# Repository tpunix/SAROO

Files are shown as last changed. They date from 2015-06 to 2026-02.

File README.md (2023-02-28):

### SAROO is a HDLoader for SEGA Saturn.

SAROO是一个土星光驱模拟器。SAROO插在卡槽上，实现原主板的CDBLOCK的功能，从SD卡装载游戏并运行。
SAROO同时还提供1MB/4MB加速卡功能。

--------
### 一些图片

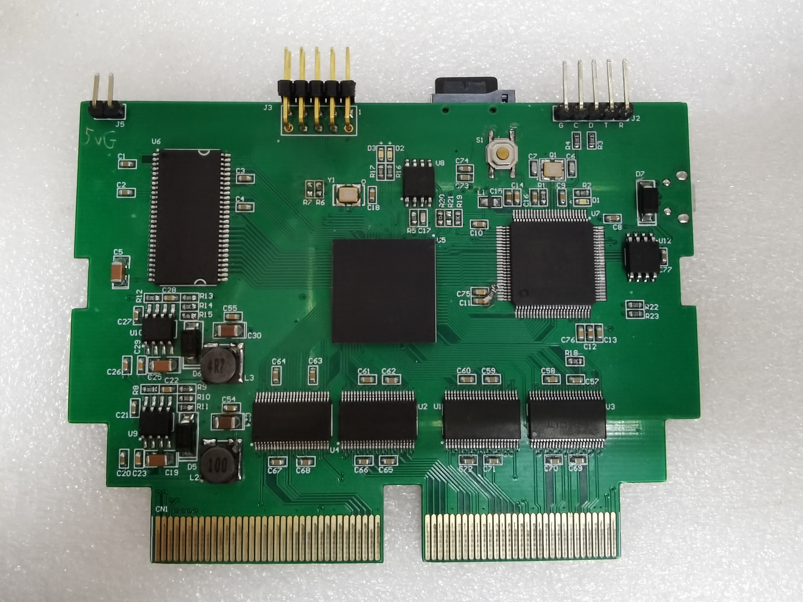
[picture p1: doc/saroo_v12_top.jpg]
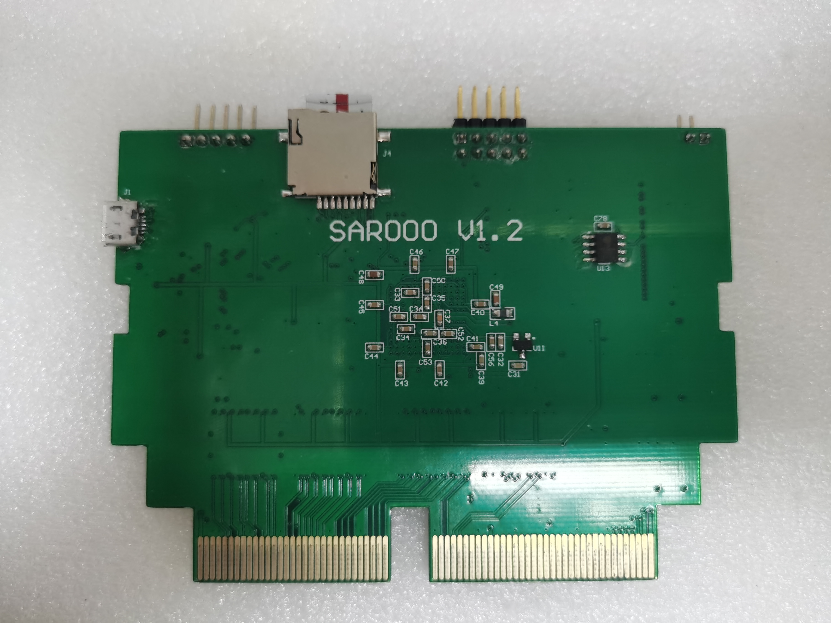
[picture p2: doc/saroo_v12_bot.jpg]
  
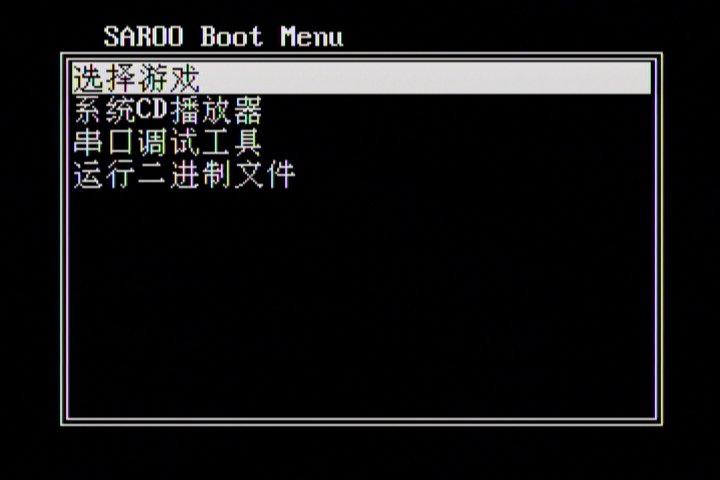
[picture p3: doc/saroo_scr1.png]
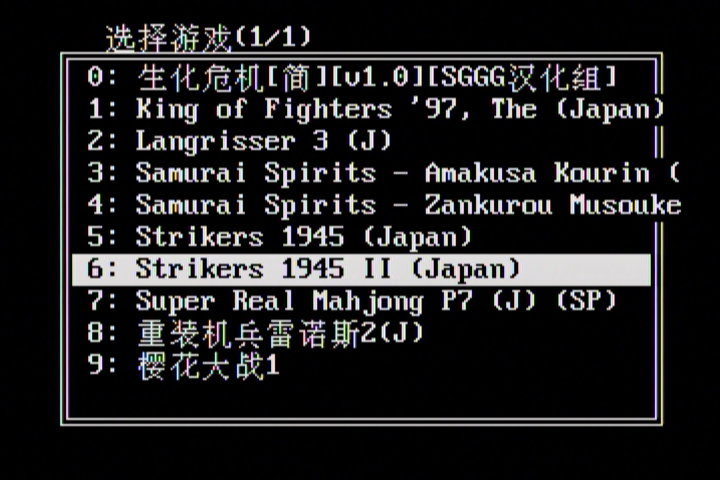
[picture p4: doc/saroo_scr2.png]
  
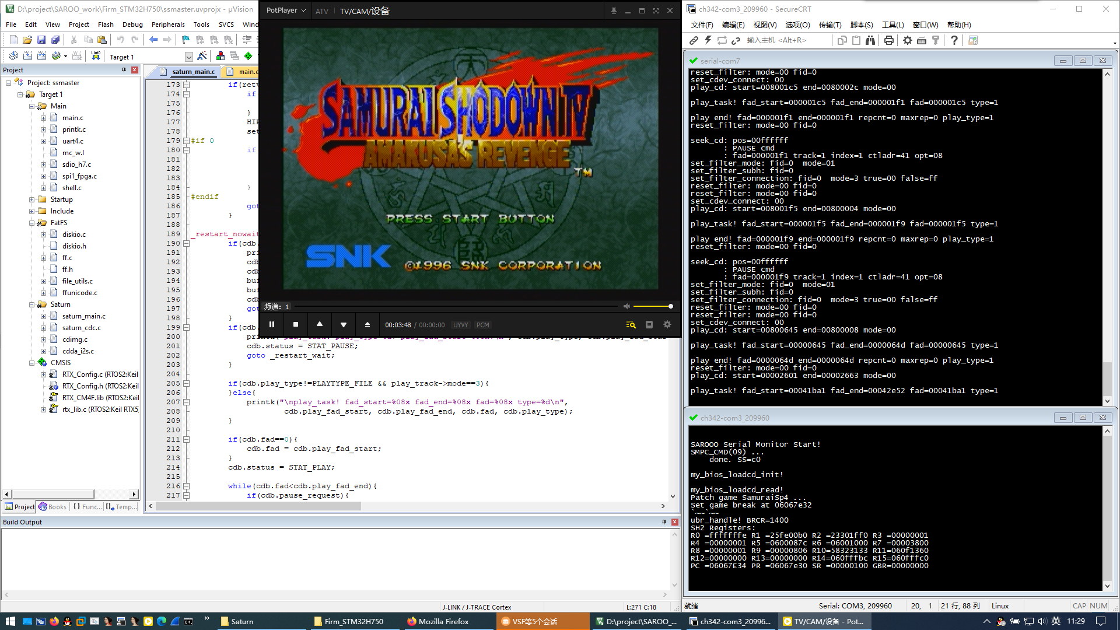
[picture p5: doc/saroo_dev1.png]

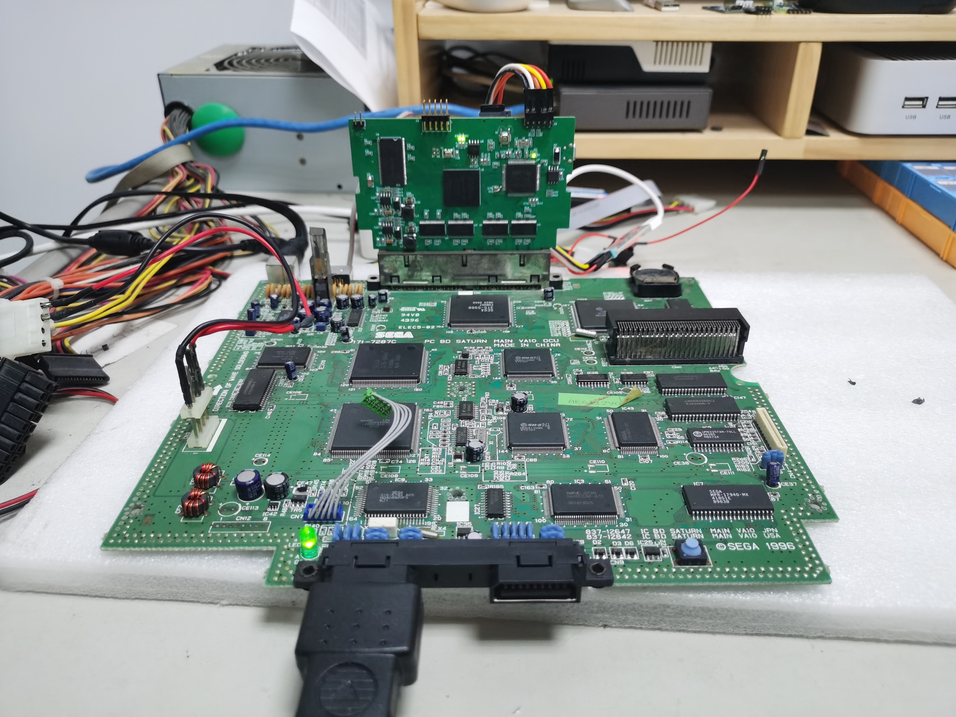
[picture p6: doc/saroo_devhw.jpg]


--------
### 开发历史

#### V1.0
最初的SAROO仅仅是在常见的usbdevcart上增加了一个usbhost接口。需要对游戏主程序进行破解，将对CDBLOCK的操作转化为对U盘的操作。
这种方式需要针对每一个游戏做修改，不具备通用性。性能与稳定性也有很大问题。只有很少的几个游戏通过这种方式跑起来了。
(V1.0相关的文件未包括在本项目中)

#### V1.1
新版本做了全新的设计。采用FPGA+MCU的方式。FPGA(EP4CE6)用来实现CDBLOCK的硬件接口，MCU(STM32F103)运行固件来处理各种CDBLOCK命令。
这个版本基本达到了预期的目的，也有游戏几乎能运行了。但也有一个致命的问题: 随机的数据错误。在播放片头动画时会出现各种马赛克，
并最终死掉。这个问题很难调试定位。这导致了本项目停滞了很长时间。

#### V1.2
1.2版本是1.1版本的bugfix与性能提升，使用了更高性能的MCU:STM32H750。它频率足够高(400MHz)，内部有足够大的SRAM，可以容纳完整的CDC缓存。
FPGA内部也经过重构，抛弃了qsys系统，使用自己实现的SDRAM与总线结构。这个版本不负众望，已经是接近完美的状态了。
同时，通过把FPGA与MCU固件逆移植到V1.1硬件之上，V1.1也基本达到了V1.2的性能了。

--------
### 当前状态

测试的几十个游戏可以完美运行。  
1MB/4MB加速卡功能可以正常使用。  
SD卡支持FAT32/ExFAT文件系统。  
支持cue/bin格式的镜像文件。单bin或多bin。  
部分游戏会卡在加载/片头动画界面。  
部分游戏会卡在进行游戏时。  

--------
### 硬件与固件

原理图与PCB使用AltiumDesign14制作。  
V1.1版本需要飞线才能正常工作。不应该再使用这个版本了。  
V1.2版本仍然需要额外的一个上拉电阻以使用FPGA的AS配置方式。  

FPGA使用Quartus14.0开发。  

Firm_Saturn使用SaturnOrbit自带的SH-ELF编译器编译。  
Firm_v11使用MDK4编译。  
Firm_V12使用MDK5编译。  

--------
### SD卡文件放置

<pre>
/ramimage.bin      ;Saturn的固件程序.
/SAROO/ISO/        ;存放游戏镜像. 每个目录放一个游戏. 目录名将显示在菜单中.
/SAROO/update/     ;存放用于升级的固件.
                   ;  FPGA: SSMaster.rbf
                   ;  MCU : ssmaster.bin
</pre>

--------
一些开发中的记录: [SAROO技术点滴](doc/SAROO技术点滴.txt)

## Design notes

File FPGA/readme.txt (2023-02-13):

V12相对于V11的改动:

1: 移除了qsys相关的组件。qsys自带的SDRAM控制器效率比较低，仅支持单次读写。
2: 实现了一个简单的SDRAM控制器，支持4次突发读。
3: 实现了一个双主端口的总线架构，每个主端口有8字节的cache。
4: 由于CDC缓存放在STM32端，现在由STM32负责填充CDC FIFO。

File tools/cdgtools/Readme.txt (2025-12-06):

cdgplay
-------

简单的cdg文件播放器。将sub文件或cdg文件拖放上去即可播放。
默认是无延时全速播放。在命令行使用，可以附加一个速度参数，将以指定的倍率播放。

cdgfix
------

修复sub或cdg文件中的错误。大多数cdg文件从CD读出后，并没有进行纠错。这将导致播放时出现色块与花屏。
将文件拖放上去即可进行纠错并自动保存。会显示纠错的块的数量与不可修复的块的数量。

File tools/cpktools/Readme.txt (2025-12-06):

cpmk
----

这是一个SEGA cpk视频编码器。

它调用ffpmeg解码输入视频，然后调用windows自带的iccvid.dll编码cinepak视频，最后调用ffmpeg输出cpk格式的视频。
为什么不直接用ffmpeg呢? ffmpeg的编码速度实在是太慢了!!!

因为iccvid.dll只有32位版本，所以本程序与ffmpeg都必须在32位环境下编译。ffmpeg目录下提供了一个最简配置。
由于ffmpeg的cpk muxer有点小问题，这里还提供了一个修改过的版本，请自行替换。

编码控制有两种方式，通过"-q"设置编码质量，或者"-br"设置编码码率。
如果指定"-key"，可以设置关键帧的数量。如不指定，会自动选择合适的key。

cplayk
------

一个简单的cpk播放器。将cpk视频拖放上去即可播放。

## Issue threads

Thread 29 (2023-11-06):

Saroo KK DIY Retro game Store vs Saroo Retro game paradise

Jot666, 2023-11-06:

ShowmanBr, 2023-11-07:
I had purchase 4 units of the saroo from retro games paradise and all these working perfect. I have nothem to say about other stores!

cyo-the-vile, 2023-11-07:
Retro games paradise best vendor.

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

stakeshadow, 2023-11-07:
KK store price cheap. This is good. The quality may not good as the price. The card looks no clear. Same chip are not in one batch. It may second hand. And there are some grinding on top of chip. I wondering the quality may not good. One more issue is that KK store has write Japan in the ali express product photo. He wants to delude buyer. This is not honest.Retro game paradise saroo price may higher. It looks very clean on board. The chip are all same batch and new. The quality is good.

luisredo, 2023-11-07:
I received a unit that does not work, it indicates that the stm32 does not have a bootrom, I am already resolving it with the seller.

Offi1, 2023-11-07:
Had no Problems with seller " Retro game paradise". Updated cartridge around 4 times fine from august when i got it and still running fine.

williamdsw, 2023-11-07:
I 've bought mine on "Retro Game Paradise Store" and I didn't have problems to update firmware.

ShowmanBr, 2023-11-09:
> Also you might want to check this thread: https://bbs1-chinaemu-org.translate.goog/read-htm-tid-129500.html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

Boa noite William!

Vi que você postou aqui um arquivo txt que teoricamente traria mais compatibilidade para alguns jogos. Dentre esses jogo no arquivo vi o kof95, por acaso você conseguiu fazer ele funcionar com essa modificação?

williamdsw, 2023-11-09:
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

Sobre o KOF95, testei aqui e continua não rodando. Acho que só vai rodar quando implementarem o suporte ao cartucho ROm dele.
Sobre o arquivo txt, creio que você esteja se referindo ao **saroocfg.txt**, que é o arquivo de configuração do SAROO aonde é possível definir o idioma, algumas configurações de leitura para cada jogo (A velocidade de leitura do SAROO com o Saturn é alta, e isso causa alguns glitches e bugs em alguns jogos), além de poder definir um valor para memória do jogo (digo no sentido de hackear, colocar cheat).
Deixo um exemplo de como utilizei esse arquivo para rodar um jogo que tava bugado antes.
https://www.youtube.com/watch?v=gXqanPZoGLw

xvortex, 2023-11-09:
There is nothing wrong with KK's version. It has no hardware failures.
As I cleared out in the chat with KK, He's mistakenly flashed version 02 in the FPGA, which made it impossible to make a future updates of its firmware (firmware 02 does not release the flash pins).
Project SAROO is still young and such mistakes are typical for a young project. I recommend that everyone (even those with firmware 04) acquire an altera FPGA programmer (ByteBlasterII) and a stm32 programmer (stlink) in case of unforeseen problems with firmware in the future. Fortunately, both of these programmers are inexpensive.
As for FPGA firmware 02, I recommend updating it to 04 since, in addition to flash programming support, it contains some changes regarding fifo and so on.
I'll try to prepare a simple update package which I will upload soon.

Jot666, 2023-11-09:
I bought the Saroo at the KK retro game store and I didn't see any hardware defects or second-hand components, I found it very similar to the Saroo from the Retrô Paradise game store, I was able to run Metal Slug and Fatal Fury The Final Victory in the Retrô game store Store version I still can't make a saroo comparison because I haven't bought the product from the Retrô game Paradise store yet, the PCB from the KK DIY Retro game Store is in version 1.36 and the PCB from the Retrô game Paradise store is in version 1.35 but both products are Chinese and the only difference is the way they are installed and updated, both are experimental projects, both suppliers are the same thing, the only difference is that one of them chose to do Saroo his way and the other chose to follow the open source , no, I want to create a war here, but I think we should first do tests to highlight its disadvantages and advantages first and then give a verdict, many here are just based on fallacies what counts are the practical results we wouldn't have rockets going into space If we only take into account theories, I'm going to buy the Saroo at the Retrô Paradise game store and I want to make a comparison myself and see which of the two is the most efficient, if anyone here has both Saroo, do rigorous tests between the two everdrives. fair way and bring the results to clear everyone's doubts, if the alternative the Seller's saroo works then I think we are being deceived by unfounded rumors in logistical rivalry and not in real information.

LobAnovich, 2023-11-11:
> ...acquire an altera FPGA programmer (ByteBlasterII)....

На Алиэкспресс полно ByteBlaster (usb версия) и совсем немного предложений именно,якобы, ByteBlaster II. Внешне они ничем не отличаются от тех же ByteBlaster,коих полно. Но вот цена тех,что якобы ByteBlaster II, в пять раз выше. При том,что на наклейках корпусов последних,нет и намёка,на то,что это именно версия 2.
Что это, маркетинговый ход предприимчивых продавцов или это реально разные продукты,на разных чипах,просто с одинаковыми внешними корпусами и наклейками ?

xvortex, 2023-11-11:
Если хотите, чтобы он хоть как-то прошивл, берите самую дешевую версию. Если хотите, чтобы прошивал быстрее, с буферами и как надо, рекомендую версию от waveshare (в белом корпусе) - там все честно - и cpld есть и буфера. По названию выбирать бесполезно. Настоящего оригинального bb2 на али я не встречал.

Jot666, 2023-11-20:
I just want to thank those responsible and the developer, who brought an excellent project to light, but unfortunately people are taking credit for it and I don't agree.  As soon as possible I will buy from the official Paradise store, but I would like the developer to make his own store available to purchase the product in a 100% official way, as we must respect this master behind wonderful projects like saroo, we must be grateful and avoid investing in products that leave something to be desired and that break the developer's rules, in my case I bought it by accident, I ended up buying it wrong, I thought everything was the same, fortunately the saroo I bought is working very well, apart from updating via USB blaster which is more difficult, I don't want to recommend it to anyone, as I would be disrespecting the developer here and I will never do that, my thanks to him if he reads this message.

Closed 2023-11-22.

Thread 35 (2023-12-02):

Sega Saturn VA 0.8 USA is compatible with Saroo?

atds55, 2023-12-02:
I've been having some problems with Saroo on my VA 0.8 USA. The saroo is on firmware 231125, FPGA 05. But the same problem occurred with firmware 231111, FPGA 05. The revision of my saroo is 1.32F.
King of Fighters 96 and 97 have a problem with the sound FX, after some fights the sound has a problem.
Another problem I have is that after leaving some games for about 2 hours and 30 minutes to run alone, they freeze. This happened in Metal Slug, Garou Desetsu 3 (Fatal Fury 3) and Dungeons Dragons Shadow Over Mystara.
So I would like to know if anyone else with VA 0 USA has these problems or if any Saroo developers confirm that VA 0.8 USA is not fully compatible with Saroo.
The seller said that VA 0 is not well supported by Saroo.

https://github.com/tpunix/SAROO/assets/72902338/a5413c84-26f2-4e17-b97d-6b347a03a74a

https://github.com/tpunix/SAROO/assets/72902338/e415b58f-49db-4cf1-a27e-15337be51f62

https://github.com/tpunix/SAROO/assets/72902338/6cec5e20-3c8a-4cf7-a30b-cf48a7098011

https://github.com/tpunix/SAROO/assets/72902338/7c1abcff-c246-4d81-9b3d-502f88b9d7b1

https://github.com/tpunix/SAROO/assets/72902338/2d9f7d6b-e334-44c4-8109-6a0d4e83daa3

tzmwx, 2023-12-02:
Is the motherboard VA0.8?
What is the BIOS version?

atds55, 2023-12-02:
> Is the motherboard VA0.8? What is the BIOS version?

Yes, the board is VA 0.8.
The bios version is 1.00a.

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

atds55, 2023-12-05:
I managed to finish King of Fighters 96 once without having any problems with the game's audio.
I added it to saroocf.txt to run the kof96 game with sector_delay=8000, and that way I was able to finish the game once without any audio problems. Then I will try to finish the game again.

TheUndertakerPoland, 2023-12-05:
Ok thanks, I think it might be related with mobo revision. Defo not bios because I have most popular one 1.01

TheUndertakerPoland, 2023-12-05:
I can confirm changing this value from 4000 to 8000 resolved my sound glitches in UMK3

TheUndertakerPoland, 2023-12-05:
Is there any website how find this game ids to add in config file ?

TheUndertakerPoland, 2023-12-05:
> I managed to finish King of Fighters 96 once without having any problems with the game's audio. I added it to saroocf.txt to run the kof96 game with sector_delay=8000, and that way I was able to finish the game once without any audio problems. Then I will try to finish the game again.

My king of fighters 96 works without any problems. Most problem I have with wwf wrestlemania and mortal kombat games

TheUndertakerPoland, 2023-12-07:
> I managed to finish King of Fighters 96 once without having any problems with the game's audio. I added it to saroocf.txt to run the kof96 game with sector_delay=8000, and that way I was able to finish the game once without any audio problems. Then I will try to finish the game again.

Could you check guardian hero's. ? I have glitches almost instant after start playing

atds55, 2023-12-24:
Does anyone know where I can find the kof97.bin file?
http://bbs.chinaemu.org/read-htm-tid-129548.html

atds55, 2024-03-27:
@tzmwx
Could this be the saroo problem with my Saturn VA 0.8?
With fenrir, this console works perfectly even with games that use a 1MB or 4MB cartridge. The action replay and save cartridge also work well.
Thank you for your attention.

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

czapa86, 2024-04-07:
Same sound glitches on japanese va0 motherboard

tzmwx, 2024-04-09:
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

1.Currently, Saroo does not accept changing games after resetting the console. If you need to change games, it is recommended to use the power on/off mode.

2.I hope you can use my method to test KOF96: Use tape to remove the gold finger on the back of the saroo motherboard, pin 4.5.6 in the lower right corner (pin 7.8.9...can be removed if it is not used), and then insert the Saturn to run KOF96 , the game will have no background music and only hit sound effects. Please test whether there will be broken sound effects.

atds55, 2024-04-09:
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

I placed the tape in the indicated terminals in the same way as you showed in the second photo, and that way I didn't have any problems with the kof96's sound effect. I finished kof96 twice and kof97 once and I had no problem with the sound effect when putting on tape as you indicated.

atds55, 2024-04-26:
Hello. @tzmwx
Did you manage to discover anything with the duct tape test?
Thank you for your attention.

tzmwx, 2024-05-01:
> Hello. @tzmwx Did you manage to discover anything with the duct tape test? Thank you for your attention.

Perhaps it is because the external audio i2s data cable of the early SS motherboard was too close to the scspclk clock line, which may not be able to solve or may require modification of the motherboard to solve the problem.

https://youtu.be/dFbKYMtq3wE?si=qEavJywi40w9-Epi

tzmwx, 2024-05-05:
> Hello. @tzmwx Did you manage to discover anything with the duct tape test? Thank you for your attention.

If you are interested, you can test it according to my method: remove the CD board and use tape to shield the gold finger B6 according to the diagram Any pin, according to the width of the tape, other pins do not matter, ensure B5 is connected to the motherboard.

Reinstall the small board back into the motherboard for testing.
Note that the optical drive cannot be used at this time

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

atds55, 2024-05-07:
@tzmwx
I will carry out the test.
I cut a thin piece of tape and covered only the B6 gold finger, and noticed that the access LED stopped working.
Can I cover just B6 or do I need to cover other pins?

tzmwx, 2024-05-07:
The actual purpose is to cover B7. I said above that starting from B6 is to effectively stick to B7.

atds55, 2024-05-07:
> @atds55 The actual purpose is to cover B7. I said above that starting from B6 is to effectively stick to B7.

Now I think I've covered the B7 (gold finger) pin right.
Thanks.

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

tzmwx, 2024-05-08:
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

Have you tested it? Has the problem disappeared?

atds55, 2024-05-08:
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

Yes, I tested.
I played king of fighters 96 and 97 for a few hours yesterday and today and there were practically no audio problems. There was only a noise like a whistle in the last boss of King of Fighters 96, but this only happened three times, but when loading the next round of the fight, the noise disappeared and the sound returned to normal. But I finished king of fighters 96 2 more times and that noise didn't appear again.

I recorded a video showing the whistle-like noise that occurred in the last boss, but which disappeared when loading the next round. In other parts of the game this did not occur and the game worked perfectly. And as I said before, this only happened 3 times, the other times I faced the boss it didn't happen and the audio worked perfectly.

https://github.com/tpunix/SAROO/assets/72902338/d83a674e-7f14-4ced-8e82-06ed86589707

Thank you for your help.

tzmwx, 2024-05-08:
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

ok
Are you or your friend proficient in using a soldering iron?

atds55, 2024-05-08:
Depending on the type of welding, I can do it.

tzmwx, 2024-05-08:
> Depending on the type of welding, I can do it.

test：
Restore B7, remove C47 （capacitance）

atds55, 2024-05-09:
> > Depending on the type of welding, I can do it.
>
> test： Restore B7, remove C47 （capacitance）
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
RepeatingDigits, 2024-05-18:
I removed C47 on a HST-3200 (J V0) and at first it seemed fine, but after a race of Daytona USA the audio glitch persists.

atds55, 2024-05-19:
> Removi o C47 em um HST-3200 (J V0) e a princípio parecia bom, mas depois de uma corrida de Daytona EUA a falha de áudio persiste.
Did you also have audio problems with the tape on the B7 Daytona terminal?

tzmwx, 2024-05-19:
> I removed C47 on a HST-3200 (J V0) and at first it seemed fine, but after a race of Daytona USA the audio glitch persists.

OK
I hope you can be more specific: has the probability of problems decreased after removing C47?

RepeatingDigits, 2024-05-19:
> > I removed C47 on a HST-3200 (J V0) and at first it seemed fine, but after a race of Daytona USA the audio glitch persists.
>
> OK I hope you can be more specific: has the probability of problems decreased after removing C47?

Not really. After further testing I'd say it's about the same, actually. I just updated to latest firmware, too.

RepeatingDigits, 2024-05-19:
> > Removi o C47 em um HST-3200 (J V0) e a princípio parecia bom, mas depois de uma corrida de Daytona EUA a falha de áudio persiste.
>
> Did you also have audio problems with the tape on the B7 Daytona terminal?

I haven't tried the tape method. If I do that, I'll lose CD Audio, right?

tzmwx, 2024-05-19:
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

2 methods：
saroo A4，A5，A6 no CDaudio

CDmodule B7，CD audio OK

blorp-style, 2024-05-22:
To add, Die Hard Arcade (USA or Japan) has this issue the most consistently out of any game I’ve played, and could be considered a prime test subject.

TheUndertakerPoland, 2024-05-22:
I think wwf wrestlemania from midway has that issue (before mod) all the time after 20 sek of start, very good tester too, each version pal and ntsc, mortal kombat games too, but after few min

Wysłano z programu Outlook dla systemu Android<https://aka.ms/AAb9ysg>
________________________________
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

morpheu, 2024-05-22:
I will try both methods and post here some results also. Question: is there some risk to damage my console attempting doing such hw hacking ?

czapa86, 2024-05-22:
How is it possible that some games are affected but some not. For instance i played hi-octane with cdaudio music without any trouble but Die Hard arcade has glitches almost instantly?

TheUndertakerPoland, 2024-05-22:
After mod? Or before ?

Wysłano z programu Outlook dla systemu Android<https://aka.ms/AAb9ysg>
________________________________
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

czapa86, 2024-05-23:
Before mod. This issiue is inconsostent. One game working good, other not.

TheUndertakerPoland, 2024-05-23:
Yes I agree, worst game for me was wwf wrestlemania completely unplayable with enabled sound. After mod problem solved.

Wysłano z programu Outlook dla systemu Android<https://aka.ms/AAb9ysg>
________________________________
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

blorp-style, 2024-05-25:
I noticed an interesting thing today. The audio distortion is diminished to playable levels if you set the Saturn to mono instead of stereo. Tested this on Die Hard and Virtua Cop 2, which are the worst offenders I’ve seen so far.

TheUndertakerPoland, 2024-05-25:
I'm using mono and have not noticed that, maybe I should use stereo more often

Wysłano z programu Outlook dla systemu Android<https://aka.ms/AAb9ysg>
________________________________
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

blorp-style, 2024-05-25:
> I'm using mono and have not noticed that, maybe I should use stereo more often Wysłano z programu Outlook dla systemu Android<https://aka.ms/AAb9ysg>
> […](#)
> ________________________________ From: blorp-style ***@***.***> Sent: Saturday, May 25, 2024 3:45:31 AM To: tpunix/SAROO ***@***.***> Cc: TheUndertakerPoland ***@***.***>; Comment ***@***.***> Subject: Re: [tpunix/SAROO] Sega Saturn VA 0.8 USA is compatible with Saroo? (Issue #35) I noticed an interesting thing today. The audio distortion is diminished to playable levels if you set the Saturn to mono instead of stereo. Tested this on Die Hard and Virtua Cop 2, which are the worst offenders I’ve seen so far. — Reply to this email directly, view it on GitHub<[#35 (comment)](https://github.com/tpunix/SAROO/issues/35#issuecomment-2130695022)>, or unsubscribe<https://github.com/notifications/unsubscribe-auth/BENW5UONU3AJ2JJLXK7RBBLZD73MXAVCNFSM6AAAAABADWHLTOVHI2DSMVQWIX3LMV43OSLTON2WKQ3PNVWWK3TUHMZDCMZQGY4TKMBSGI>. You are receiving this because you commented.Message ID: ***@***.***>

Strange. Do you have a CR2032 battery installed in your Saturn and you have set the system to mono in the menu settings? Or have you achieved mono by some other method?

TheUndertakerPoland, 2024-05-25:
Mean with mono and stereo I have glitches:) well I had. After tape method with smal cdrom board no glitches at all. I'm using mono in bios settings. Because playing on
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

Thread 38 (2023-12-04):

请教下如何为FPGA下载程序？我使用USB BLASTER遇到一些问题

xiuhui-wang, 2023-12-04:
您好，很抱歉打扰您，我复刻了这个项目，但是在FPGA烧录程序这里遇到了问题。

1.我编译了 FPGA的固件，他提示成功，但是在我点PROGRAMMER按钮后，对话框显示 CANNOT OPEN FILE C:XXXX/FPGA/SSMASTER.CDF。。。。。
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

2. 但我最大的问题，我已经在这里研究了2天了，依然无法下载固件到FPGA中，我短接了 R6与R20，R7与R21是断开的，请问这是正确的么？

3.固件程序是要下载到U8中么？因为我现在不确定是我的FPGA芯片还是FLASH芯片的问题。。。。

很抱歉问这么简单的问题。。。

另外我检查了，3组电压，3.3V 2.5V 1.2V都存在。
也测试了50M的晶振工作正常。。。。

xiuhui-wang, 2023-12-04:
一直显示无法连接，请教一下有什么需要注意的地方的么？

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

xiuhui-wang, 2023-12-04:
我拆除了2个芯片，又外接了 3.3V 与1.2V的电源。。。 目前问题依旧，是不是我的下载器有问题呢？我用他下载 CPLD 是没问题的 可以下载。。。。 目前卡死在这里 几天了
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

tpunix, 2023-12-05:
FPGA固件是写到U8里面的，你把它拆了吗？
另外，先写MCU固件再看看。

xiuhui-wang, 2023-12-05:
mcu的固件我已经写进去了，会有一个 LED 一直闪啊闪的。 U8 拆不拆我都写不进去。。。。 有没有其他手段？ 比如我用 编程器直接写U8。。。。 我的 USB BLASTER 就是 淘宝最便宜的那种, 目前我又订购了一个编程器看看。。。。 目前不确定是 PCB板子，芯片或者编程器的问题。。。
U8 我使用 编程器检测过，虽然是翻新的但是可以正常工作。。。
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

tzmwx, 2023-12-05:
https://github.com/tpunix/SAROO/issues/2#issuecomment-1642263770

这里有用编程器直接烧录U8的固件

tpunix, 2023-12-05:
如果电压正常，晶振正常，还连不上，只能怀疑是芯片或焊接问题。

xiuhui-wang, 2023-12-06:
> 如果电压正常，晶振正常，还连不上，只能怀疑是芯片或焊接问题。

我已经确定我其中的一个 USB Blaster 不能使用，里面是WCH芯片的，上电只有一个LED红灯。虽然他可以下载CPLD，因为我又买了一套开发板。

xiuhui-wang, 2023-12-06:
目前我在研究芯片与焊接问题。。。 解决后我会更新。。。 R6 与 R20 接0R 是正确的吧？

tzmwx, 2023-12-06:
> 目前我在研究芯片与焊接问题。。。 解决后我会更新。。。 R6 与 R20 接0R 是正确的吧？

看我发你的连接，你直接编程器写好U8，看能不能点亮D2

xiuhui-wang, 2023-12-06:
> > 目前我在研究芯片与焊接问题。。。 解决后我会更新。。。 R6 与 R20 接0R 是正确的吧？
>
> 看我发你的连接，你直接编程器写好U8，看能不能点亮D2

我烧录了U8，使用编程器，但是遗憾的是D2 不能点亮。。。。
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

tzmwx, 2023-12-06:
确认烧录了ssmaster.rbf.bin点不亮D2说明可能flasb与fpga有电路不通，或者是FPGA芯片的问题。内存有没有贴回去？

要不就用串口接saroo右上角看一下数据，速度10000，看看报错数据

xiuhui-wang, 2023-12-06:
> 确认烧录了ssmaster.rbf.bin点不亮D2说明可能flash与fpga有电路不通，或者是FPGA芯片的问题。内存有没有贴回去？
>
> 要不就用串口接saroo右上角看一下数据，速度10000，看看报错数据

目前LED的状态 是 LED1 闪几下 然后 红色的 长亮
其他LED 不亮

SSMaster start! 20231203

No SDCARD insert!
disk_read: pdrv=0 sector=00000000 count=1
    retv=ffffffff
disk_read: pdrv=0 sector=00000000 count=1
    retv=ffffffff
disk_read: pdrv=0 sector=00000000 count=1
    retv=ffffffff
disk_read: pdrv=0 sector=00000000 count=1
    retv=ffffffff
Mount SDFS: 00000001

FPGA config done!
FPGA state:
    config done: 1
      init done: 1
         status: 1

disk_read: pdrv=0 sector=00000000 count=1
    retv=ffffffff
disk_read: pdrv=0 sector=00000000 count=1
    retv=ffffffff
disk_read: pdrv=0 sector=00000000 count=1
    retv=ffffffff
disk_read: pdrv=0 sector=00000000 count=1
    retv=ffffffff
disk_read: pdrv=0 sector=00000000 count=1
    retv=ffffffff
disk_read: pdrv=0 sector=00000000 count=1
    retv=ffffffff
disk_read: pdrv=0 sector=00000000 count=1
    retv=ffffffff
disk_read: pdrv=0 sector=00000000 count=1
    retv=ffffffff
NO bootrom file found!
stm32>

tzmwx, 2023-12-06:
红色是D2？
led1开机就闪烁是没有检测到tf卡
看你的串口信息应该是只要将（saroo主页右侧下载的）0.1版的ramimage.bin拷贝到fat32格式的tf卡根目录插上土星开机即可
第一次使用多插拔几次，确保接触良好

此卡有+5V电源输入时，你要确保D1（闪烁或常亮）和D2常亮基本就好了
D3必须进入saroo菜单后才会亮

xiuhui-wang, 2023-12-06:
> 红色是D2？ led1开机就闪烁是没有检测到tf卡 看你的串口信息应该是只要将（saroo主页右侧下载的）0.1版的ramimage.bin拷贝到fat32格式的tf卡根目录插上土星开机即可 第一次使用多插拔几次，确保接触良好
>
> 此卡有+5V电源输入时，你要确保D1（闪烁或常亮）和D2常亮基本就好了 D3必须进入saroo菜单后才会亮

SSMaster start! 20231203

SDCARD insert!
CMD_08: retv=00000000 resp0=000001aa
    V2.0: Yes
    SDHC: Yes
    Name: SS08G
    Blen: 512
    Blks: 15523840
    Size: 7761920 K
CMD_07: resp=00000700
CMD_16: resp=00000900
ACMD06: resp=00000920
CMD13: resp=00000900
Mount SDFS: 00000000

FPGA config done!
FPGA state:
    config done: 1
      init done: 1
         status: 1

这是我目前的状态，D1已经常亮，其他的都不亮。。。 难道是我D2损坏了？

tzmwx, 2023-12-06:
那估计你的fpga芯片问题，或者焊接不良

提醒一下，这卡的fpga和内存芯片绝对不要从tb去购买

xiuhui-wang, 2023-12-06:
> 那估计你的fpga芯片问题，或者焊接不良
>
> 提醒一下，这卡的fpga和内存芯片绝对不要从tb去购买

已经在淘宝购买了。。。。。。 内存芯片 感觉不像是翻新的 FPGA 就是那家13块包邮的 我已经买了5个了。。。。。FLASH SST 那个 是重新打字的。。。。

xiuhui-wang, 2023-12-06:
目前还是不行，插在机器里 跟没插一样，还需要继续寻找问题的答案

tzmwx, 2023-12-06:
点灯顺序D1、D2亮后才有D3亮
建议重新做一下BGA看看，不行就换芯片，换大品牌供应商的芯片

xiuhui-wang, 2023-12-06:
> > 目前我在研究芯片与焊接问题。。。 解决后我会更新。。。 R6 与 R20 接0R 是正确的吧？
>
> 看我发你的连接，你直接编程器写好U8，看能不能点亮D2

OK 我现在写一下

> 点灯顺序D1、D2亮后才有D3亮 建议重新做一下BGA看看，不行就换芯片，换大品牌供应商的芯片

是的目前我正在尝试换芯片，应该是装不装内存芯片都可以 连上 FPGA吧？ 因为我现在不确定他俩哪个又问题 我需要先确认出一个

xiuhui-wang, 2023-12-06:
SSMaster start! 20231203

SDCARD insert!
CMD_08: retv=00000000 resp0=000001aa
    V2.0: Yes
    SDHC: Yes
    Name: SS08G
    Blen: 512
    Blks: 15523840
    Size: 7761920 K
CMD_07: resp=00000700
CMD_16: resp=00000900
ACMD06: resp=00000920
CMD13: resp=00000900
Mount SDFS: 00000000

FPGA config done!
FPGA state:
    config done: 1
      init done: 0
         status: 1

Found Saturn bootrom file.
    Size 00060000
    f_read: retv=0 rv=00060000
stm32> Total discs: 1

这是我目前的状态，我安装了一个游戏，界面是自动出现的么？ 还是需要进行什么特殊的操作？

tzmwx, 2023-12-06:
U7和U13是不需要的，可以不用
D3需要saroo和土星建立通讯后才会亮，D3亮后土星也会进到saroo菜单了

所以现在你要做的是检查为什么没有建立通讯，可能：1卡槽接触不良；2四片电平芯片164245焊接不良或损坏；3FPGA芯片焊接不良或损坏

tzmwx, 2023-12-06:
内存tb购买100%翻新，但不会坏的那么巧导致点不亮屏幕，或者换一片试试看

注意mcu和tf卡里的ramimage.bin用一个版本

用0.1固件测试是只有一个ramimage.bin就能启动，不需要saroo文件夹就可以进菜单

tzmwx, 2023-12-06:
你用统一0.1，先把土星点亮
FPGA先用编程器刷入上面链接里那个04直刷flash芯片版本，
MCU就用0.1固件包里的ssmaster.bin
tf卡里也用0.1固件包里的ramimage.bin

xiuhui-wang, 2023-12-06:
源码在我这面是这样，都是说禁用中断那个返回的类型错误。 我修正了这些 才能编译的下去。。

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

tzmwx, 2023-12-06:
你不用去考虑编译源代码，听我的，你用统一0.1固件，先把土星点亮再说

xiuhui-wang, 2023-12-06:
> 你不用去考虑编译源代码，听我的，你用统一0.1固件，先把土星点亮再说

你的思路是正确的，应该先想办法确认硬件是没有问题。
我使用0.1 的固件中的三个文件
ramimage.bin --- > TF card
ssmaster.bin --- > STM32
SSMaster.rbf --- > U8 SST25VF080 FLASH
现在情况可能不太乐观，还不如之前了，只有一个 LED D1 是亮的。



SSMaster start! Apr 19 2023 22:36:20

SDCARD insert!
CMD_08: retv=00000000 resp0=000001aa
    V2.0: Yes
    SDHC: Yes
    Name: SS08G
    Blen: 512
    Blks: 15523840
    Size: 7761920 K
CMD_07: resp=00000700
CMD_16: resp=00000900
ACMD06: resp=00000920
CMD13: resp=00000900
Mount SDFS: 00000000

FPGA config timeout!
FPGA state:
    config done: 0
      init done: 0
         status: 1

Found Saturn bootrom file.
    Size 00060000

会显示 FPGA 没有设置，然后后面会疯狂的发送数据出来。。。。

tzmwx, 2023-12-06:
u8用我发你链接里的ssmaster.rbf.bin，另外两个对的

xiuhui-wang, 2023-12-06:
> u8用我发你链接里的ssmaster.rbf.bin，另外两个对的
OK 我更改了，现在亮了 两个LED了，开机到9球，串口信息如下：

SSMaster start! Apr 19 2023 22:36:20

SDCARD insert!
CMD_08: retv=00000000 resp0=000001aa
    V2.0: Yes
    SDHC: Yes
    Name: SS08G
    Blen: 512
    Blks: 15523840
    Size: 7761920 K
CMD_07: resp=00000700
CMD_16: resp=00000900
ACMD06: resp=00000920
CMD13: resp=00000900
Mount SDFS: 00000000

FPGA config done!
FPGA state:
    config done: 1
      init done: 0
         status: 1

Found Saturn bootrom file.
    Size 00060000
    f_read: retv=0 rv=00060000
stm32> {00}{00}{00}{00}{00}{00}{00}{00}{00}{00}{00}{00}{00}{00}{00}{00}{00}{00}{00}{00}{00}{00}{00}{00}{00}{00}{00}{000}{00}{00}{00}{000}{00}{00}{00}{000}{00}{00}{00}{000}{00}{00}{00}{000}{00}{00}{00}{000}{00}{00}{00}{000}{00}{
stm32> 00}{00}{000}{00}{
stm32>
stm32>
stm32> stm32> 00}{0}{
stm32>
stm32>
stm32> stm32>
stm32>
stm32>
stm32> stm32>
stm32> tm32>
stm32>
stm32>
stm32> stm32>
stm32>
stm32>
stm32> stm
stm32>
stm32>
stm32> stm32>

好像是FPGA 初始化失败

xiuhui-wang, 2023-12-06:
能给我一个 最新的 TF卡里的固件么？ 我想试试都是新版本 会怎么样

xiuhui-wang, 2023-12-06:
SSMaster start! Apr 19 2023 22:36:20

SDCARD insert!
CMD_08: retv=00000000 resp0=000001aa
    V2.0: Yes
    SDHC: Yes
    Name: SS08G
    Blen: 512
    Blks: 15523840
    Size: 7761920 K
CMD_07: resp=00000700
CMD_16: resp=00000900
ACMD06: resp=00000920
CMD13: resp=00000900
Mount SDFS: 00000000

FPGA config done!
FPGA state:
    config done: 1
      init done: 1
         status: 1

Found Saturn bootrom file.
    Size 00060000
    f_read: retv=0 rv=00060000
stm32> {00}SS CDC: unknow cmd!  CR1=

xiuhui-wang, 2023-12-06:
非常感谢今天的帮助，太不容易了，我得到了界面。 思路是对的仅供参考。谢谢 [tzmwx](https://github.com/tzmwx)

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

tzmwx, 2023-12-06:
最终什么原因总结一下发个流程，便于人家借鉴！

xiuhui-wang, 2023-12-06:
get_auth_status
get_auth_status
get_auth_status
get_auth_status
get_auth_status
get_auth_status
get_auth_status

我高兴的有点太早了。。。。 目前启动不了任何游戏。。。 串口不停的这个。。。 然后会显示游戏启动中。。。。 就这样了

tpunix, 2023-12-07:
> get_auth_status get_auth_status get_auth_status get_auth_status get_auth_status get_auth_status get_auth_status
>
> 我高兴的有点太早了。。。。 目前启动不了任何游戏。。。 串口不停的这个。。。 然后会显示游戏启动中。。。。 就这样了

这是解析cue文件失败了的现象，mcu端游戏镜像加载失败了。

xiuhui-wang, 2023-12-07:
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

是的现在我已经基本能用了，我将继续探索，那个 KOF2 95 您可以运行么？我进去以后 说ROM 卡带错误，让重新插入

Closed 2024-05-24.

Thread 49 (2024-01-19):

KOF95 on v0.3 firm

Jungkyu-Lee, 2024-01-19:
Thank you for letting me run my favorite game, KOF95, in this version up.

When I actually ran KOF95, it ran very well.

However, after 3 or 4 stages, the game resets and jumps to the Saturn CD player screen.

I was wondering if this is just me and if there is a way to fix this.

SONIC3D, 2024-01-19:
There are similar cases for this game reported in local online chating groups with the recent update.

Please try to provide the following information for better reproducing and tracing this potential issue:
1. You console mainboard type.
2. Boot ROM version(if you can see it on the bottom right of the splash screen after the Sega Saturn power-up animation).
3. Console VDP type(Display type: PAL/NTSC).
4. Is the power supply board modded or replaced with any 3rd party model?
5. Is MPEG(VCD) card inserted.
6. Is the joypad Sega original model or 3rd party model(include wireless receiver).
7. Run KOF95 without start the game play, make it enter the demo play loop. Check if it will jump back to the saturn CD Player after several loops.

Agentmanbh, 2024-01-19:
About 7th question, first time I've tested KOF '95, occurs jump back menu during demo play after some few loopings....

deividjaime, 2024-01-20:
I'm having the same problem with my Saturn on Kof 95.
Including with games that work on other Saturn's and don't work well on mine (Resident Evil, Mr. Bones, Deep Fear, etc.).

1 - HST-3220
2 - ver 1.01
3 - NTSC
4 - NO
5 - NO
6 - Original Joy Pad
7 - Yes, and during gameplay too (20 minutes in a demo play loop)

odiaboeeu, 2024-01-20:
I tested it with some sector delay settings from 2k up to 12k and with 8k it was the one that managed to go the furthest missing one fight for the final fight with Rugal, but you can see that the problem is random.

I believe it has something to do with the music or sfx sounds.

With sector delay above 8k significantly increased loading time and also twice occurred to freeze the game on a black screen with sfx sound in a loop.

williamdsw, 2024-01-20:
What version of KOF 95 are you testing?
Note that based on [game_patch.c](https://github.com/tpunix/SAROO/blob/8928b7da7311edb65b7b2d0e9fd1989cc25c4202/Firm_Saturn/game_patch.c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) file, it was only patched for the 2MB version of the japanese version (T-3101G).
**King of Fighters '95, The (Japan) (2M)**

odiaboeeu, 2024-01-20:
The version I used is 3M Hmm I'll try it with 2M

Maybe it would be better to make the same patch for all versions or at least put in the Readme which versions were used in the patch

Marvel super heroes US version could put the same patch they have in the Japanese version

odiaboeeu, 2024-01-20:
Version 2m of the redump gave same problem

odiaboeeu, 2024-01-22:
I've done more tests and it keeps crashing randomly, sometimes even characters from the team that stays in the stage have graphics problems in team China and team Korea

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

odiaboeeu, 2024-01-22:
@tpunix Could you add the European version of kof95 to work on kof95.bin?

tpunix, 2024-01-22:
I'll add it later. This game need debug more and more...

Jungkyu-Lee, 2024-01-22:
1. I tried "King of Fighters '95, The (Japan) (2M)" rom => also jump back to CD player
2. I tried "single play mode" not "team play" => it works nomally

Jungkyu-Lee, 2024-01-22:
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

1. I tried "King of Fighters '95, The (Japan) (2M)" rom => also jump back to CD player
2. I tried "single play mode" not "team play" => it works nomally

Closed 2024-05-24.

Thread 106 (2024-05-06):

Audio glitches

Rabittelong, 2024-05-06:
Buy my saroo from Timeharvest Store updated to firm v0.4 and most of the games start fine but then the sound glitches at random with buzzes and wrong sounds playing, I'm at Japanese VA0 Saturn the weird thing is not all the games are affected by this issue.

tzmwx, 2024-05-07:
It may be that a clock circuit on the VA0\VA0.5\VA0.8 motherboard does not have shielding protection.It is an early motherboard design problem.

Might need to try the motherboard:
Can you take apart a Sega Saturn yourself?
Are you proficient in using a soldering iron?

If you are interested, you can continue to leave a message

Rabittelong, 2024-05-07:
> It may be that a clock circuit on the VA0\VA0.5\VA0.8 motherboard does not have shielding protection.It is an early motherboard design problem.
>
> Might need to try the motherboard: Can you take apart a Sega Saturn yourself? Are you proficient in using a soldering iron?

Sorry no I don't have any skill soldering.

tzmwx, 2024-05-07:
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

Ok
then wait for his test results.
https://github.com/tpunix/SAROO/issues/35

TheUndertakerPoland, 2024-05-12:
I can recommend using tape on on the smal motherboard method. Took about 10 min and fully working. CD ROM not working but audio works from saroo and sound fx without glitches. Tested today.

cpg94, 2024-05-31:
> It may be that a clock circuit on the VA0\VA0.5\VA0.8 motherboard does not have shielding protection.It is an early motherboard design problem.
>
> Might need to try the motherboard: Can you take apart a Sega Saturn yourself? Are you proficient in using a soldering iron?

I have some soldering skills and have had the same issue with sound. What can be done to solve the issue with soldering?

TheUndertakerPoland, 2024-05-31:
I don't think you have to soldiering. Use the trick with tape... if you need optical drive cove just 1 of the pins on the cdrom small motherboard. If drive is not necessary use big piece of tape and cover following pins

czapa86, 2024-05-31:
You can try removing C47 cap but someone reported it didn't change anything.
https://github.com/tpunix/SAROO/issues/35#issuecomment-2119020749

TheUndertakerPoland, 2024-05-31:
That was not working for me. No change

Wysłano z programu Outlook dla systemu Android<https://aka.ms/AAb9ysg>
________________________________
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

cpg94, 2024-06-04:
Yeah I did the tape trick on the CD drive pin in the end and the Saroo is working fine now with not problems. Just wondered if there was a solution that means I can still use my CD drive if needed.

tzmwx, 2024-06-04:
> Yeah I did the tape trick on the CD drive pin in the end and the Saroo is working fine now with no problems. Just wondered if there was a solution that means I can still use my CD drive if needed.

If only the B7 PIN is processed, the CD drive will not be affected. You can still use CD

jerbearwright, 2024-06-07:
I can confirm this works also. I was having the same issues with a MK-80000 US VA0 as recommended  I taped off pin 7 on the small board and all the problems seem to be gone!

rayman-g, 2024-06-18:
> > Yeah I did the tape trick on the CD drive pin in the end and the Saroo is working fine now with no problems. Just wondered if there was a solution that means I can still use my CD drive if needed.
>
> If only the B7 PIN is processed, the CD drive will not be affected. You can still use CD

I have exact issue with sound glitches on va0, is there a video turorial or pictures for taping B7 PIN or schematics?
no soldering things.

Backloggaming, 2024-07-28:
Is there a chance that the sound glitch can be fixed by a new firmware update? I’m using version 1 Japanese Saturn. And I noticed a pattern while playing Asuka 120%. The sound glitches comes on and off depending on what state you are on. It seems affecting the SFX memory channel only and not the BGM.

Backloggaming, 2024-08-02:
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

Here you go… I documented my fix and it works
https://youtu.be/nWIs6qGuU84?si=3QFqxoIHDHmdEmBO

migueljerico, 2024-12-03:
I have a VA0 japanese Saturn which had plenty of audio errors: I had to tape B7 pin on SH-1 CD Rom Drive Board, turn sound to mono...anything helped, because I still had glitches.

But reading another thread here about how to configure Saroo to have default CD speed and more stability, I decided to write sector_delay=6000 and play_delay=30000 on GLOBAL settings via cfg, and voilà, this has eliminated all my problems with no soldering.

Now everything works OK without any glitch, also if I change music to stereo, no sound problems at all.

So I recommend everybody who has this problems to do that and I can now finally enjoy my Saroo.

mdi82, 2024-12-22:
> I decided to write sector_delay=6000 and play_delay=30000 on GLOBAL settings via cfg, and voilà, this has eliminated all my problems with no soldering.
>
> So I recommend everybody who has this problems to do that and I can now finally enjoy my Saroo.

I tried this and I still have audio glitches on mine. Guess I have to stick with tape.

migueljerico, 2024-12-22:
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

Maybe is a combination of both, I still had glitches with only tape but now everything is OK.

Taping B7 pin is easy. Good luck.

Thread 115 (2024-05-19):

Virtual On - Cyber Troopers (USA)

keeper7keys, 2024-05-19:
Tested on FW: 0.4 and 0.5

If a second controller is connected the game glitches: (In my case I'm using a 3D Analog controller on the 2nd port)

https://youtu.be/fXKdJVyCD1s

Regards

keeper7keys, 2024-06-27:
Fixed on FW:0.6.
Thank you @tpunix

Closed 2024-06-27.

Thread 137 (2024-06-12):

DAYTONA USA Championship Circuit Edition (Europe) - hangs in the trademark message

hugobicho, 2024-06-12:
The game DAYTONA USA Championship Circuit Edition (Europe) hangs/freezes in the Daytona USA trademark message. The message is displayed but never disappears.

SAROO Firmware: V0.5
Game ID: MK-81213
Game Version: V1.006

The USA version of the game works fine (MK-81213  V1.001).

tzmwx, 2024-06-13:
This game needs to add a parameter（sector_play=500）. If it still doesn't run, it may be a problem with the image file. Please download it again.

hugobicho, 2024-06-13:
The game "DAYTONA USA" works fine with the parameter "sector_play=500". I tested all 3 regions (Europe, USA and Japan).

The game "DAYTONA USA Championship Circuit Edition", from the USA region, also works fine and doesn't need the "sector_play=500" parameter.

However, the same "DAYTONA USA Championship Circuit Edition" game, but from the European region, has the problem described in my first post. I have tried 3 images (from different sources) of the game for the Europe region and they all have the same problem.

Is it usual to get this different behaviour in the same game but in different regions?
The versions of the game are also different. The American version is V1.001 and the European version is V1.006.

nullpointer-br, 2024-06-13:
Try to clean your slot or saroo pins... european version working fine here.
Daytona USA - Championship Circuit Edition (Europe) (Rev A)
Track 01 CRC - 8E7CCB4D

hugobicho, 2024-06-13:
> Try to clean your slot or saroo pins... european version working fine here. Daytona USA - Championship Circuit Edition (Europe) (Rev A) Track 01 CRC - 8E7CCB4D

It's strange, because I also tried that version and had the same problem. I checked the CRC of the Track 01 file and it's the same.

williamdsw, 2024-06-14:
Tested on firmware v0.4 with Myrient Redump:

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

TrekkiesUnite118, 2024-06-14:
Daytona CCE is a fully PAL optimized game. Are we sure the issue isn't possibly related to Saroo + 50/60 Hz differences?

pplatoon, 2024-06-14:
Hi, my saturn model 1 pal with saroo work fine Daytona USA on a pal system . check clean your slot or saroo pins. Enjoy

hugobicho, 2024-06-14:
I also tried Myrient Redump but the problem remains. Other PAL/EU games, for example DAYTONA USA, work fine.
The problem seems to be with the European version of DAYTONA USA Championship Circuit Edition, as the USA version works fine.

I see a difference in SAROO's behaviour. When playing the USA version, the LED (top right) blinks during the trademark message and the game continues. With the European version, the LED doesn't blink and the image stays on the trademark message forever.

My console is a Sega Saturn Model 2 PAL and I'm using SAROO fw v0.5, but I already tried it with fw v0.4 and got the same result.

SAROO PCB info:
- MCU:  240515
- SS:   240515
- FPGA: 05

Since other games from the USA, EU and even JP regions work fine, I don't think the pins could be the problem... but I'm not an expert either :) So what's the best way to clean them?

pplatoon, 2024-06-14:
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

a hard, half-pink, half-blue eraser

TrekkiesUnite118, 2024-06-14:
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

A Q-Tip and isopropyl alcohol would probably be better. An eraser could possibly leave behind debris which would cause issues if it gets left behind in the cart port.

hugobicho, 2024-06-14:
I cleaned the SAROO pins and they were clean.
I don't understand what could be causing this, since some of you say that can play this game (european version) without any problems.

nullpointer-br, 2024-06-15:
Rename your current save file and let saroo create a new one... maybe it's a load-save issue.

tzmwx, 2024-06-15:
> I cleaned the SAROO pins and they were clean. I don't understand what could be causing this, since some of you say that can play this game (european version) without any problems.

download this image.zip and test it
[image.zip](https://github.com/user-attachments/15846338/image
.zip)

tzmwx, 2024-06-15:
> I cleaned the SAROO pins and they were clean. I don't understand what could be causing this, since some of you say that can play this game (european version) without any problems.

Download this image and test it
[image.zip](https://github.com/user-attachments/files/15846338/image.zip)

pplatoon, 2024-06-15:
With this file on the micro sd it doesn't even show the game selection menu. The Saroo is not able to start if this game as you have sent it to me is put in the folder where it should go. So there is something with this, it's very strange, without the game everything works perfectly.

Enviado desde Correo<https://go.microsoft.com/fwlink/?LinkId=550986> para Windows

________________________________
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

hugobicho, 2024-06-17:
I deleted the *SS_BUP.BIN*, *SS_MEMS.BIN* and *SS_SAVE.BIN* files and the game started correctly (European version used previously). On a second run of the game, it started but, after the trademark message, the warning message "Failed to load the file from Cartridge Memory" was displayed. That message didn't appear the next times I ran the game.

hugobicho, 2024-06-17:
> > I cleaned the SAROO pins and they were clean. I don't understand what could be causing this, since some of you say that can play this game (european version) without any problems.
>
> Download this image and test it [image.zip](https://github.com/user-attachments/files/15846338/image.zip)

I can run this image (very small ISO image) but only after deleting the _SS_BUP.BIN_, _SS_MEMS.BIN_ and _SS_SAVE.BIN_ files.

tzmwx, 2024-06-17:
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

You test it multiple times and inform the test results

hugobicho, 2024-06-17:
Well, I'm not bringing you good news. After running the game a few times the problem comes back, and worse, deleting the _SS_BUP.BIN_, _SS_MEMS.BIN_ and _SS_SAVE.BIN_ files doesn't always work.

There are more cases where deleting the files does not fix the problem rather than cases where it works. It seems that deleting the files and the game work is almost pure luck.

Running my EU game image or the image.zip (ISO file) provided by @tzmwx the result is the same after a couple of times starting the game.

lagious, 2024-06-18:
@hugobicho

Press Z above the game title on the Saru menu to enter Navigator and press C to run

I was in the same situation, but doing this makes the game run normally.

tzmwx, 2024-06-18:
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

Test it by changing the SD card to EXFAT format

tzmwx, 2024-06-18:
post some photos of the saroo and motherboard

tzmwx, 2024-06-18:
Provide a photo of your saroo motherboard.

In addition, describe the entire process in detail, what you did before you were unable to enter the game

hugobicho, 2024-06-18:
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

tzmwx, 2024-06-18:
Repeat the operation. If you cannot enter the game again, please upload the storage file.

tzmwx, 2024-06-18:
@lagious
@hugobicho

same cart same problem?

@hugobicho
Check this game
https://github.com/tpunix/SAROO/issues/139

tzmwx, 2024-06-18:
What version did you purchase ？Elite or Normal？

hugobicho, 2024-06-18:
> What version did you purchase ？Elite or Normal？

Elite version

tzmwx, 2024-06-19:
@lagious
@hugobicho
Can you run kof96, kof97 and metal slug properly?

lagious, 2024-06-19:
@tzmwx

They run normally on my saroo

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

lagious, 2024-06-19:
@tzmwx

I was comparing mine with someone who had no problem running Die Hard Trilogy and found the following difference.

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

The left side is mine (K4S511632B-UC75), and the right side is the one that had no problems (K4S511632D-UC75).

Is it possible that this made a difference?

hugobicho, 2024-06-19:
> @lagious @hugobicho Can you run kof96, kof97 and metal slug properly?

Yes, they run normally, I tested the following versions:
- King of Fighters '96, The (Japan) (1M)
- King of Fighters '96, The (Japan) (4M, 5M)
- King of Fighters '97, The (Japan)
- Metal Slug - Super Vehicle 001 (Japan) (Rev A)

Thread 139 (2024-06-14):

Die Hard Trilogy stopped after the title screen came up

lagious, 2024-06-14:
Die Hard Trilogy stopped after the title screen came up.
(The game stops, but soft reset is possible)
It was the same with JP and US versions, and I haven't tried the PAL version.
I'm using firmware 0.5.

Confusingly, some of my friends who used the same ROM image, the same firmware version, the same kind of SD card, said it working fine. One of them said it didn't work at first, but then it became normal after he deleted the save file. (It didn't work for me)
Of course, there were people who were in the same situation as me.
It's very unstable.

Arnold101knight, 2024-06-16:
only to you. game works fine. use redump bin cue

TrekkiesUnite118, 2024-06-16:
@Arnold101knight
That's not really how this should be addressed. This is a github issues board, not a reddit or 4chan thread. He clearly said he's using the same ROM image that did work for others. So the image may not be the issue here.

@lagious What image was being used?

lagious, 2024-06-16:
@TrekkiesUnite118
At first, I used Redump Sega Saturn's from the Internet Archive. Other than that, I tried two different images, but it turned out the same.

TrekkiesUnite118, 2024-06-16:
Try cleaning the cart to make sure that's not the issue. If that doesn't work then it probably needs looked at by the devs.

lagious, 2024-06-16:
@TrekkiesUnite118
I've tried cleaning with isopropyl alcohol, but nothing has changed. (Additionally, out of the 102 games I have, only this one doesn't work normally.)

I think this is similar to the following issues.
[https://github.com/tpunix/SAROO/issues/137](url)

There was an opinion that it was an issue of load & save, and I have the same doubts. Because, one of my friends said that when he erased the existing save files (SS_MEMS.bin, SS_SAVE.bin) and restarted it, it worked fine.
(Unfortunately, I tried to delete the save file several times, but it didn't get any results.)

tzmwx, 2024-06-16:
> Die Hard Trilogy stopped after the title screen came up. (The game stops, but soft reset is possible) It was the same with JP and US versions, and I haven't tried the PAL version. I'm using firmware 0.5.
>
> Confusingly, some of my friends who used the same ROM image, the same firmware version, the same kind of SD card, said it working fine. One of them said it didn't work at first, but then it became normal after he deleted the save file. (It didn't work for me) Of course, there were people who were in the same situation as me. It's very unstable.

Take a picture of the interface of the SAROO main menu and show me the information at the bottom of your screen

lagious, 2024-06-16:
@tzmwx

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

[saroocfg.txt](https://github.com/user-attachments/files/15856496/saroocfg.txt)

Should I upload save files?

Arnold101knight, 2024-06-16:
> @Arnold101knight That's not really how this should be addressed. This is a github issues board, not a reddit or 4chan thread. He clearly said he's using the same ROM image that did work for others. So the image may not be the issue here.
>
> @lagious What image was being used?

as i said before, shut up clown.

I have misreaded Alien trilogy instead of die hard because was very tired, sorry lagious

tzmwx, 2024-06-18:
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

OK
Can you post some photos of the saroo? The motherboard and the U6 chip (the memory chip in the upper left corner)

lagious, 2024-06-18:
@tzmwx

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

Here you are

tzmwx, 2024-06-18:
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

There seem to be two versions of saroo on this motherboard. What version did you purchase?

lagious, 2024-06-18:
@tzmwx

Are you asking if it's an elite or normal version? It's an elite version (using a new chip)

tzmwx, 2024-06-18:
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

The photo is clear, but the printed font is blurry.

 OK, test it with the following cfg file
[saroocfg.txt](https://github.com/user-attachments/files/15880856/saroocfg.txt)

lagious, 2024-06-18:
@tzmwx

No change. I've tried erasing the save files, but it's the same result.

tzmwx, 2024-06-18:
> @tzmwx
>
> No change. I've tried erasing the save files, but it's the same result.

1Use the cfg file I provided
2Post the file structure diagram of your JP version
3Shoot a video of where it is stuck
4Upload your image cue file

lagious, 2024-06-18:
@tzmwx

Okay, but I'm not sure what No.2 means, can you explain it easily?

tzmwx, 2024-06-18:
> @tzmwx
>
> No change. I've tried erasing the save files, but it's the same result.

You need to copy and paste the contents of the above file into your cfg file or directly test it again with the following file
Test again
[saroocfg.txt](https://github.com/user-attachments/files/15881304/saroocfg.txt)

tzmwx, 2024-06-18:
This is the result of YZB tracking，It belongs to a bug in this game that may occur in certain specific situations. After the next version of the saoo software is released, you can delete the relevant content in the cfg file

Closed 2024-06-18.

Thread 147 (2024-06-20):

Saroo Won't Boot at all Only red lights on top light up

retrojesus, 2024-06-20:
I am using a fenrir ex fat and the build in issue 113, and now after 20 days with it it just stopped working will not load up anything

keeper7keys, 2024-06-20:
Which LED is lit? The one on the left, middle or the right side of the board? Is it constant ON or blinking?

retrojesus, 2024-06-20:
the one on the top left and right not lower left

retrojesus, 2024-06-20:
@keeper7keys what sucks is that it just stopped all of a sudden

Mikeylovesretro, 2024-06-21:
I know you tried reflashing the Sd card but have you tired a different Sd Card all together ?

tzmwx, 2024-06-25:
The two LEDs are always on, or,is the right one flashing?

 If the right LED is flashing, please check the SD card.

 If both LEDs are always ON, please check the card slot interface or SAROO card. You need to borrow a Sega Saturn from a friend to test it.

Based on your description of the LED position, you may have bought a SAROO card without a bevel at the goldfinger.

tzmwx, 2024-06-25:
The two LEDs are always on, or,is the right one flashing?

 If the right LED is flashing, please check the SD card.

 If both LEDs are always ON, please check the card slot interface or SAROO card. You need to borrow a Sega Saturn from a friend to test it.

Based on your description of the LED position, you may have bought a SAROO card without a bevel at the goldfinger.

retrojesus, 2024-06-25:
The two on top are always on tried to reprogram with stnlink but no luck

retrojesus, 2024-06-25:
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

Not sure what you mean by this

retrojesus, 2024-06-25:
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

tzmwx, 2024-06-26:
Your two LEDs light up, indicating that the MCU and FPGA are working properly, while the third LED is dark, indicating that Saroo and Saturn have not established communication. May the problem occur in the interface circuit of Saroo or in the card slot of Saturn? The only way is to find another Saturn and verify which device is causing the problem

TrekkiesUnite118, 2024-06-26:
@retrojesus do you have any other cartridges you can try to verify the Saturn's cart port is working? Like the RAM carts, Backup cart, Netlink modem, Action Replay, Pseudo Saturn, etc.?

retrojesus, 2024-07-05:
> @retrojesus do you have any other cartridges you can try to verify the Saturn's cart port is working? Like the RAM carts, Backup cart, Netlink modem, Action Replay, Pseudo Saturn, etc.?

my 4 in 1 does work got a refund and ordred another one from someone else

WolleB77, 2024-07-27:
I have this problem from time to time, when I touched the cartridge in the slot. Taking the cartridge out and reposition it back in the slot helped every time. My best results are putting the cartridge fully in and then lifting it around 1mm.
Repositioning the cartridge also helped get rid of missing sound in some games (i.e. Necronomicon)

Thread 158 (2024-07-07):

Marvel Super Heroes vs Street Fighter

tronky12, 2024-07-07:
I have downloaded 4 different ISOs They do the same thing  boot to the menu. I've set up saroocnfg.txt and I can't make it work. Any help I would be grateful thanks

goukizero, 2024-07-07:
What console to use? x men vs street fighter has glitches at 50hz, marvel vs breaks at 50hz with the original game

tronky12, 2024-07-07:
Its a v1 model access light and oval buttons, xmen vs street fighter has glitches like you said, no audio, i fix it by setting up the saroocfg.txt and runs perfect

goukizero, 2024-07-07:
What region is your console from?

tronky12, 2024-07-07:
American region

Mikeylovesretro, 2024-07-07:
No issues here.
Marvel Super Heroes vs. Street Fighter (Japan) Saturn ISO - Cdromance ISO
Saroo Elite Version - Firm V0.6
SD Card Formated -ExFat
NTSC Console

tronky12, 2024-07-07:
Did you have to set something up at saroocfg.txt?
I have the Saroo Elite Version firm v 0.6 Too and i download the iso from cdromance too

Mikeylovesretro, 2024-07-07:
> Did you have to set something up at saroocfg.txt? I have the Saroo Elite Version firm v 0.6 Too and i download the iso from cdromance too

No Config was needed. Let me know a few things so maybe we can figure it out. This is the ISO I used https://bityl.co/QvuR

Console type and model
SAROO version
SD card details (brand, capacity, format)
Firmware version
ISO revision (if applicable)

tronky12, 2024-07-07:
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

tronky12, 2024-07-07:
Saroo firmware version 0.6

Mikeylovesretro, 2024-07-07:
Okay, so a couple of things we can try as I just tried on mine. Also, the model number is not clear if you can type it in that be. great. Im not familiar with ImageMate pro model SD Cards. First suggestion is to load the game up on another SD Card by itself and see if you get the same results. Now I know the SD card is formated in Fat32 which I tried seems to have no issue here on my end but you can also try exfat which I personally recommend as its a newer and faster with better performance.

tronky12, 2024-07-07:
I tried in other sd card an get the same issue
Mk-8000  model v1  serial no. 051032296

goukizero, 2024-07-07:
Ask?
Have you tried pulling the cartridge up a little and testing?
The saturn slot is famous for causing problems,
I wouldn't rule out cleaning it to try the easiest thing first.

tronky12, 2024-07-07:
I tried everything and i get the same issue

https://github.com/tpunix/SAROO/assets/174918226/51e29eec-945e-4cc6-aade-f8ac301023e7

Mikeylovesretro, 2024-07-08:
Have you tried formatting in exfat? There was an issue with Fat32 on firm v0.5 so trying to rule out formatting

tronky12, 2024-07-08:
The isos  I use i downloded from Archive.org or cdromance

goukizero, 2024-07-08:
SD or console cartridge connection problem
I can not think of anything else

tronky12, 2024-07-08:
Console Cartridge is clean, today I'm going to try with another brand of SD.

goukizero, 2024-07-08:
with a clean cartridge case:
Marvel super heroes jap happened to me 2 times in a row, I left the intro and the graphics broken

I load the Groove on Fight from saroo and it tells me "there is no ram cartridge"

Move the cartridge a little in its place and everything works fine..... the cartridge holder gives a lot of connection problems

tronky12, 2024-07-08:
Well I'm going to try that too, xmen vs sf gave me glitched and no sound, set the saroocfg.txt and it works perfect, Marvel super heroes American version not work for me but the jap version works perfect and groove and fight works perfect for me , only marvel super heroes vs sf cause me issues

Mikeylovesretro, 2024-07-08:
> Well I'm going to try that too, xmen vs sf gave me glitched and no sound, set the saroocfg.txt and it works perfect, Marvel super heroes American version not work for me but the jap version works perfect and groove and fight works perfect for me , only marvel super heroes vs sf cause me issues

# Marvel Super Heroes (USA)
[T-1214H   V1.001]
sector_delay=6000
play_delay=30000

As that to the config for Marvel Super Heroes

goukizero, 2024-07-08:
in 0.6 to be able to play you have to deactivate the ram, if not before or after the pal crashes, and the usa does not start directly
this would be the arrangement

# Marvel Super Heroes (USA)
[T-1214H   V1.001]
sector_delay=6000
play_delay=30000
M_25897004=8000

# Marvel Super Heroes (pal)
[T-7032H-50 V1.000]
sector_delay=6000
play_delay=30000
M_25897004=8000

tronky12, 2024-07-08:
The japanese version works with no issues for me

goukizero, 2024-07-08:
The jap works both with and without ram without problems, it does not hang

tronky12, 2024-07-08:
Four different SD Cards formatted to ExFAT and Fat32 and Marvel Super Heroes vs SF same issues , i clean the cartridge slot twice , I moved it as I was told in the comments and same result.

ferraca, 2024-07-10:
Do you know if your board is American VA2/VA4 (VA SD)? I have one of these units, and it is not able to run Marvel vs. Street Fighter neither X-Men vs. Street Fighter. Additionally, I encounter problems with SNK games, where some buggy sounds persistently repeat the last SFX sound. This issue occurs both with burned games and original discs. Interestingly, when I try another Saturn unit, the game runs fine.

tronky12, 2024-07-10:
I couldn't tell you, all SNK Games Works Perfect!, the only Capcom game that doesn't work for me is that.

kingchaz1973, 2024-07-13:
Japanese version works fine.

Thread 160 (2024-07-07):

Suggestions For Reporting Game Issues

Mikeylovesretro, 2024-07-07:
It's evident that not everyone uses the same console, SAROO version, SD card, firmware version, or ISO revision. To expedite issue resolution and accurately isolate problems, please provide the following information upfront:

1. Console type and model
2. SAROO version
3. SD card details (brand, capacity, format)
4. Firmware version
5. ISO revision (if applicable)

Additionally, before requesting assistance, consider these troubleshooting steps:

- Update to the latest official firmware.
- Try using a different SD card and format.
- Check previous posts for similar issues.

By providing all necessary details and trying these steps, we can streamline the troubleshooting process and provide more effective assistance promptly.

goukizero, 2024-07-09:
In my case I have a model 2 jap, a pal model 2 with switches (euro/jap 60/50hz) and a model 1 with the switchless mod (jap/euro/usa 50/60hz)
For me the results are always the same, it works the same on one console as another.
I think the most important thing may be the revision of the bios, the only difference between my consoles is for example:
only in the model 2 pal the croc appears without a head, a Sega error more than documented, but the problem comes from the bios

goukizero, 2024-07-09:
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

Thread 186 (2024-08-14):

hissing coming from saroo board

violentcris, 2024-08-14:
Need help
sometimes there is a hissing noise coming from saroo board , specifically i believe is a ferrite core winding with number 100 on it, I disassembled the saturn and the saroo and the noise comes from there, if I connect for example pseudo kai there is no noise at all.
It came with i power the console, not in game, sometimes hissing goes off.
Sometimes i power on and no hissing.
The Chinese seller says it occurs because the Saturn's capacitors "are tired" and it is due to that.
Just in case i use SaturnPSU Rev2.1 12V power supply.

moneytac1, 2024-08-23:
Main motherboard capacitors may be tired as well and saroo may use more processing power or something, may look into mainboard capacitor replacement

violentcris, 2024-08-26:
> Main motherboard capacitors may be tired as well and saroo may use more processing power or something, may look into mainboard capacitor replacement

i have ma model 2 va7, there is a lot of caps, where is the best ones to reeplace (ce23, ce49?) can you help me brother?

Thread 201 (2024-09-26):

No Music in many games if used on Hitachi Hi-Saturn

choconeco, 2024-09-26:
I got a Hitachi Hi-Saturn (MMP-1-1,VA1) and tried to play games using Saroo(v0.6), but the background music does not play in many games. For example, some or all of the music did not play in the following games.The problem has not occurred on the HST-3200, HST-3210, and  HST-3220.I changed ‘sector_delay’ and ‘play_delay’ in saroocfg.txt, but that did not solve the problem.

- Sega Rally Championship Plus [GS-9116   V1.000]
intro and in-race

- Jikkyo Parodius [T-9513G   V1.040]
Konami intro

- Sexy Parodius [T-9514G   V1.040]
Konami intro

- Outrun [GS-9110   V1.005]
all music

If Hi-Saturn is not supported, then this issue is closed.

tzmwx, 2024-09-26:
Possible problems:
1. The HI-SATURN card slot lacks functional pins, and the relevant pins may have been used for the GPS navigation audio channel.
2. The HI-SATURN BIOS may be different.
The above is just speculation. If you are interested, you can open the Saturn shell and upload high-definition pictures of the motherboard, especially the three pin connection lines of the card slot A4\A5\A6 PINS, to see if there is a solution.

choconeco, 2024-09-26:
I cleaned the connector on the Saroo cartridge with ethanol and that solved the problem.
Sorry for the trouble. I will close this Issue.

Closed 2024-09-26.

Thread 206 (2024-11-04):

saroo ultimate mortal kombat 3 loading too fast

Amaru121926, 2024-11-04:
saroo ultimate mortal kombat 3 loading too fast...sound errors occur...

kamugin, 2024-11-08:
Do you try add values in saroocfg.txt ?

# Ultimate Mortal Kombat III
[T-9701H   V1.006]
sector_delay=1000
play_delay=1000

Amaru121926, 2024-11-08:
I just added it's still too fast...

yzbss, 2024-11-08:
Since this game will try to open and run the CD drive before starting, try the following Settings

#Ultimate Mortal Kombat 3 (USA)
[T-9701H   V1.006]
M_0601875A=0009
M_060187AE=0009

Amaru121926, 2024-11-08:
sd card fat32 or exfat formatted?

yzbss, 2024-11-08:
There are several versions of this game, I don't know which version you are using? What version of saroo firmware is used?

Ultimate Mortal Kombat 3 (USA) T-9701H V1.006 19960606

Ultimate Mortal Kombat 3 (Europe) T-25403H V1.007 19960607

Ultimate Mortal Kombat 3 (Europe) (Rev A) T-25403H V2.000 19960804

It has nothing to do with FAX32 or EX FAT format, the above setting applies to the (USA) version and will shut down your cd drive in the game. Using saroo v0.6 on my console will not run the cd drive

Amaru121926, 2024-11-09:
I am using saroo version 0.6 and Ultimate Mortal Kombat 3 (USA)
Can you send a link where to download the appropriate version of the game?

Amaru121926, 2024-11-09:
Using saroo v0.6 on my console will not run the cd drive now but the game's music still doesn't work properly...

yzbss, 2024-11-10:
I am not familiar with the game and am not sure if the music is what I expected, so do you have normal and abnormal game music videos to watch?

Amaru121926, 2024-11-10:
play umk3 from the original cd and then play saroo... then you will understand what I mean...I know this game perfectly.

yzbss, 2024-11-10:
I don't have a cd of the game, I tried the game's music using the mednafen emulator, and it's the same as when I played it on saroo, so I wanted to see what's wrong with the music you're talking about
Is your Saturn model 3200 gray in color?

Amaru121926, 2024-11-10:
My saturn is model 3210 gray

yzbss, 2024-11-10:
At present, this gray version of Saturn and saroo has sound issues, and the firmware has not been fixed, the following is the hardware fix
https://www.youtube.com/watch?v=nWIs6qGuU84

Amaru121926, 2024-11-10:
Unfortunately, this solution does not work, I would rather say that it is about parameters: sector_delay and play delay....

TrekkiesUnite118, 2024-11-12:
> At present, this gray version of Saturn and saroo has sound issues, and the firmware has not been fixed, the following is the hardware fix https://www.youtube.com/watch?v=nWIs6qGuU84

So I think there's a misunderstanding going on here. That issue is specifically related to VA0 and VA0.X revision Saturn's. These motherboard revisions are only found in HST-3200 Model Saturns. The model the user has reported he's using is an HST-3210. While yes this is still a Gray Model 1 Saturn, these debuted with the new VA-SG (VA1) Motherboard revision around June of 1995. This change resulted in some tweaks to the overall case to accommodate some major changes. There's changes internally to handle the Power Supply no longer mounting to the top case, the CD-ROM Block no longer being a daughter board, and the unused fan slots are removed.  Since the user has an HST-3210, the only motherboard revisions he should have are VA1 through VA3. So the issue requiring a hardware modification is unrelated as he doesn't have that Saturn revision.

You can verify this by looking at the Saturn Serial Number Database:
http://evilboris.sonic-cult.net/saturn/index.php?

For the actual issue here I'm guessing the issue has to do with the fact that UMK3 mixes some voice samples into the stage CD audio tracks to save memory. So for example at the start of a match when you hear "Round 1, FIGHT!!!" the word "FIGHT!!!" is actually part of the background music track. So if things aren't loading at the expected speed my guess is that those words are playing out of order, playing over top of each other, etc.

Amaru121926, 2024-11-13:
I don't think there is any misunderstanding here... I hope the game will work properly with the next saroo update...

TrekkiesUnite118, 2024-11-14:
> I don't think there is any misunderstanding here... I hope the game will work properly with the next saroo update...
I hope it gets fixed to. I'm simply pointing out that the issue he was pointing to is completely unrelated as that's not the revision Saturn you have. The misunderstanding was thinking that all Gray Model 1 Saturns are VA0 revision boards.

Amaru121926, 2024-11-20:
Is there already a saroo update that will fix umk3?

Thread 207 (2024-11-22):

Saroo cartridge not recognized

Bomberman94, 2024-11-22:
My Saturn (Victor - RG-JX1) won’t recognize my Saroo cartridge (old one and brand new with HW V1.3.6). Why? I think the PCB of the Saroo is too thin. If I insert my Pseudo Saturn Kai cartridge it works every time and Saroo never. I heard that this a known problem and isopropyl or insert cartridge and lift it a bit and so on doesn’t change anything. Why don’t anyone simply build a thicker PCB for the Saroo?

Here‘s a picture to see the difference (red is Pseudo and the other a Saroo):

[url=https://postimg.cc/yWbd3ZhK][img]https://i.postimg.cc/yWbd3ZhK/IMG-0893.jpg[/img][/url]

tzmwx, 2024-11-29:
Neither of your SAROO cards are recognized?
 I recommend:
 1. Check the Saturn cartridge slot. Because SAROO has more golden fingers than PSKAI.
 2.  Make sure again that the TF card format and files are correct.

tzmwx, 2024-11-29:
The two SAROO cards were working fine before? After you used pskai, they stopped working?

Bomberman94, 2024-11-29:
Correct - Saroo worked perfectly but after inserting PSKAI never again. So I guess the Pins of PCB of Saroo didn’t have contact anymore. I waited, I cleaned and tried it many times but since then only blinking LED‘s…

tzmwx, 2024-11-29:
blinking LED？
Check your TF card, only TF card errors (including not inserting TF card, TF card format error, or TF card file error) will flash LED.

Bomberman94, 2024-11-29:
You‘re right - I prepared a new SD Cart (16GB FAT32) and new files and it worked! In most cases (90%) the menu showed up. I really don’t know why the files on my „old“ cart gets corrupted - will have a look.

But most important: THIS thread can be closed - thanks **tzmwx** for your great support, I really appreciate it!

Closed 2024-11-29.

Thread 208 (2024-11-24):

Games get paused with the D-pad

screwbreaker, 2024-11-24:
Hi,
I'm having an issue on some games. By playing with the D-pad, like a making full circle, the games get paused, like if the start button is pressed.
All the other buttons, or a single direction button is fine.

The games where I'm having this issue are:
Galaxy Fight (EU)
Night Warriors (EU)
Primal Rage (EU)
Street Fighter Collection (EU)
Street Fighter Zero 3 (JP)
Vampire Savior (JP)
Ultimate Mortal Kombat 3 (EU)

Probably there are more.

tzmwx, 2024-11-25:
There is a problem with your controller.
The game program has detected a non-existent button combination: "UP and DOWN", "LEFT and RIGHT".

Please change your controller.

screwbreaker, 2024-11-25:
I have this issue only on this games.
How a defective gamepad can cause this issue only on some fighting game.
Seems too specific to be an hardware related issue.

odiaboeeu, 2024-11-25:
It's a problem with controller, I have a controller that has had this problem since 1996, especially in capcom's fighting games

tzmwx, 2024-11-25:
> I have this issue only on this games. How a defective gamepad can cause this issue only on some fighting game? Seems too specific to be an hardware related issue.

It depends on the design of the game! A plastic sheet with a thickness of 0.5MM can be used to solve the problem.

How to fix it：
First, pull out the DPAD upwards, trim the plastic sheet according to the picture, and install it between the DPAD and the game controller

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

screwbreaker, 2024-11-25:
Ok, I'll try with the fix, and with other gamepads.

Closed 2024-11-26.

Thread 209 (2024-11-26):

VA0 Jap Not even a single game works properly, plenty of sound glitches

Daneeall, 2024-11-26:
VA0 Jap NTSC
BIOS 1.00
Bought an "elite" blue board version of SAROO marked as 1.66 (172-6879-02) 2024-04-18-DJF
A random sound glitches can be heard right after a game start, or few minutes later, and after several minutes game freezes. Any game I tried.
I tried to isolate pin 7 on the CD-ROM controller board (or whatever it is)
like on this video: https://www.youtube.com/watch?v=nWIs6qGuU84
tried different SD cards, different filesystems, different cluster sizes. Tried to disable Phantom modchip. Nothing helps.
You should warn people that SAROO doesn't works with VA0 with **big red text**

tzmwx, 2024-11-26:
https://github.com/tpunix/SAROO/issues/35

Browse here.
After the above methods, the VA0 SATURN can be used normally. If there is still noise, please try cleaning the card slot. Or use a CD to test if the SATURN is functioning properly.

SAROO can be used for the VA0 SATURN. Please confirm if there is any malfunction with the SS or SAROO hardware

Daneeall, 2024-11-26:
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

Can I do something besides cutting traces to test if it really helps? As I said before, isolating pin7 has no avail to me at all. It is highly unwanted to damage a good rare system even in a little reversible way. I cleaned SD card slot, and the console runs CD backups with Phantom chip like a charm, I've never had any DRE, looks like the drive and a whole system is a virgin one.

Daneeall, 2024-11-26:
Maybe lifting of some specific pin will do the job? I have enough soldering skills for that.

redjeff76, 2024-11-27:
watch this video and solve your issue.  No soldering or irreversible modding. ----> https://www.youtube.com/watch?v=nWIs6qGuU84

redjeff76, 2024-11-27:
watch this video and solve your issue.  No soldering or irreversible modding. ----> https://www.youtube.com/watch?v=nWIs6qGuU84

Daneeall, 2024-11-27:
> watch this video and solve your issue. No soldering or irreversible modding. ----> https://www.youtube.com/watch?v=nWIs6qGuU84

Read the firs post here, man.

tzmwx, 2024-11-27:
> Maybe lifting of some specific pin will do the job? I have enough soldering skills for that.

Lift up the 14PIN of IC17 and remove FB8, then directly connect the 14PIN of IC17 and the 2PIN of IC24. The shorter the wire, the better

Daneeall, 2024-11-27:
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
Testing in progress. No problems so far.

ragingchaos, 2025-01-07:
> > Maybe lifting of some specific pin will do the job? I have enough soldering skills for that.
>
> Lift up the 14PIN of IC17 and remove FB8, then directly connect the 14PIN of IC17 and the 2PIN of IC24. The shorter the wire, the better

@tzmwx - Will the method Daneeall has shown in the pictures above allow the VCD card to be used or will it be disabled?

tzmwx, 2025-01-07:
disable

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

Disable

Daneeall, 2025-01-07:
Testing went fine. Reverted changes back and cut the traces. I've no intention on using VCD card, so I'll leave it like this.
Issue closed.

tzmwx, 2025-03-22:
We found a better solution, please contact me(X(twitter):@TZMWXdiyer)

Closed 2025-01-07.

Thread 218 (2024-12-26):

[0.7] No longer boots to menu

JonAbrams, 2024-12-26:
I was able to successfully update from 0.6 to 0.7. I played a few games. Then while navigating the menu, it froze. After power cycling it now boots to the system menu instead of the SAROO. I’ve tried reseating it. The SD card still looks fine on my PC. I tried copying over the 0.7 files again, no luck. Any ideas?

It was working fine for months on 0.6

ragingchaos, 2024-12-26:
Try going back to 0.6.

tzmwx, 2024-12-26:
> I was able to successfully update from 0.6 to 0.7. I played a few games. Then while navigating the menu, it froze. After power cycling it now boots to the system menu instead of the SAROO. I’ve tried reseating it. The SD card still looks fine on my PC. I tried copying over the 0.7 files again, no luck. Any ideas?
>
> It was working fine for months on 0.6

There are three LEDs on the saroo card. How do they flash? You can make a video and upload it here.

JonAbrams, 2024-12-27:
The LEDs is can see are solid green. https://youtu.be/z-rBjhlAW4A

JonAbrams, 2024-12-27:
Overwriting mcuapp.bin and ssfirm.bin from 0.6 didn't fix it.

tzmwx, 2024-12-27:
The LED on the left side of the Saroo card is not lit up, indicating that Saroo and Saturn have not established communication.

Possible reasons include: 1. Poor contact between Saroo and the card slot; 2.Saroo is broken; 3. Saturn card slot or hardware is broken. If multiple plugging and unplugging cannot solve the problem, the only solution is to replace the Saturn for testing

JonAbrams, 2024-12-27:
I actually have a second Saturn (different model, also Japanese), and the problem remains with that one too.

JonAbrams, 2024-12-27:
Also, I never removed the SAROO after I first plugged it in 6 months ago. I just take out the SD card. It's strange it'd have problems the day after upgrading the firmware. Is there any way for the firmware could cause this? I'd be happy to mail it for debugging.

07saga, 2024-12-27:
Clean the SAROO interface and plug and unplug it several times. If it still doesn't work, the FPGA is poorly soldered. You can tell by looking at the outer shell of the card. Many people who bought this card have encountered similar problems.

JonAbrams, 2024-12-27:
Fiddling with the connector eventually worked. Thanks for the support!

Closed 2024-12-27.

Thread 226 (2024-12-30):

Grandia audio issues

KaguraLeader, 2024-12-30:
hi so i have this problem with grandia and its fmv cutscenes where there is this loud static sound (its only in the fmv's)
i already tried the global delay settings in the config file but that doesnt fix it or is broken after the latest update idk for sure

anyways if somebody knows a fix please tell

tzmwx, 2024-12-31:
I tested this game , Iwatched 2 episodes of FMV and no audio issues. You can make a video.

nullpointer-br, 2024-12-31:
No audio noise here... try a different sd card or clean Saturn slot and Saroo pins.

TrekkiesUnite118, 2024-12-31:
Grandia uses a custom FMV codec with ADX audio. So it's very susceptible to anything that could result in it getting less than optimal CD-ROM transfer rates. So anything from a bad burn, a bad SD card on an ODE, or a bad emulation layer could result in this kind of behavior.  It can also be rather erratic.  When creating the English patch I could sometimes get a burn on a cheap CD-R to work one time but not another. It wasn't until I started using good quality CD-Rs that I got consistent results.

So in general there's a lot of factors that could be causing this. Anything that could interfere with the way the game gets it's data from the disc or disc image could cause this.

KaguraLeader, 2025-01-02:
> I tested this game , Iwatched 2 episodes of FMV and no audio issues. You can make a video.

here is the vid it starts doing it at the vulcano zoom
https://drive.google.com/file/d/1P7dmhSnETZdzq54YItFDwh4gOjDSoaDm/view?usp=drive_link

tzmwx, 2025-01-02:
> > I tested this game , Iwatched 2 episodes of FMV and no audio issues. You can make a video.
>
> here is the vid it starts doing it at the vulcano zoom https://drive.google.com/file/d/1P7dmhSnETZdzq54YItFDwh4gOjDSoaDm/view?usp=drive_link

I just tested the English patch version and there was no noise. Try downloading a new version of the image again, or try using a different SD card

KaguraLeader, 2025-01-02:
already tried a new micro sd card (im using a samsung evo) so i switched for testing to a sandisk ultra but same thing

could sound weird but cause im in a pal regio and didnt mod my saturn could grandia be like 1 of those games that dont like running on 50hz

TrekkiesUnite118, 2025-01-02:
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

The version with the SegaXtremem splash screen is the latest version. If you're version doesn't have it then you're playing an old beta build that could have various issues in it.

And yes, Grandia is known to have issues when running at 50Hz especially with the FMV playback.

TrekkiesUnite118, 2025-01-02:
> already tried a new micro sd card (im using a samsung evo) so i switched for testing to a sandisk ultra but same thing
>
> could sound weird but cause im in a pal regio and didnt mod my saturn could grandia be like 1 of those games that dont like running on 50hz

The issue is that you're running it at 50Hz. The game uses a custom FMV codec and is not designed to run at 50Hz. You can see that your video is falling behind the audio and the scratchy audio you're hearing is because it ran out of audio data while still trying to display the current set of frames it's decoding.

KaguraLeader, 2025-01-02:
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

bummer welp im trying to get a jp saturn atm

anyways thx for the help

TrekkiesUnite118, 2025-01-02:
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

You can also install a 50Hz/60Hz switch in your Saturn which should fix it.

KaguraLeader, 2025-01-02:
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

thing is idk if its gonna be a hard thing todo (i know its a model 2) but wel yea if its easy i could do that

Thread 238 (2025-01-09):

No music (i.e.: CDDA tracks) in any game!

VRtinker, 2025-01-09:
Hi,

First I wanted to thank @tpunix and his wits for making this all possible!!

As the title says, I get no CDDA playback on any multi-track game (i.e.: any game with 2 or more audio tracks in the cue sheet). I've tried several games, with varying number of tracks, with tracks combined into a single bin, as well as in .img format and I always get the same result: when I use any game "BGM Test" I can see the Saroo's right LED blinking as I playback a track and stop blinking when I pause it, but no sound is ever output. The same will happen if I boot any game into the Saturn CD Player: the number of tracks will be displayed correctly, it will "play/skip/seek" from track 2 on going, but still no sound. Other then the missing music, every game behaves as expected. I tried fw 0.5, 0.6 and 0.7 without noticing any difference. I also tried microSDs of varying capacity formatted both FAT32 and exFat (with varying cluster sizes). Lastly, If I boot into the Saturn CD Player a single audio track game like Akumajou Dracula X for example, the music track will play no problem!

I should say that all these game files work/sound correctly when emulated.

My Saturn (Model 2 VA6) plays Audio CDs just fine.
My Saroo (the board is a V1.66 MFR ~04-2024 - if it means anything, it's from Ali) has never failed to boot so I presume the Saturn's cartridge slot is in good condition (I also stripped down the console and all looks good up close).

I bought my Saroo without a microSD card, so the first time I've boot it up it was using fw 0.7. Since the instructions to prepare the SD card appear to not ask to put any files in the UPDATE folder, I am not sure if my Saroo is running the latest and greatest (in other words, I have never seen the "Firmware Update" menu). However I do have confirmation that I am running fw 0.7 because I can see the game covers. While I do understand that the fw is being read as an "app" from the SD card at boot each time so to speak, should the hardware be flashed/updated as well?

I hope someone in the know can help me out, cause this is driving me 🔩🔩  😃

Cheers

tzmwx, 2025-01-09:
When SAROO is started, CDDA data is transmitted through the three pins (A4, A5, A6) on the left rear of the cartridge. If any of them is in poor contact, there will be no CD music. It is recommended to check here.

It is recommended to plug and unplug the cartridge several times and clean the cassette and slot to ensure good contact.

In addition, the internal circuit failure of Saroo or Saturn may result in no CD music. If possible, you need to use another Saturn for testing.

tzmwx, 2025-01-10:
I just noticed your words：

> If I boot into the Saturn CD Player a single audio track game like Akumajou Dracula X for example, the music track will play no problem!

Maybe the reason is that your disc image is wrong? Please confirm that the image is in CUE/BIN (or CUE/IMG) format and upload your CUE file

VRtinker, 2025-01-11:
@tzmwx

Thank you so much for sharing your knowledge! Following your advice, I checked for continuity on the A4-A5-A6 pins, but was getting a beep reliably from the Saroo to the cartridge slot pins and the motherboard test points

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

so I followed the signal on the top side of the board, and that's where I found the problem: some corrosion was creating a break right after the signal from A5 was carried to the top side

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

this was preventing it from reaching its next node

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

After some consideration I decided to jump a wire directly from the the cartridge slot pin that A5 engages (3rd pin 2nd row) to the next node on the top side of the motherboard

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

CDDA tracks now play and sound perfectly! 🤓

My next issue is no game requiring a ram-cart works 😄 (I'll get a separate discussion going for that)

Thanks again for the invaluable help!

Cheers,

VRtinker, 2025-01-13:
Looks like I need to type in a new message to close the ticket, so here it is!

Thanks again for pointing me to the solution!

Closed 2025-01-13.

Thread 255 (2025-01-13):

RAM Cartridge emulation not working in any game!

VRtinker, 2025-01-13:
Hello (again!),

As the title says, I get nothing (by that I mean every game will show their "RAM missing" error screen if/when they have one) when I try to load a game requiring 1/4MB RAM Expansion. I tried with and without exmem_1 and exmem_4 in the saroocfg.txt, but I always get the equivalent result of a RAM card missing.

Since for my previous issue #238 (TLDR I wasn't getting any BGM in game) the problem turned out to be corrosion down the path of one of the cartridge slot pins travelling through my Saturn, I was wondering if this time as well there are any specific pins responsible to "tell the Saturn" a RAM cartridge is present. Perhaps there are still broken lines on my Saturn that I missed and I could/should restore?! What do you recommend?

Cheers

TrekkiesUnite118, 2025-01-14:
If you have other cartridges to test with that would be a good way to rule out if it's the cartridge or the cartridge slot.

VRtinker, 2025-01-14:
@TrekkiesUnite118
I don't have any other cartridges to test. If you take a look at my previous issue, you'll see that I am dealing with a Saturn that, at least then, had one cartridge slot pin that wasn't connecting all the way to where it needed to get (which I fixed by jumping a wire from the slot pin to the next junction after the signal interruption). In the same vein, if this is not a software/configuration issue, I would think there might be a similar problem with another pin losing it's signal along the way, since the slot itself is connecting to the cartridge securely. In my other post @tzmwx suggested to check pins A4-A5-A6, and indeed the signal wasn't getting all the way to where it needed to get for pin A5, so if anyone knows what pins on the Saroo are responsible for making the Saturn acknowledge the presence of a RAM Cart, that's likely where my troubleshooting should start. Hopefully someone can chime in with that info!

Cheers

tzmwx, 2025-01-14:
There are many reasons that may cause this failure, such as the saroo card using a refurbished memory chip, or a problem with the Saturn circuit board or slot. You may need to check them one by one.

If you need a suggestion, you can check A47pin first.

VRtinker, 2025-01-14:
> There are many reasons that may cause this failure, such as the saroo card using a refurbished memory chip, or a problem with the Saturn circuit board or slot. You may need to check them one by one.
>
> If you need a suggestion, you can check A47pin first.

Thanks! I'll check pin 47 right away! For your reference, my Saroo is supposed to be an "Elite" version, so in theory it should contain no refurbished components. I'll see what I get from pin A47 and report back.

Cheers

VRtinker, 2025-01-14:
@tzmwx So I checked pin A47 and it seems to be ground point! I'm not seeing a problem there (unless it's not supposed to be a ground point at all!) and I'm able to verify continuity from the Saroo cartridge down to the front side of the Saturn motherboard (so, once again, the slot itself seems to be doing it's job). The only thing I see that may be out of place is that my Saroo has pin A47 and it's adjacent pin (A46?) in a separate layout, whereas I see pictures of other Saroo boards where the 2 are combined together (which also alters the actual pin number as well). Please take a look at the pics of my Saroo below to see what I mean (and in case you can spot something glaringly wrong!)

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

I can only count 48 populated A-pins on my Saroo, but the pic you attached in my previous post, indicated A67 as the last pin in the row, so I suspect that I've been probing the wrong pin due to this. For fun, I counted 20 pins (populated or not) back from the last one and tested that resulting pin. I get continuity for that as well down to the bottom-side of the Saturn: despite the fact that the corresponding top-side of that test point is underneath the Sega 315-5966 chip (IC5), I'm still able to grab back the signal on pin54 of the IC. Needless to say, I'm at a loss! Do you have anything else for me to try?

Cheers

tzmwx, 2025-01-14:
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

VRtinker, 2025-01-15:
Thanks!

Unfortunately, while I was waiting for a reply, I went ahead and tested that pin, as well as most of the surrounding ones that end in the IC5 and they all give me continuity. While probing around I found that I get continuity where I shouldn't (like across the contact points of CE38 which is an unpopulated cap - on all motherboard revisions from what I can tell) when the clock battery is plugged in. That doesn't sound right to me, but maybe it's normal. Is it though? I get that the battery will push some voltage to the motherboard, but should it cause a short on a component (pads of a component, in this case)? I haven't actually done any tests to run RAM-requiring games without the clock battery inserted, so maybe it's worth a try. But it would be nuts if they were to work somehow.

I am more at a loss than I was before!

tzmwx, 2025-01-15:
Don’t edit cfg.

Suggestion:
You need to confirm that all Saroo pins are connected to the pins of the Sega Saturn chip uniformly. Special attention: To avoid card slot malfunctions, it is necessary to test “Saroo pin - Saturn IC pin”.

or Find another Saturn and confirm if it's a problem with Saroo or Saturn.

VRtinker, 2025-07-27:
@tzmwx you are an absolute legend! I saw your suggestion to add a 10K resistor on the Saroo board (issue #326) and yep, it solved my issue as well. I can't thank you enough! Cheers

Closed 2025-07-27.

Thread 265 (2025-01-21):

Game sometimes stuck on loading screen

sakaiza, 2025-01-21:
[Street Fighter Collection]
CD 1 Super Street Fighter 2X
Saroo firm v0.7
V-Saturn

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

It can happen also on Sega-Saturn

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

tzmwx, 2025-01-24:
Perhaps due to 'disk fragmentation', please reformat your SD card and copy the game image again

sakaiza, 2025-01-26:
My saroo died the day of your response. I was playing Street Fighter Zero 3 on the Sega Saturn ( Not the V-Saturn ). The game froze and the saroo was never recognized ever gain by the console. It'd just boot to the cd-player. I tried everything I can. Making another SD cards with different cards to no avail. I've never had any problem with Street Fighter Zero 3 on the V-Saturn.
I  got a refund for the bricked saroo. And waiting for another one from a different seller.  The bricked model was 1.66 , the one I'm waiting for is V1.3.5F.  I think I'll never used again the saroo on the first saturn model and stick to the v-saturn or the V2 saturn (white model).

sakaiza, 2025-01-26:
For troubleshooting sake, I'd add a photo of the bricked saroo :

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

As you can see , 2 led on steady red , the 1st led on the left no light.

I noticed that save files were created when I inserted the saroo with new sd card...

tzmwx, 2025-01-26:
Clean Saroo's golden finger

retrofank, 2025-02-03:
Fine here on 0.7 FW - JP VA19 using redump Bin & Cue dump on a Genuine 32GB Sandisk mSD card.  A lot of issues can be HW related i.e dirty contacts, bad SD card (fake) too much fragmentation, using bad dumps of games.

sakaiza, 2025-02-03:
I have a new Saroo now with same SD card as before (512GB Sandisk). I only play on my V-Saturn since I bricked the other Saroo on my VA0 and I'm scared to test it again.  No more loading bug in Super Street Fighter 2X  ,  I've finished several time Street Fighter Zero 3 (one freeze and some glitch (invisible final boss)) but it's all right.  I've even launched Lunar MPEG with the pseudo kai feature of the Saroo. Maybe the other Saroo was defective or dirty but the one I got now seems better.

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

retrofank, 2025-02-03:
Least you have it sorted now, must have been a dodgy Saroo PCB.

Closed 2025-02-03.

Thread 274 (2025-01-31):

SAROO doesn't work with the CleanPower mod + Phantom Universal installed in the Saturn

MoggmentuM, 2025-01-31:
As of recently, I swapped out my PSU with the CleanPower USB-C psu in a Saturn console that had a Phantom Universal modchip installed previously. When booting the Saturn, it gives just a rolling signal as picture and I see that none of the LEDs are blinking on the SAROO. I've tested with a stock Japanese Saturn and the SAROO works without any problems. I tried to use a Action replay cart aswell in my modded Saturn and that cartridge is still working in it.

SW3PO, 2025-02-01:
I had exactly the same issue. Turned out that I had a faulty cap pulling the voltage to ground when attempting to use the Saroo (which I believe uses different pins from the action reply)
Fresh recap and all was solved for me.

s4rg33, 2025-02-08:
> As of recently, I swapped out my PSU with the CleanPower USB-C psu in a Saturn console that had a Phantom Universal modchip installed previously. When booting the Saturn, it gives just a rolling signal as picture and I see that none of the LEDs are blinking on the SAROO. I've tested with a stock Japanese Saturn and the SAROO works without any problems. I tried to use a Action replay cart aswell in my modded Saturn and that cartridge is still working in it.

I have the same issue, but there is a workaround, turn on the sega saturn without the saroo, wait a couple of seconds, then turn it off, insert the cart and turn it on again. I did mention this to Luke from Retrosix so maybe next revision of the clean power will have this issue fixed

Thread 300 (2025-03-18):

Faulty Saroo, serial logged, any possible fix?

kreativf, 2025-03-18:
I just got myself a Saroo, but I guess it's faulty.
When booting the D2 LED stays on and the D1 LED keeps flashing in a loop of 7 or 8 flashes.
At first I thought this might be an SD card issue, so I tried out 3 different cards, formatted them with FAT and exFAT and tried out different software versions. This didn't help.
So I picked up my soldering iron, and connected the Saroo to serial port to find out what the issue might be.
In my case it's the J2 port (1-RX, 2-TX, 5-GND), as per usual the Saroo TX needs to be connected to RX on the receiving side.
The settings I found to be working were 1000000 baud, 8N1

The next part are the logs from the serial port:

```
SSMaster start! 20231111

SDCARD insert!
CMD_08: retv=00000000 resp0=000001aa
    V2.0: Yes
    SDHC: Yes
    Name: SD
    Blen: 512
    Blks: 122138624
    Size: 61069312 K
CMD_07: resp=00000700
CMD_16: resp=00000900
ACMD06: resp=00000920
CMD13: resp=00000900
sd_cmd: irq timeout! CMD=00000151 STA=00081040
disk_read: pdrv=0 sector=00000000 count=1
    retv=ffffffff
sd_cmd: irq timeout! CMD=00000151 STA=00081040
disk_read: pdrv=0 sector=00000000 count=1
    retv=ffffffff
sd_cmd: irq timeout! CMD=00000151 STA=00081040
disk_read: pdrv=0 sector=00000000 count=1
    retv=ffffffff
sd_cmd: irq timeout! CMD=00000151 STA=00081040
disk_read: pdrv=0 sector=00000000 count=1
    retv=ffffffff
Mount SDFS: 00000001

FPGA config done!
FPGA state:
    config done: 1
      init done: 1
         status: 1

sd_cmd: irq timeout! CMD=00000151 STA=00081040
disk_read: pdrv=0 sector=00000000 count=1
    retv=ffffffff
sd_cmd: irq timeout! CMD=00000151 STA=00081040
disk_read: pdrv=0 sector=00000000 count=1
    retv=ffffffff
sd_cmd: irq timeout! CMD=00000151 STA=00081040
disk_read: pdrv=0 sector=00000000 count=1
    retv=ffffffff
sd_cmd: irq timeout! CMD=00000151 STA=00081040
disk_read: pdrv=0 sector=00000000 count=1
    retv=ffffffff
NO mcuapp file found!
```
It's the same with all my SD cards. Could somebody please tell me what this means and whether this is fixable?

Thank you for your time and help!
Greetings,
btgdelta

yzbss, 2025-03-18:
Here's mine, it looks like your sd card didn't go through initialization unrecognized
```
SDCARD insert!
CMD_08: retv=00000000 resp0=000001aa
    V2.0: Yes
    SDHC: Yes
    Name: 00000
    Blen: 512
    Blks: 62521344
    Size: 31260672 K
CMD_07: resp=00000700
CMD_16: resp=00000900
ACMD06: resp=00000920
CMD13: resp=00000900
Mount SDFS: 00000000

SSMaster start! 20241115

FPGA config done!
FPGA state:
    config done: 1
      init done: 1
         status: 1

Found MCU app file.
    Size 0000f050
    f_read: retv=0 rv=0000f050
Start app ...        `

yzbss, 2025-03-18:
Boot without inserting an SD card
````
SDCARD insert!
disk_read: pdrv=0 sector=00000000 count=1
    retv=ffffffff
disk_read: pdrv=0 sector=00000000 count=1
    retv=ffffffff
disk_read: pdrv=0 sector=00000000 count=1
    retv=ffffffff
disk_read: pdrv=0 sector=00000000 count=1
    retv=ffffffff
Mount SDFS: 00000001

SSMaster start! 20241115

FPGA config done!
FPGA state:
    config done: 1
      init done: 1
         status: 1

kreativf, 2025-03-18:
Interesting! This looks a bit like it has no problem reading the sd card initialization data, but then gets errors when it tries mounting it. Very weird, I'll try resoldering the sd card slot, maybe this will help.

kreativf, 2025-03-21:
I couldn't find any fault in the wiring, so I'll just return it so seller as faulty.

Closed 2025-03-21.

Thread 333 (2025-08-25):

Hang-On audio issues

4lexei, 2025-08-25:
Hi friends, thanks for the amazing work on Saroo!

VA0.5 JAP console with disabled PIN B7.
Modified Saroo cartridge by adding an extra pin.

Hang-On (USA, EUR, and JAP) has massive audio issues on all my consoles (I'm mainly mentioning the VA0.5 because it's the one I use the most, but it also happens on VA SD PAL consoles). I'd like to know if you're also experiencing these issues: crackling in the audio tracks and, after a while, corrupted FX sounds (especially if you pause and restart the race).

Thank you.

4lexei, 2025-08-25:
Hello! I've been doing more testing on a VA 0.5 and two VA PAL SD consoles (European VA3, I guess). I've improved my previous Saroo cartridge modification by shortening the cable.

However, the result is the same. Hang-On has very annoying noises that get worse as you play. There are other games with minor issues, such as Alien Trilogy (a small "click" is heard every time I fire).

I've also tried reducing the loading speed, but this doesn't fix it.

At this point, I suspect my cartridge might be the culprit. Tomorrow I'll cut traces from the VA 0.5 to do more testing.

4lexei, 2025-08-26:
I disabled pins 4, 5, and 6 with tape on the Saroo PCB.

Now, without CD music, Hang-On works fine on my japanese and european consoles; all the sound effects seem to be clear, with no clicks, crackling, or glitches.

Tonight I'll modify the main board of my Japanese console (VA0.5).

4lexei, 2025-08-26:
Well, I've hit a wall; my knowledge doesn't allow me to go any further.

I've modified my VA0.5 console with the information I gathered from Github. Photos of my modification:

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

Unfortunately, the result is the same: Hang-On suffers from severe audio issues (crackling audio tracks and corrupted FX sounds, especially when restarting the race).

- Disabling pin B7 on the SH1 board didn't work.

- Modifying my cartridge's PCB to add an extra pin didn't work either.

- By covering the cartridge pins responsible for CD music with tape, I apparently don't hear any errors in the sound (but I would like to play with audio tracks, this doesn't work for me).

- Lifting the CLK pin on the sound chip and connecting it with a cable to FB8 didn't work either.

Thanks everyone. In the meantime, I'll play other, less problematic games.

4lexei, 2025-08-29:
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

Thank you very much, but it didn't work either.

I suspect that some Saroo cartridges on Aliexpress are currently experiencing issues, but perhaps some users aren't complaining because they haven't done enough testing or aren't familiar with the Saturn hardware, so these issues could go unnoticed (just my theory).

Up to this point, I've performed the following operations to try to correct Saroo's issues:

- I disabled pin B7 on the daughterboard (the SH1 board)

- I modified my Saroo cartridge's PCB by adding a new pin to U1)

- I also added the suggested 10k resistor to the Saroo PCB (by the way, thanks to this, I don't understand how, another Saroo cartridge I received defective last month started working; unfortunately, I now have two Saroos with exactly the same audio issues hahaha)

- I swapped CD-ROM drives and ribbon cables. I even used brand new, much shorter ribbon cables to ensure a stable, interference-free connection.

- I checked the Saturn power supplies by installing new capacitors.

- Of course, I cleaned the contacts, pins, and slots with alcohol and electronic circuit cleaning products.

- I've tried SD cards from Sandisk, Toshiba, Lexar, and Amazon Basics. Formatted in ExFat and FAT32.

- I've tried previous firmwares.

- I moved the console to another room to connect it directly to a CRT display, thus avoiding my usual device chain (PC, capture card, GBS-Control, etc.), and powered it using a UPS battery that provides a clean sine wave.

And the big question is... Why do my two VA PAL SD consoles have exactly the same sound problems as the VA0.5?

I need to rest and think. Of course, all my CD games work perfectly. Thank you!

tzmwx, 2025-08-29:
Test:
Edit SAROOCFG file, add delay parameters under [GLOBAL]

sector_delay=8000
play_delay=20000
pend_delay= 10000

 Delete other parameters related to Hang-ON GP game

4lexei, 2025-08-30:
Guys, I've found someone with the same kind of audio issues. From what I've been able to find out, he's been working on creating a compatibility list for some time, and his console is a Tectoy VA13.

You can hear an audio "pop" before the first turn (2:09), when he is changing the camera view: https://www.youtube.com/watch?v=95gDSPFlqWY&t=129s

There are usually fewer audio glitches in time trials, while they are more common during races.

4lexei, 2025-08-30:
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

Great research!

Watching those videos, I can hear a lot of popping sounds, the exact same "pops" in the audio I hear on my consoles. I only played Hang-On back in the '90s when I rented it as a kid, so I didn't remember all these audio issues.

If you agree, I'll close this thread, as these issues already existed in the retail game, and Saroo doesn't seem to be making them worse.

Thank you all so much for your help!

4lexei, 2025-08-30:
Although this thread is about Hang-On, I want to clarify that I just ran a check on Alien Trilogy. In a previous post, I mentioned that this game also had some audio issues, but my original, genuine copy (EUR) also has the same "oddities."

Every time you fire the gun, you can hear a small "click." And the shotgun's sound is very "crunchy". Therefore, Saroo's behavior with Alien Trilogy seems normal. I apologize if I have caused confusion.

And now, I'm closing this thread. Thank you!

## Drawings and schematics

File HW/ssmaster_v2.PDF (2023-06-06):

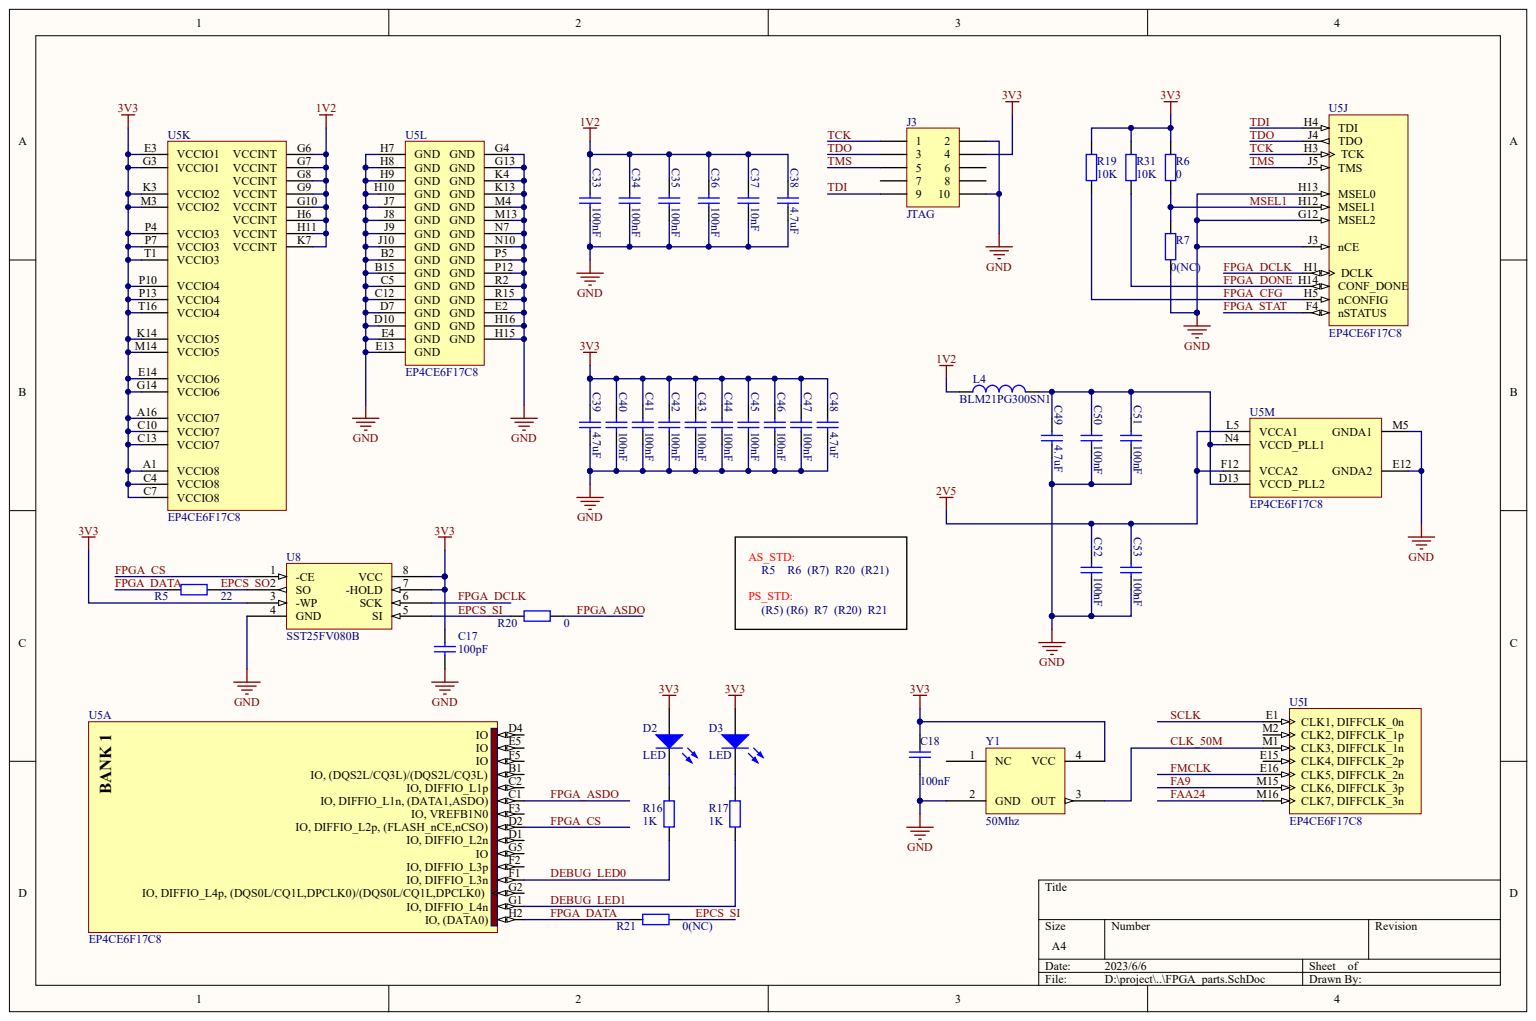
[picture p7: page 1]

VCCIO6 E14

VCCIO7 A16

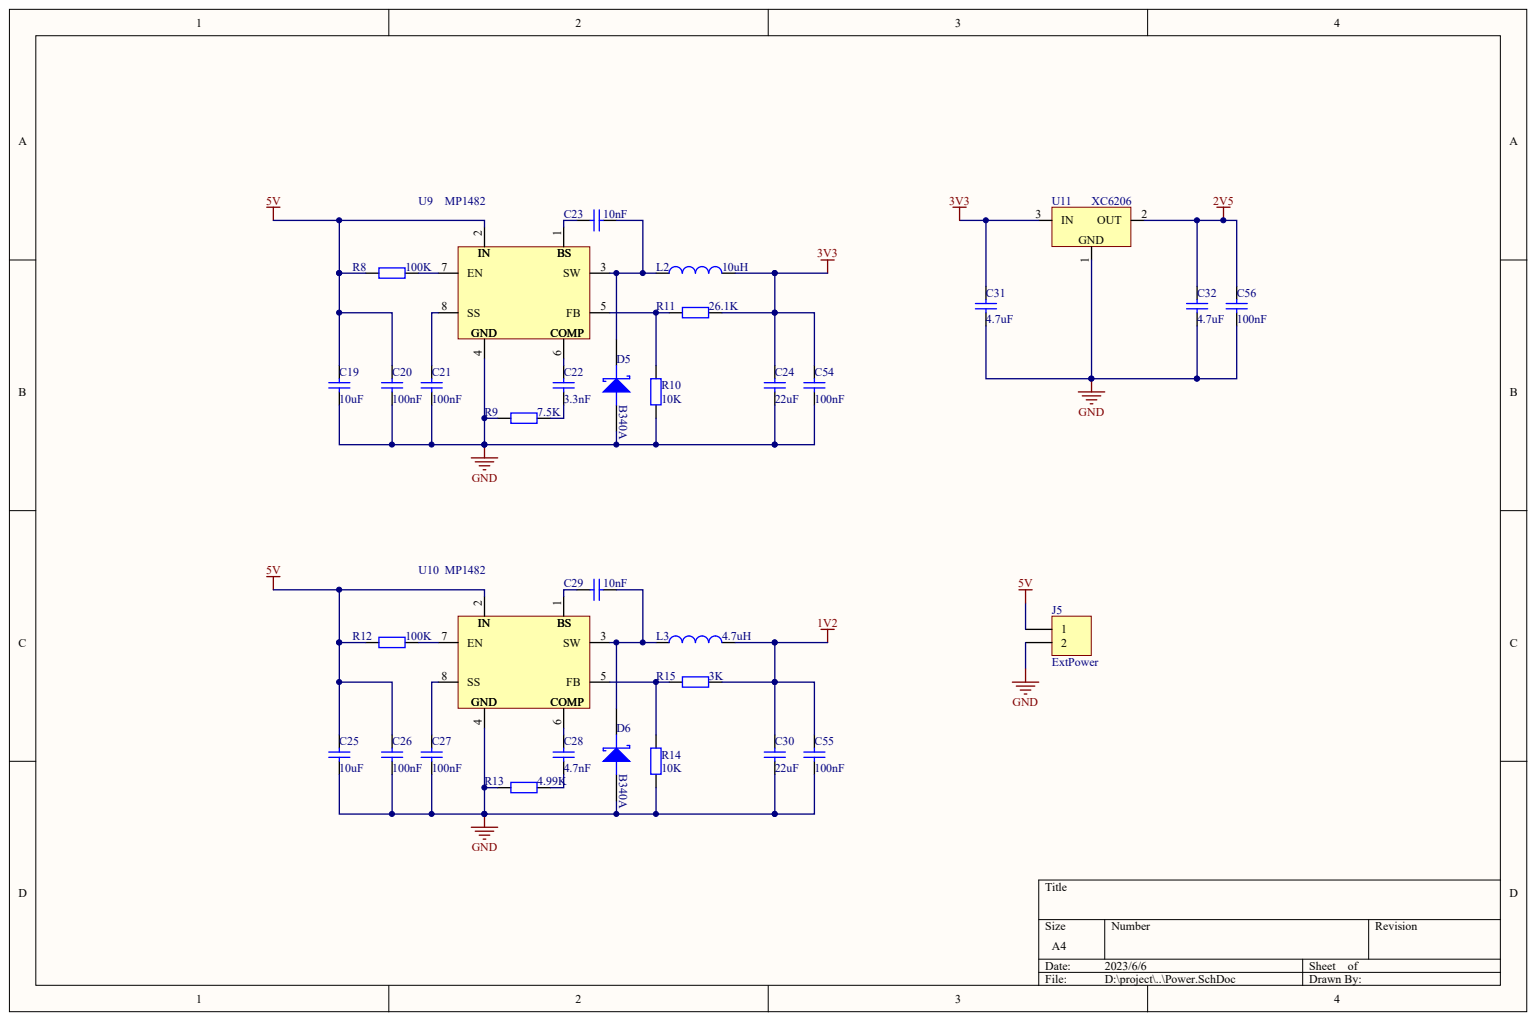
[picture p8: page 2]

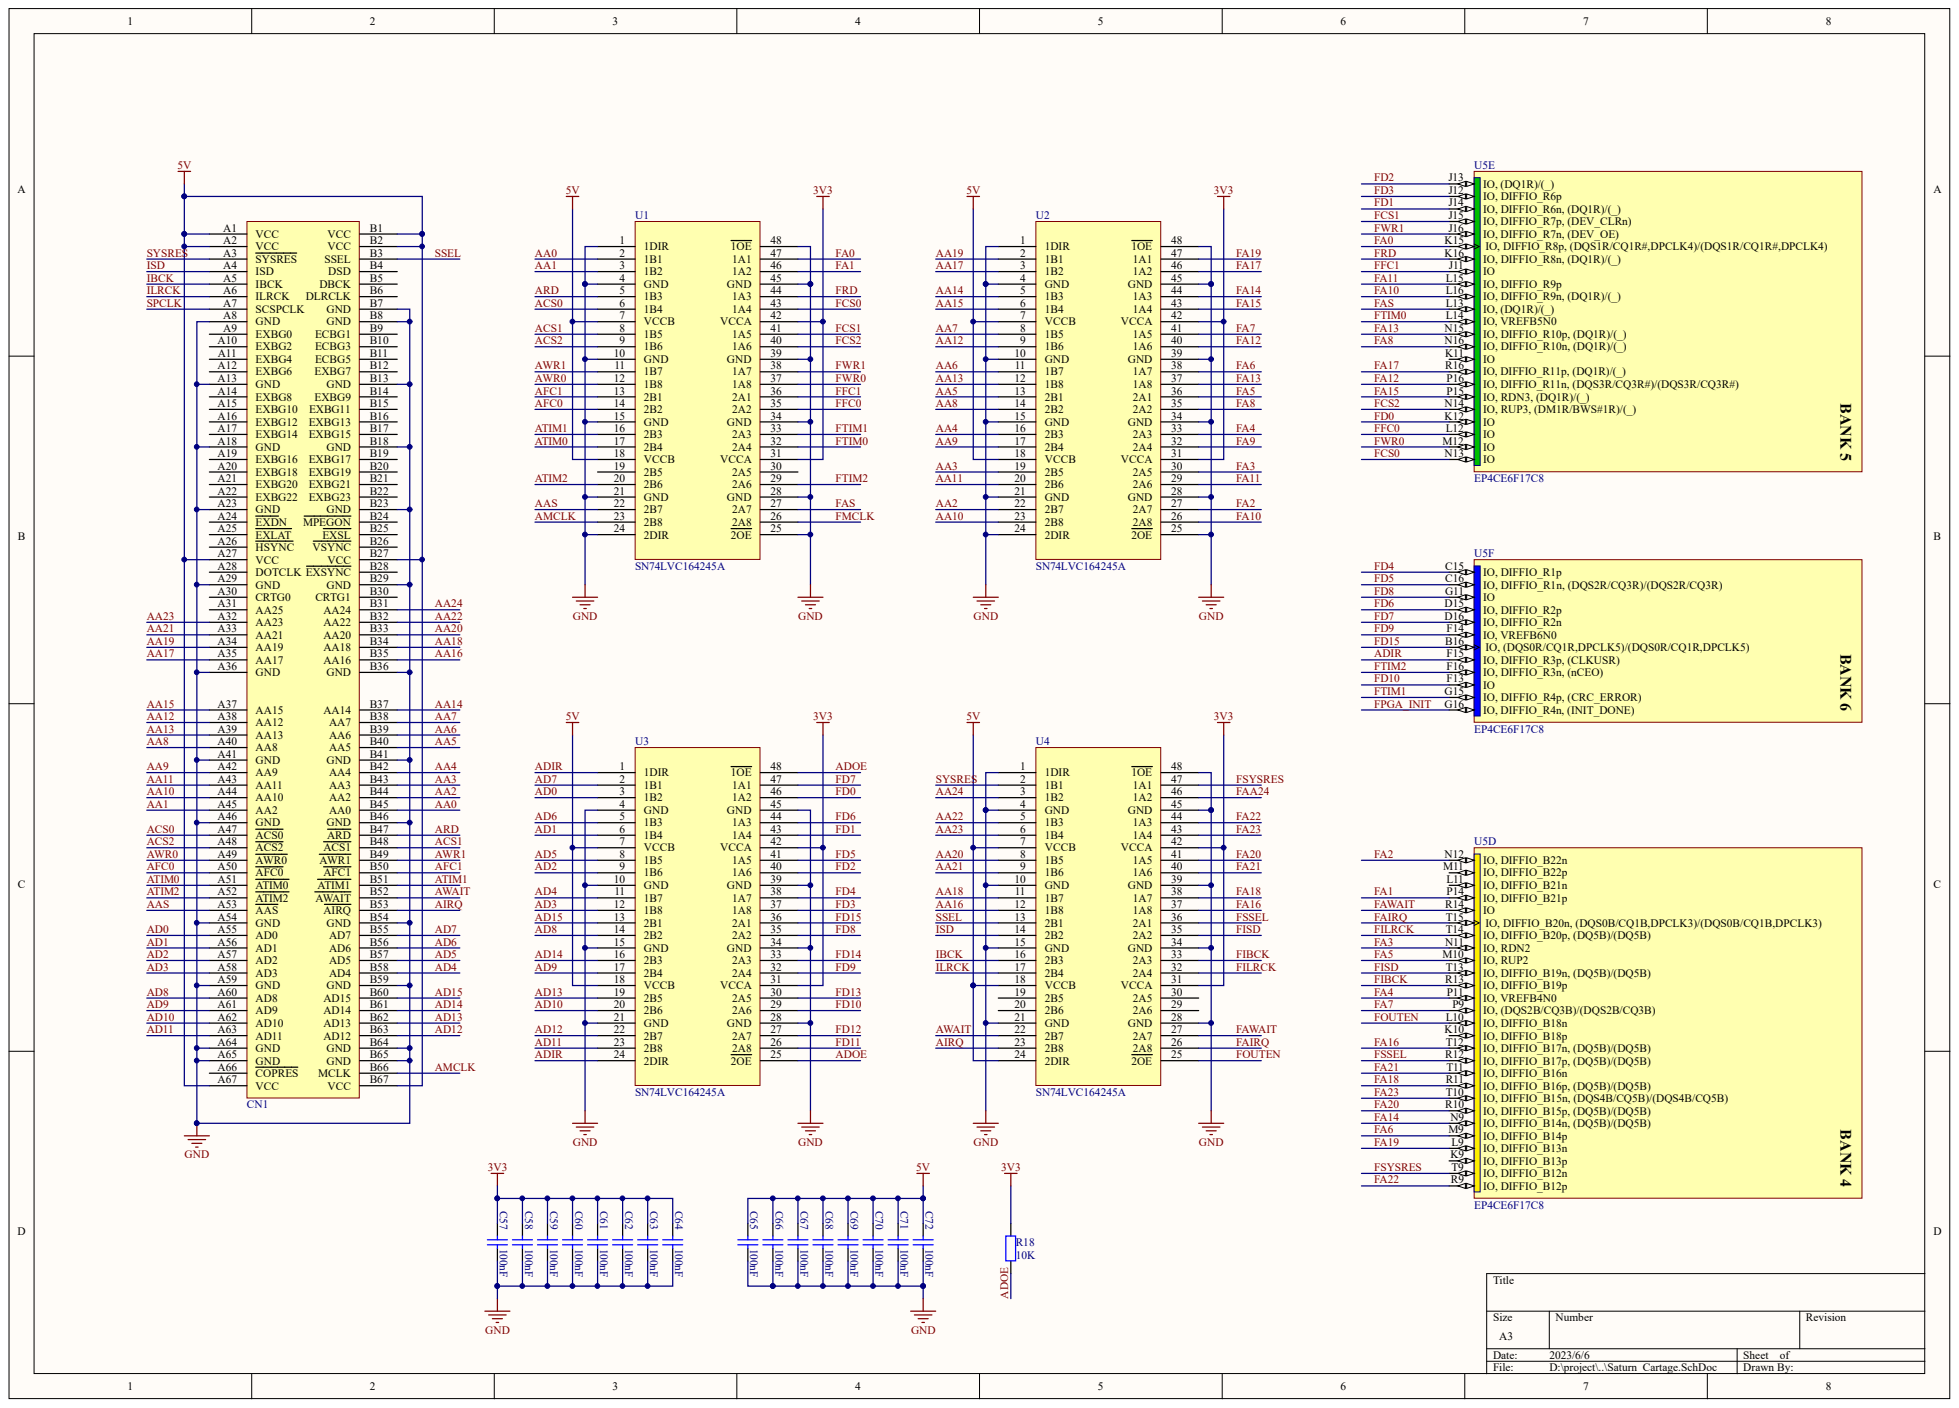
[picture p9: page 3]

AA15 A37 AA12 A38 AA13 A39 AA8 A40 GND A41

AA9 A42 AA10 A44 AA2 A45 GND A46

ACS0 A47 ACS2 A48 AWR0 A49 AAS A53 GND A54

AD0 A55 AD1 A56 AD2 A57 AD3 A58 GND A59

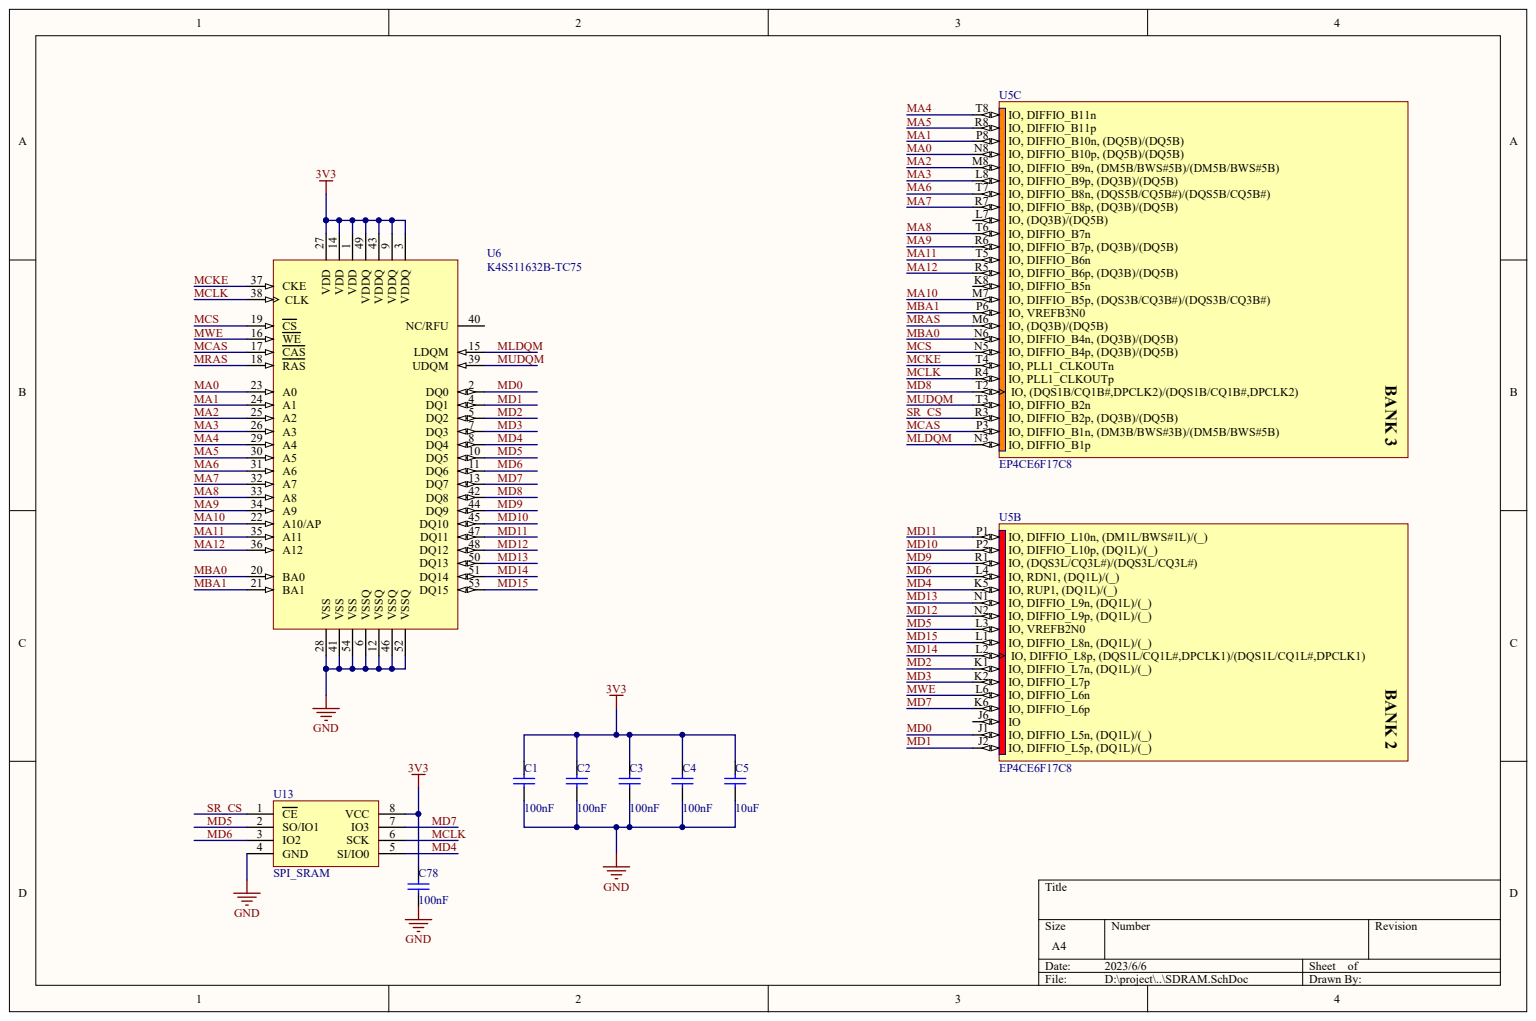
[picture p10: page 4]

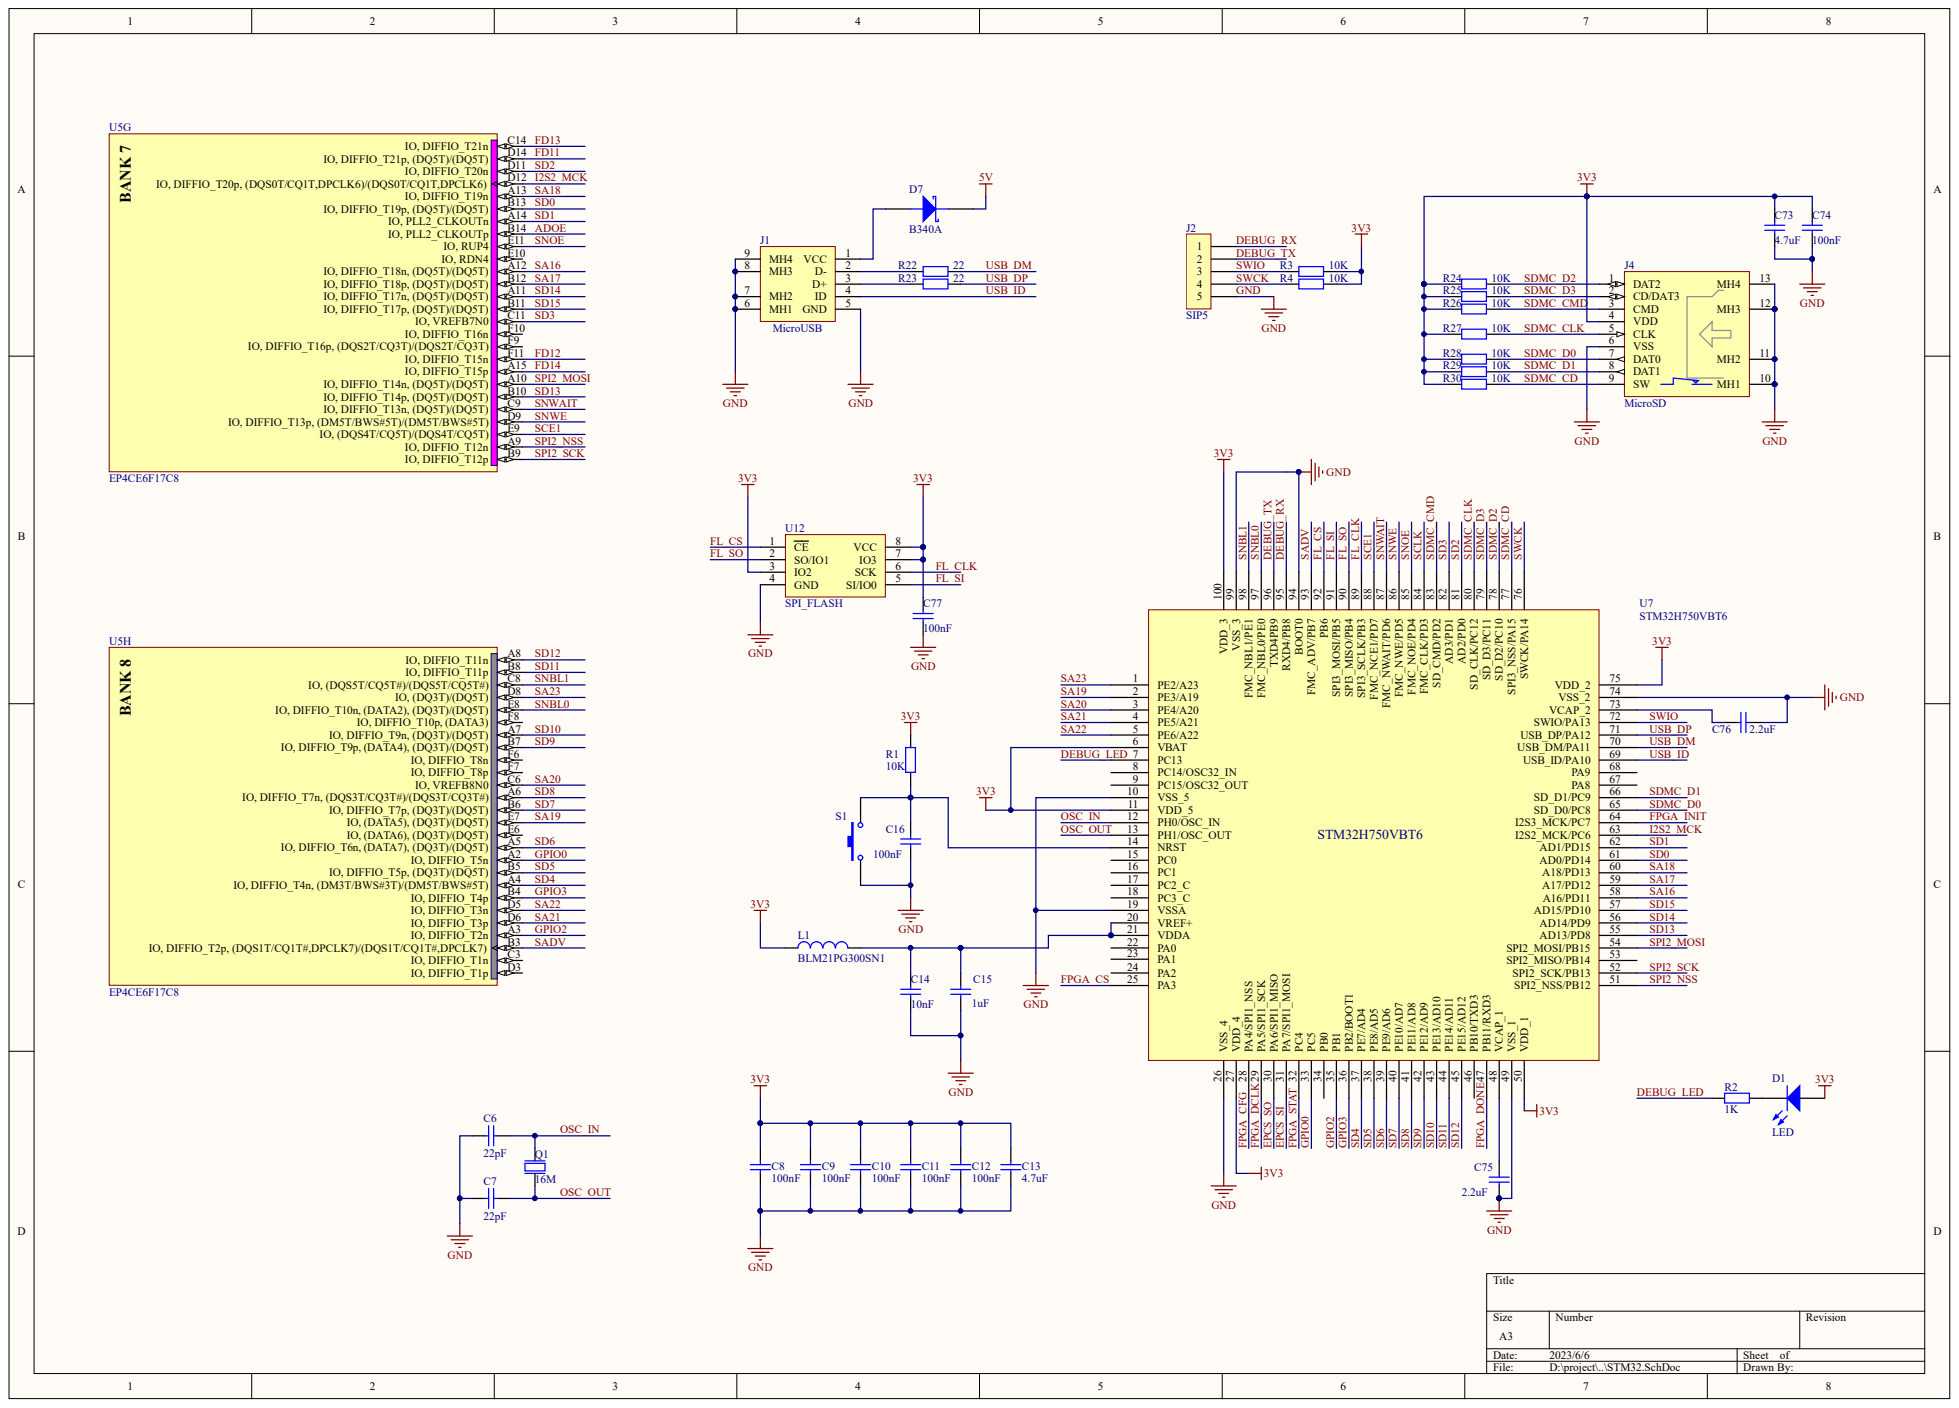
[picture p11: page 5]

R29 | | 10K SDMC_D1 | 8
R30 | | 10K SDMC_CD | 9

OSC_IN OSC_OUT | | PH0/OSC_IN 12 PH1/OSC_OUT 13 NRST 14

Comment | Description | Footprint | Quantity | Designator
100nF | Capacitor | C0603 | 53 | C1, C2, C3, C4, C8, C9, C10, C11, C12, C16, C18, C20, C21, C26, C27, C33, C34, C35, C36, C40, C41, C42, C43, C44, C45, C46, C47, C50, C51, C52, C53, C54, C55, C56, C57, C58, C59, C60, C61, C62, C63, C64, C65, C66, C67, C68, C69, C70, C71, C72, C74, C77, C78
10uF | Capacitor | C1206 | 3 | C5, C19, C25
22pF | Capacitor | C0603 | 2 | C6, C7
4.7uF | Capacitor | C0603 | 8 | C13, C31, C32, C38, C39, C48, C49, C73
10nF | Capacitor | C0603 | 4 | C14, C23, C29, C37
1uF | Capacitor | C0603 | 1 | C15
100pF | Capacitor | C0603 | 1 | C17
3.3nF | Capacitor | C0603 | 1 | C22
22uF | Capacitor | C1206 | 2 | C24, C30
4.7nF | Capacitor | C0603 | 1 | C28
2.2uF | Capacitor | C0603 | 2 | C75, C76
SaturnCartage | | Saturn_cart | 1 | CN1
LED | Typical RED GaAs LED | D0603 | 3 | D1, D2, D3
B340A | Schottky Diode | SMA | 3 | D5, D6, D7
MicroUSB | USB micro female SMT with 4 fixed foot | USB_MICRO_5S_B | 1 | J1
SIP5 | | SIP5 | 1 | J2
JTAG | Header, 5-Pin, Dual row | HDR2X5 | 1 | J3
MicroSD | MicroSD | MicroSD-1 | 1 | J4
ExtPower | Header, 2-Pin | HDR1X2 | 1 | J5
BLM21PG300SN1 | Inductor | R0805 | 2 | L1, L4
10uH | Inductor | CDRH5D28 | 1 | L2
4.7uH | Inductor | CDRH5D28 | 1 | L3
16M | XTAL SMD 2016, 32MHz, Cl=8pF, Total Tol: ¡ À 40ppm | SMD3225 | 1 | Q1
10K | Resistor | R0603 | 15 | R1, R3, R4, R10, R14, R18, R19, R24, R25, R26, R27, R28, R29, R30, R31
1K | Resistor | R0603 | 3 | R2, R16, R17
22 | Resistor | R0603 | 3 | R5, R22, R23
0 | Resistor | R0603 | 2 | R6, R20
0(NC) | Resistor | R0603 | 2 | R7, R21
100K | Resistor | R0603 | 2 | R8, R12
7.5K | Resistor | R0603 | 1 | R9
26.1K | Resistor | R0603 | 1 | R11
4.99K | Resistor | R0603 | 1 | R13
3K | Resistor | R0603 | 1 | R15
SW-PB | Switch | SW4_5X5 | 1 | S1
SN74LVC164245A | | DGG048 | 4 | U1, U2, U3, U4
EP4CE6F17C8 | Cyclone IV Family FPGA, 2V Core, 179 I/O Pins, 2 PLLs, 256-Pin FBGA, Speed Grade 8, Commercial Grade | FBGA256 | 1 | U5
K4S511632B-TC75 | 512Mb Synchronous High Data Rate DRAM, 8Mb x 16Bit x 4 Banks, 54-Pin TSOP | 54_TSOP2_400AF_N | 1 | U6
STM32H750VBT6 | | TQFP-100 | 1 | U7
SST25FV080B | | SOIC-8 | 1 | U8
MP1482 | | SOIC-8 | 2 | U9, U10
XC6206 | LDO | sot-23-xc6206 | 1 | U11
SPI_FLASH | | SOIC-8 | 1 | U12
SPI_SRAM | | sop-8_n | 1 | U13
50Mhz | | OSC_5032 | 1 | Y1

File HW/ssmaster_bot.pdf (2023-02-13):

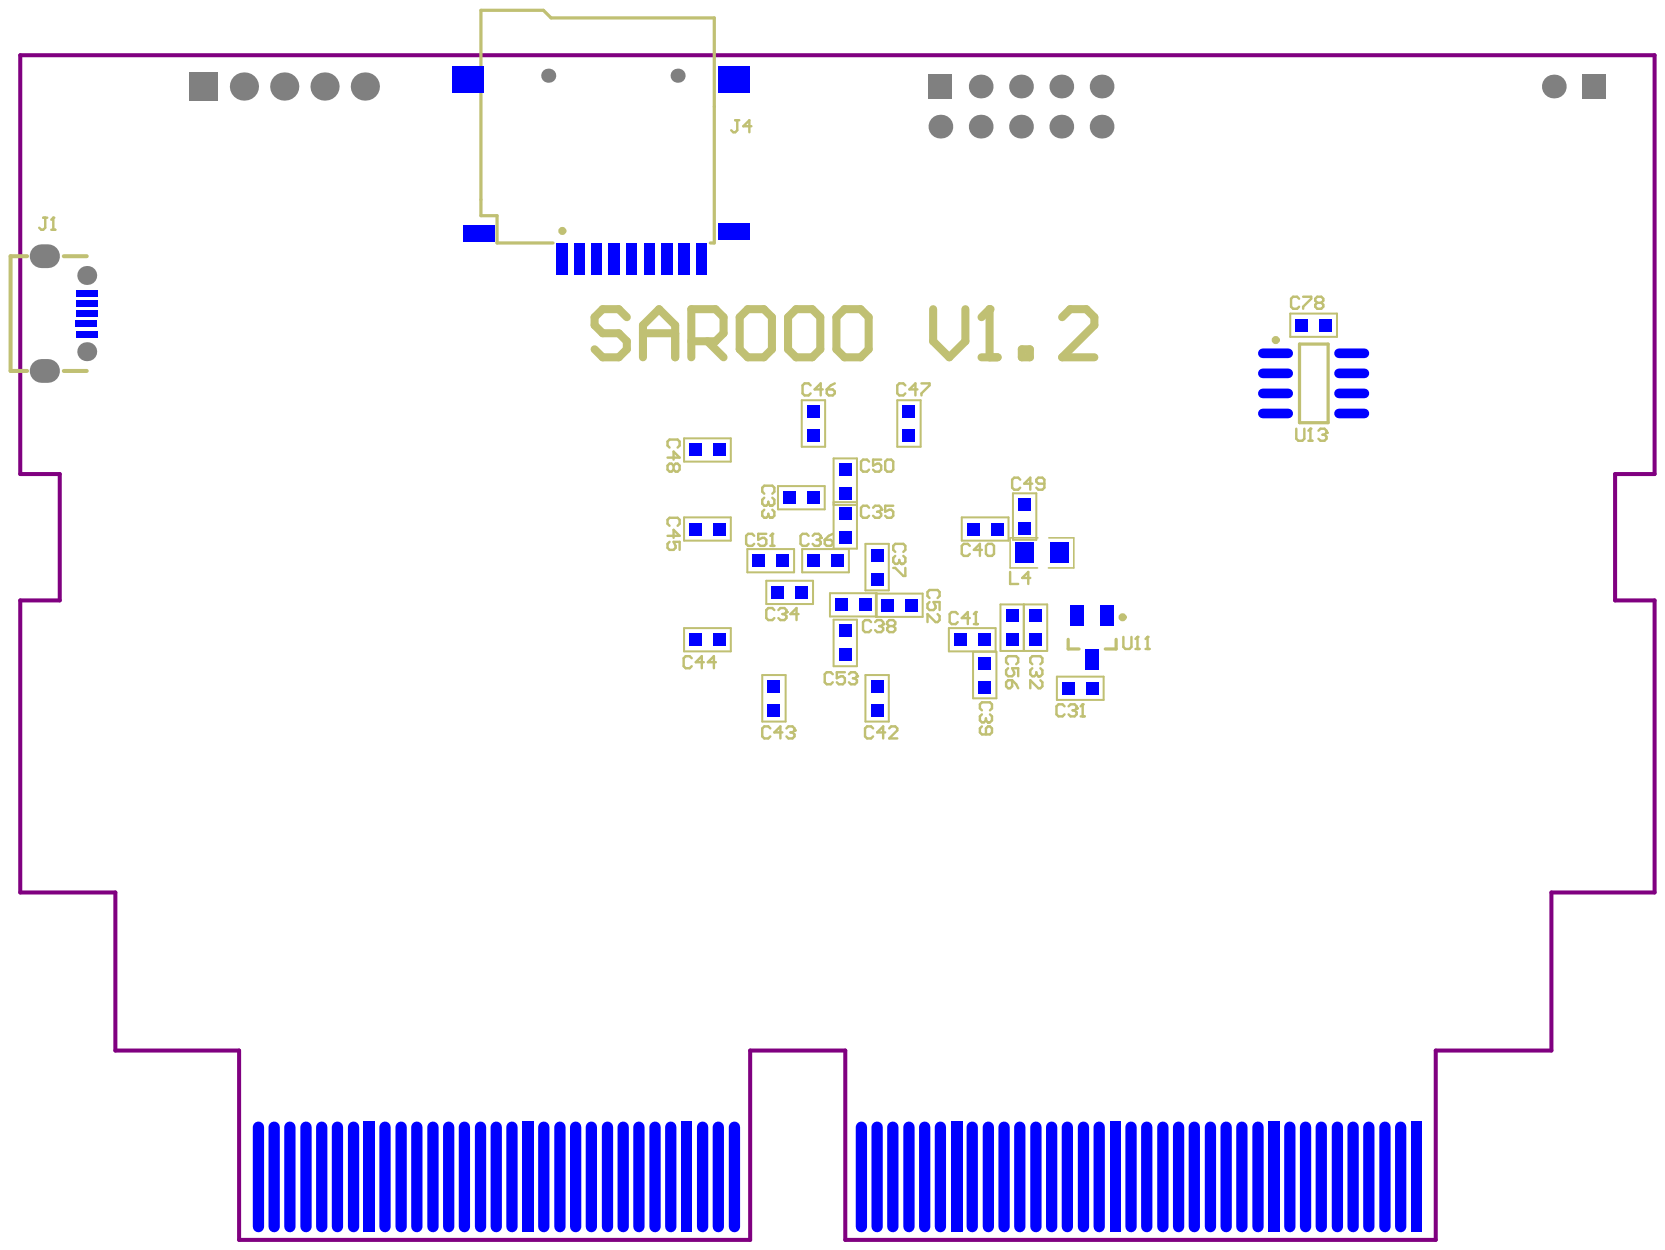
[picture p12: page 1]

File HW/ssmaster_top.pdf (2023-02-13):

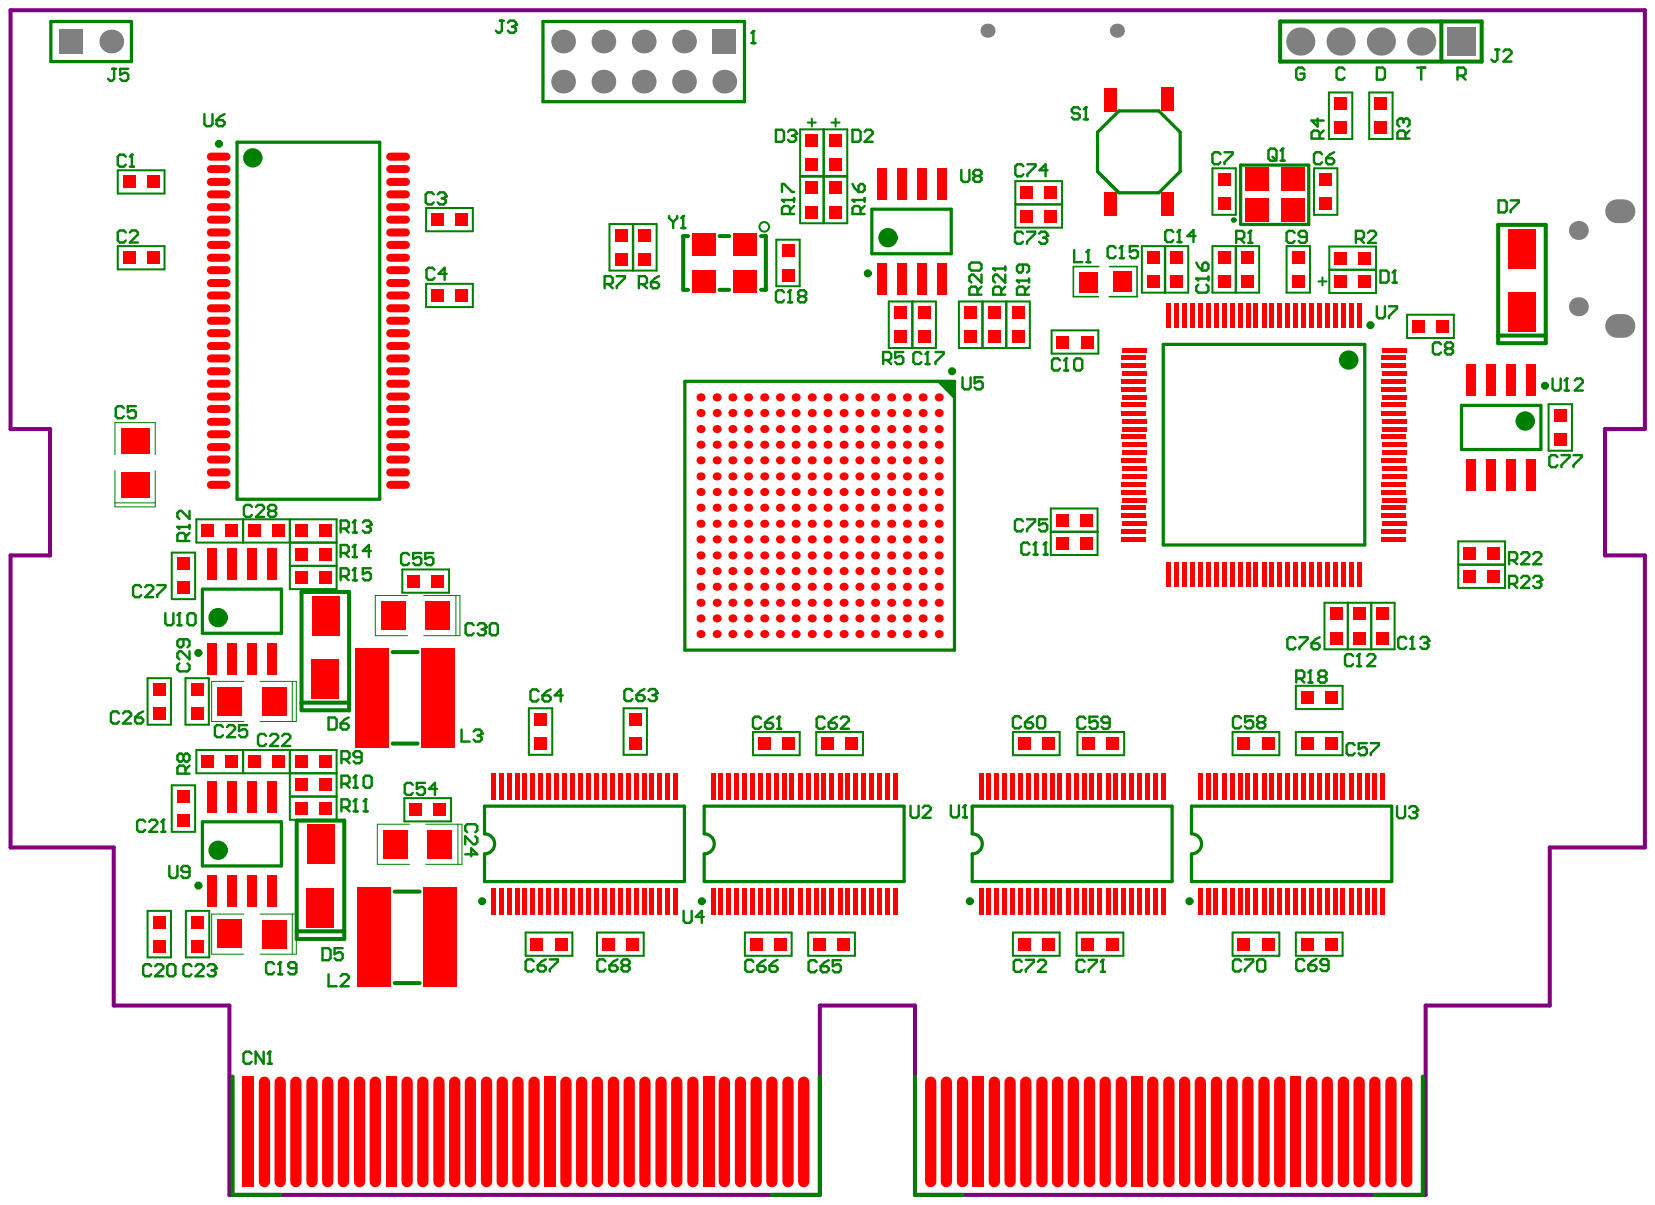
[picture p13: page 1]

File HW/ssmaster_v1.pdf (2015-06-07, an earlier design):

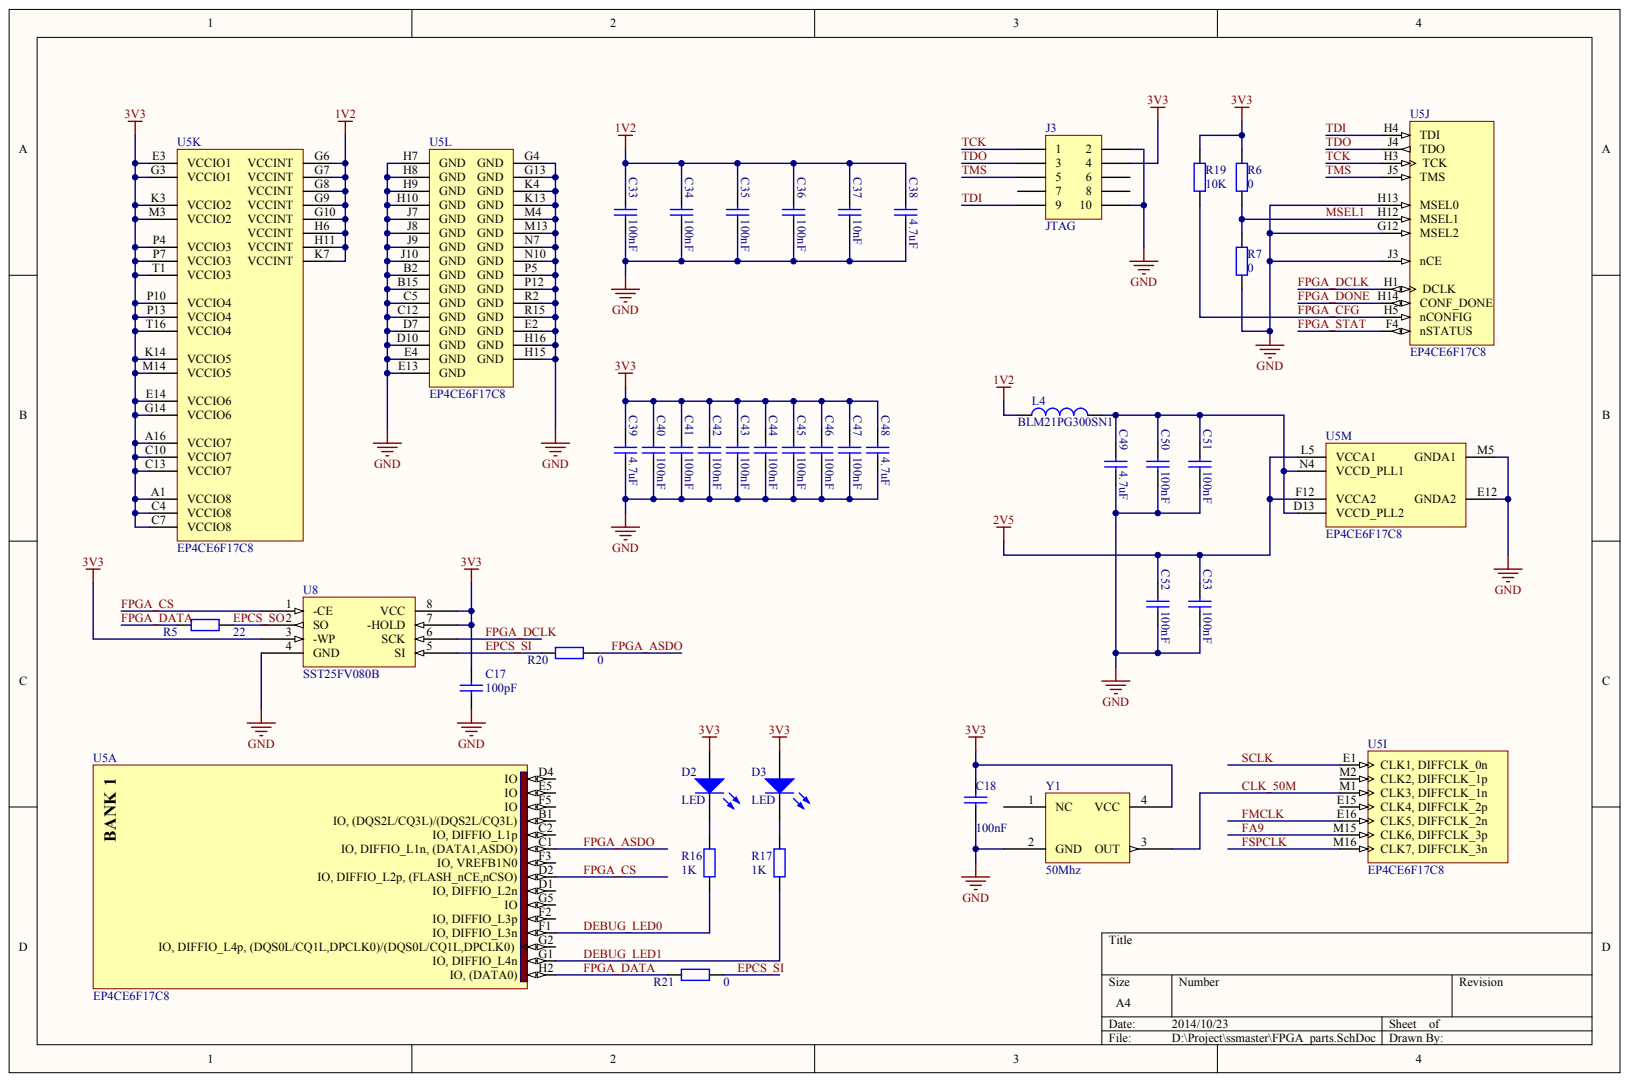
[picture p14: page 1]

VCCIO5 M14 | GND E13

VCCIO6 E14
VCCIO6 G14

VCCIO7 A16

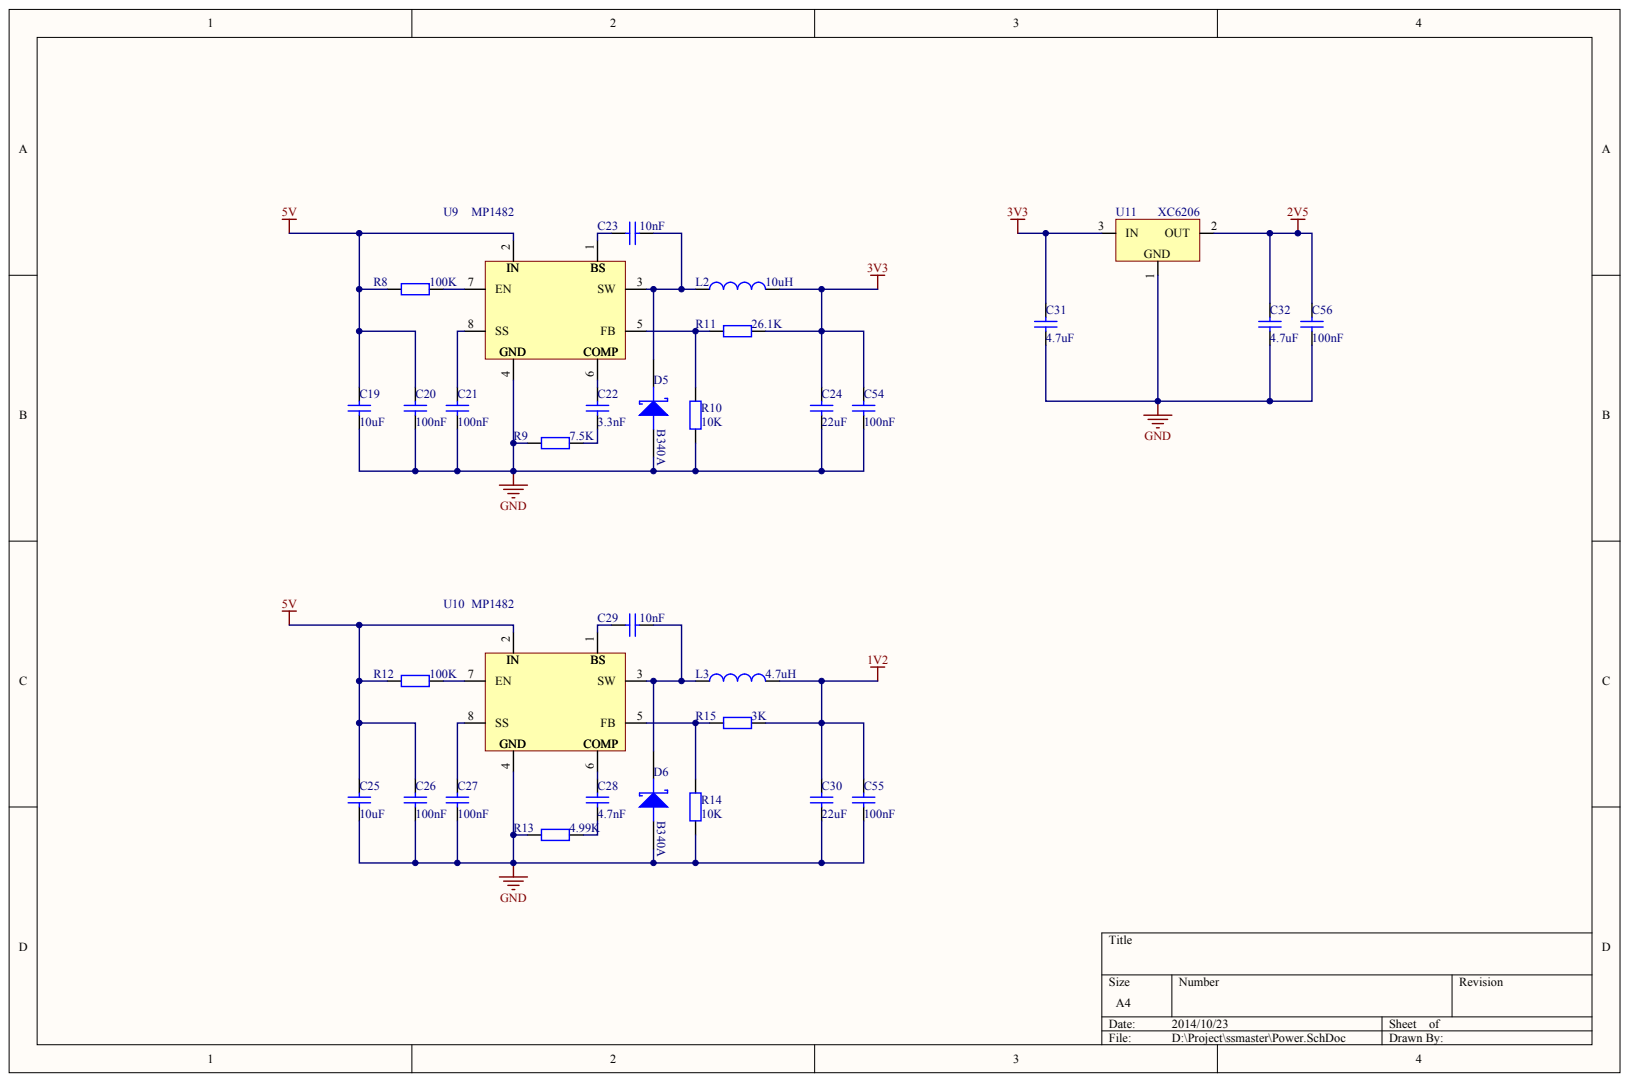
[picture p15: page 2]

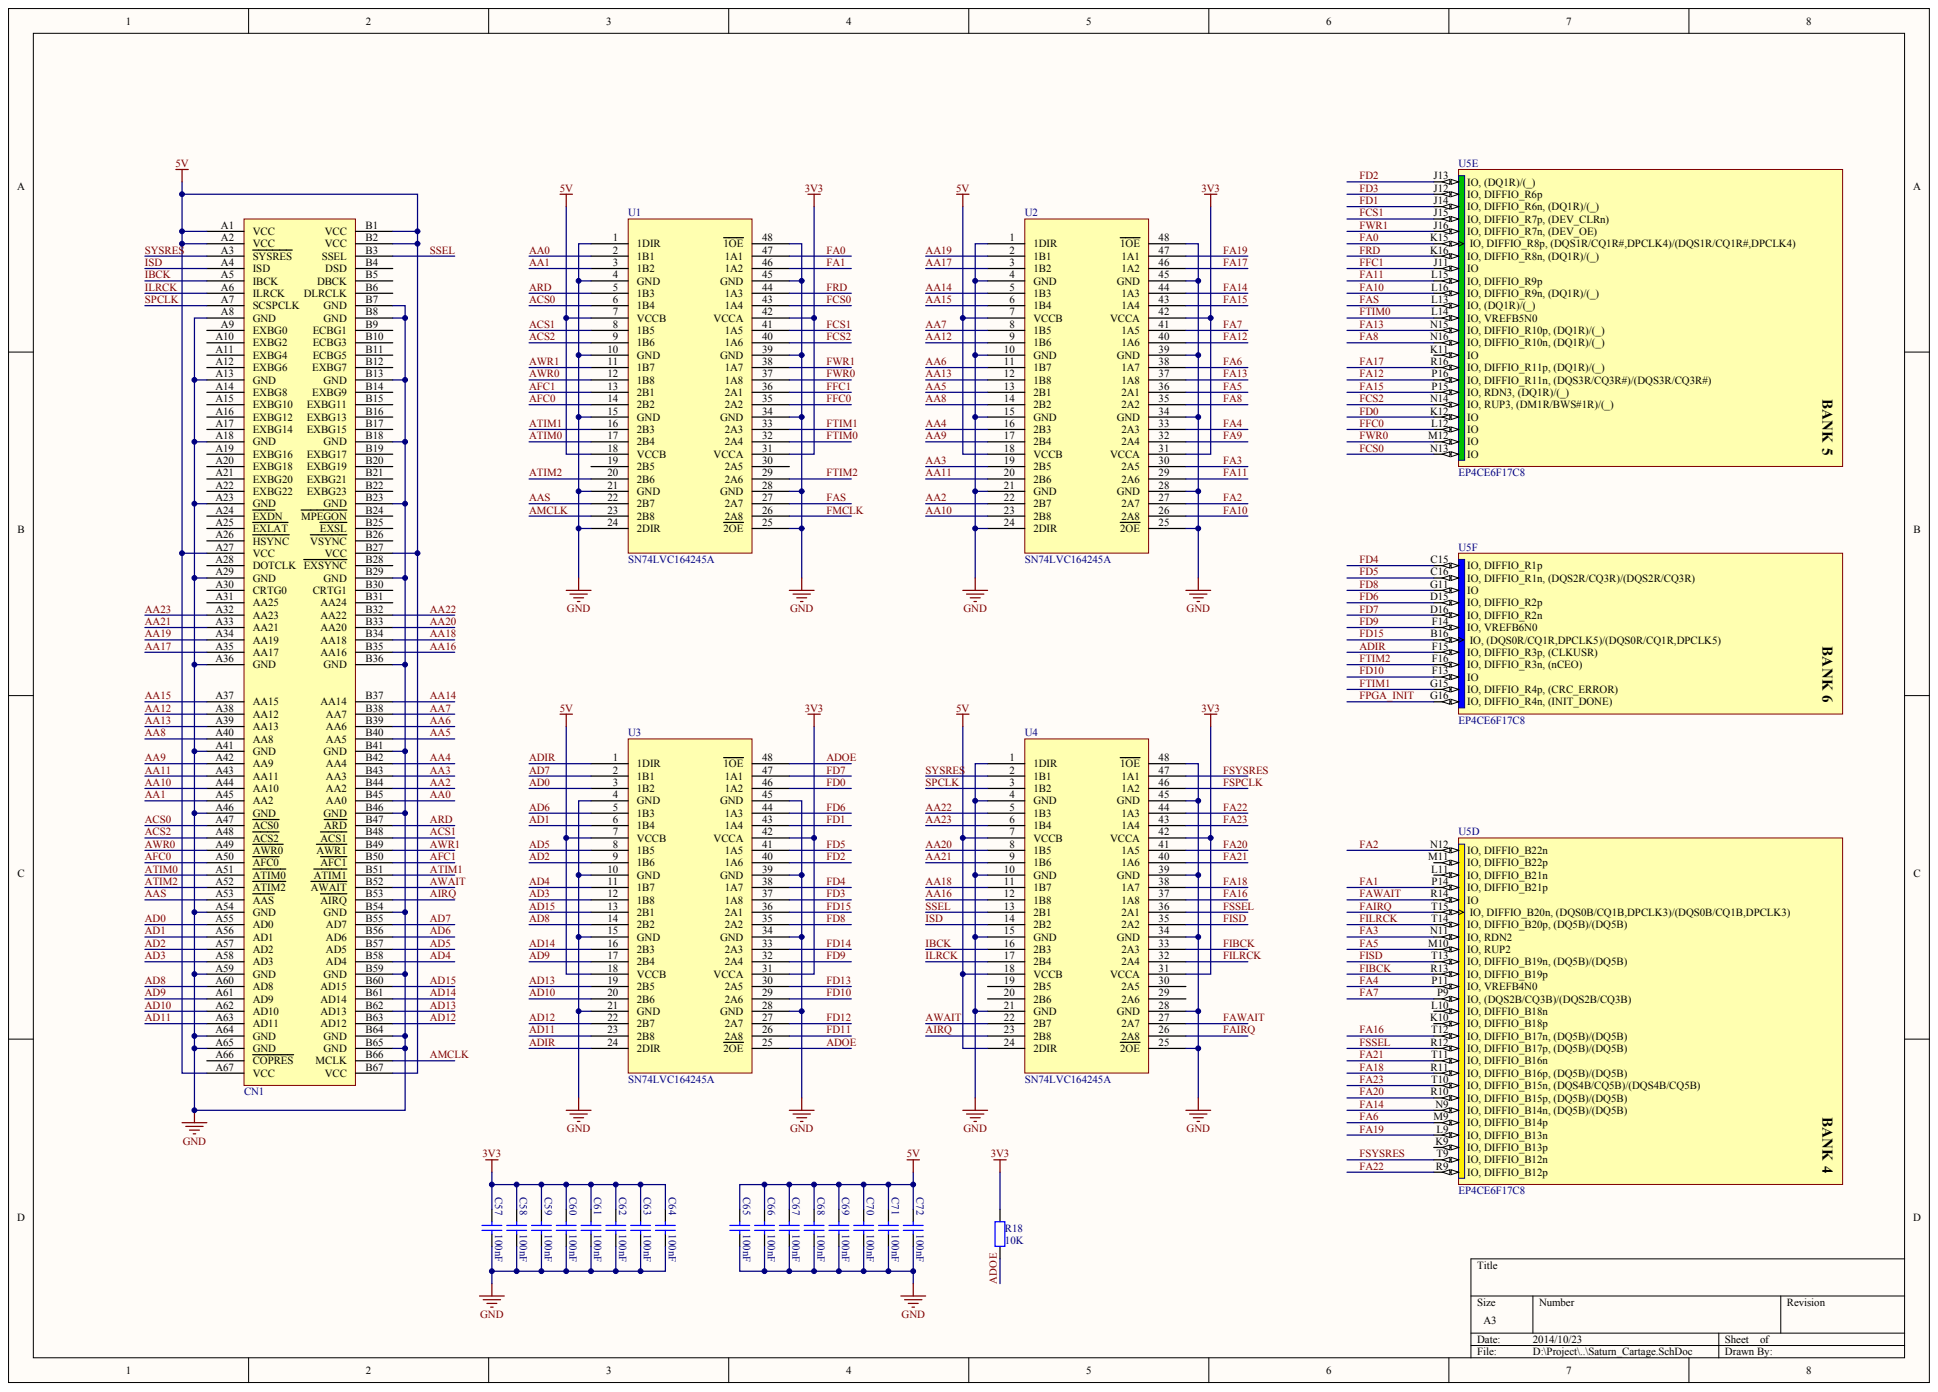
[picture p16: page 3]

FSYSRES FA22 FA19 FA6 FA14 FA20 FA23 FA18 FA21 FSSEL FA16 FA7 FA4 FIBCK FISD FA5 FA3 FILRCK FAIRQ FAWAIT FA1 FA2 FCS1 FD1 FD3 FD2 FFC1 FRD FA0 FWR1 FTIM0 FAS FA10 FA11 FA17 FA8 FA13 FD0 FCS2 FA15 FA12 FCS0 FWR0 FFC0 FD4 FD5 FD8 FD6 FD7 FD9 FD15

FSYSRES FSPCLK FA22 FA23 FA20 FA21 FA18 FA16 FSSEL FISD FIBCK FILRCK FAIRQ

AWR0 A49 AFC0 A50 ATIM0 A51 ATIM2 A52

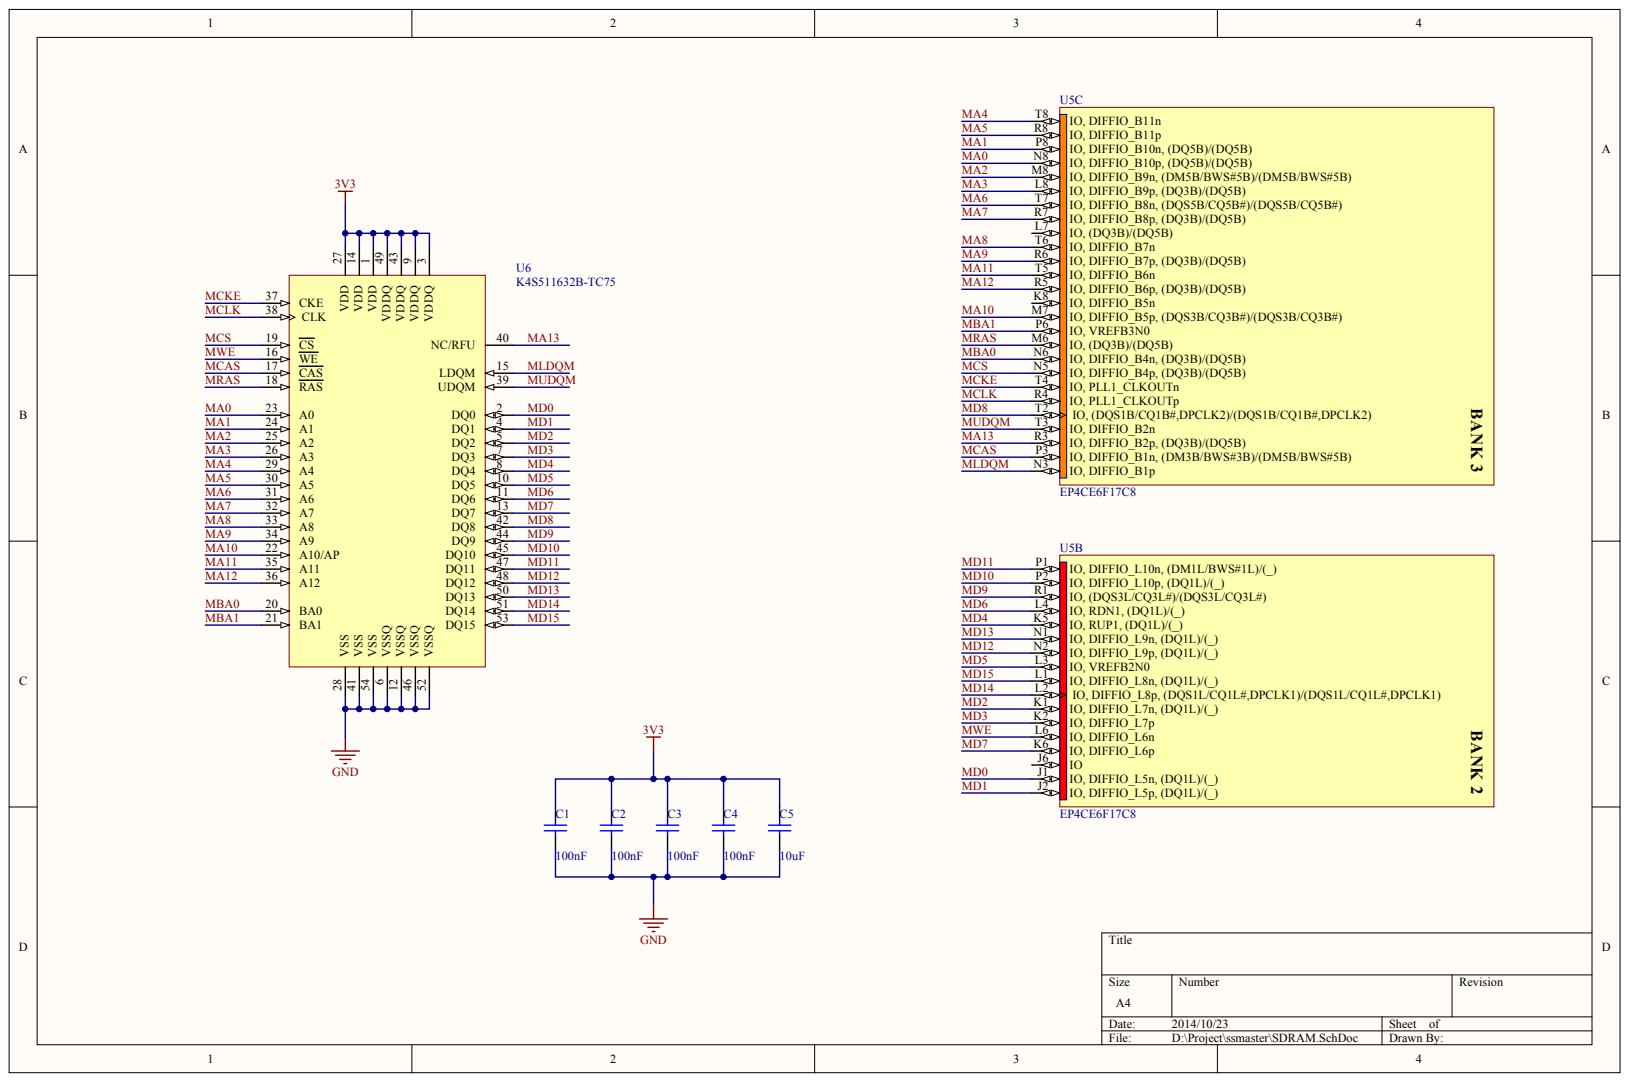
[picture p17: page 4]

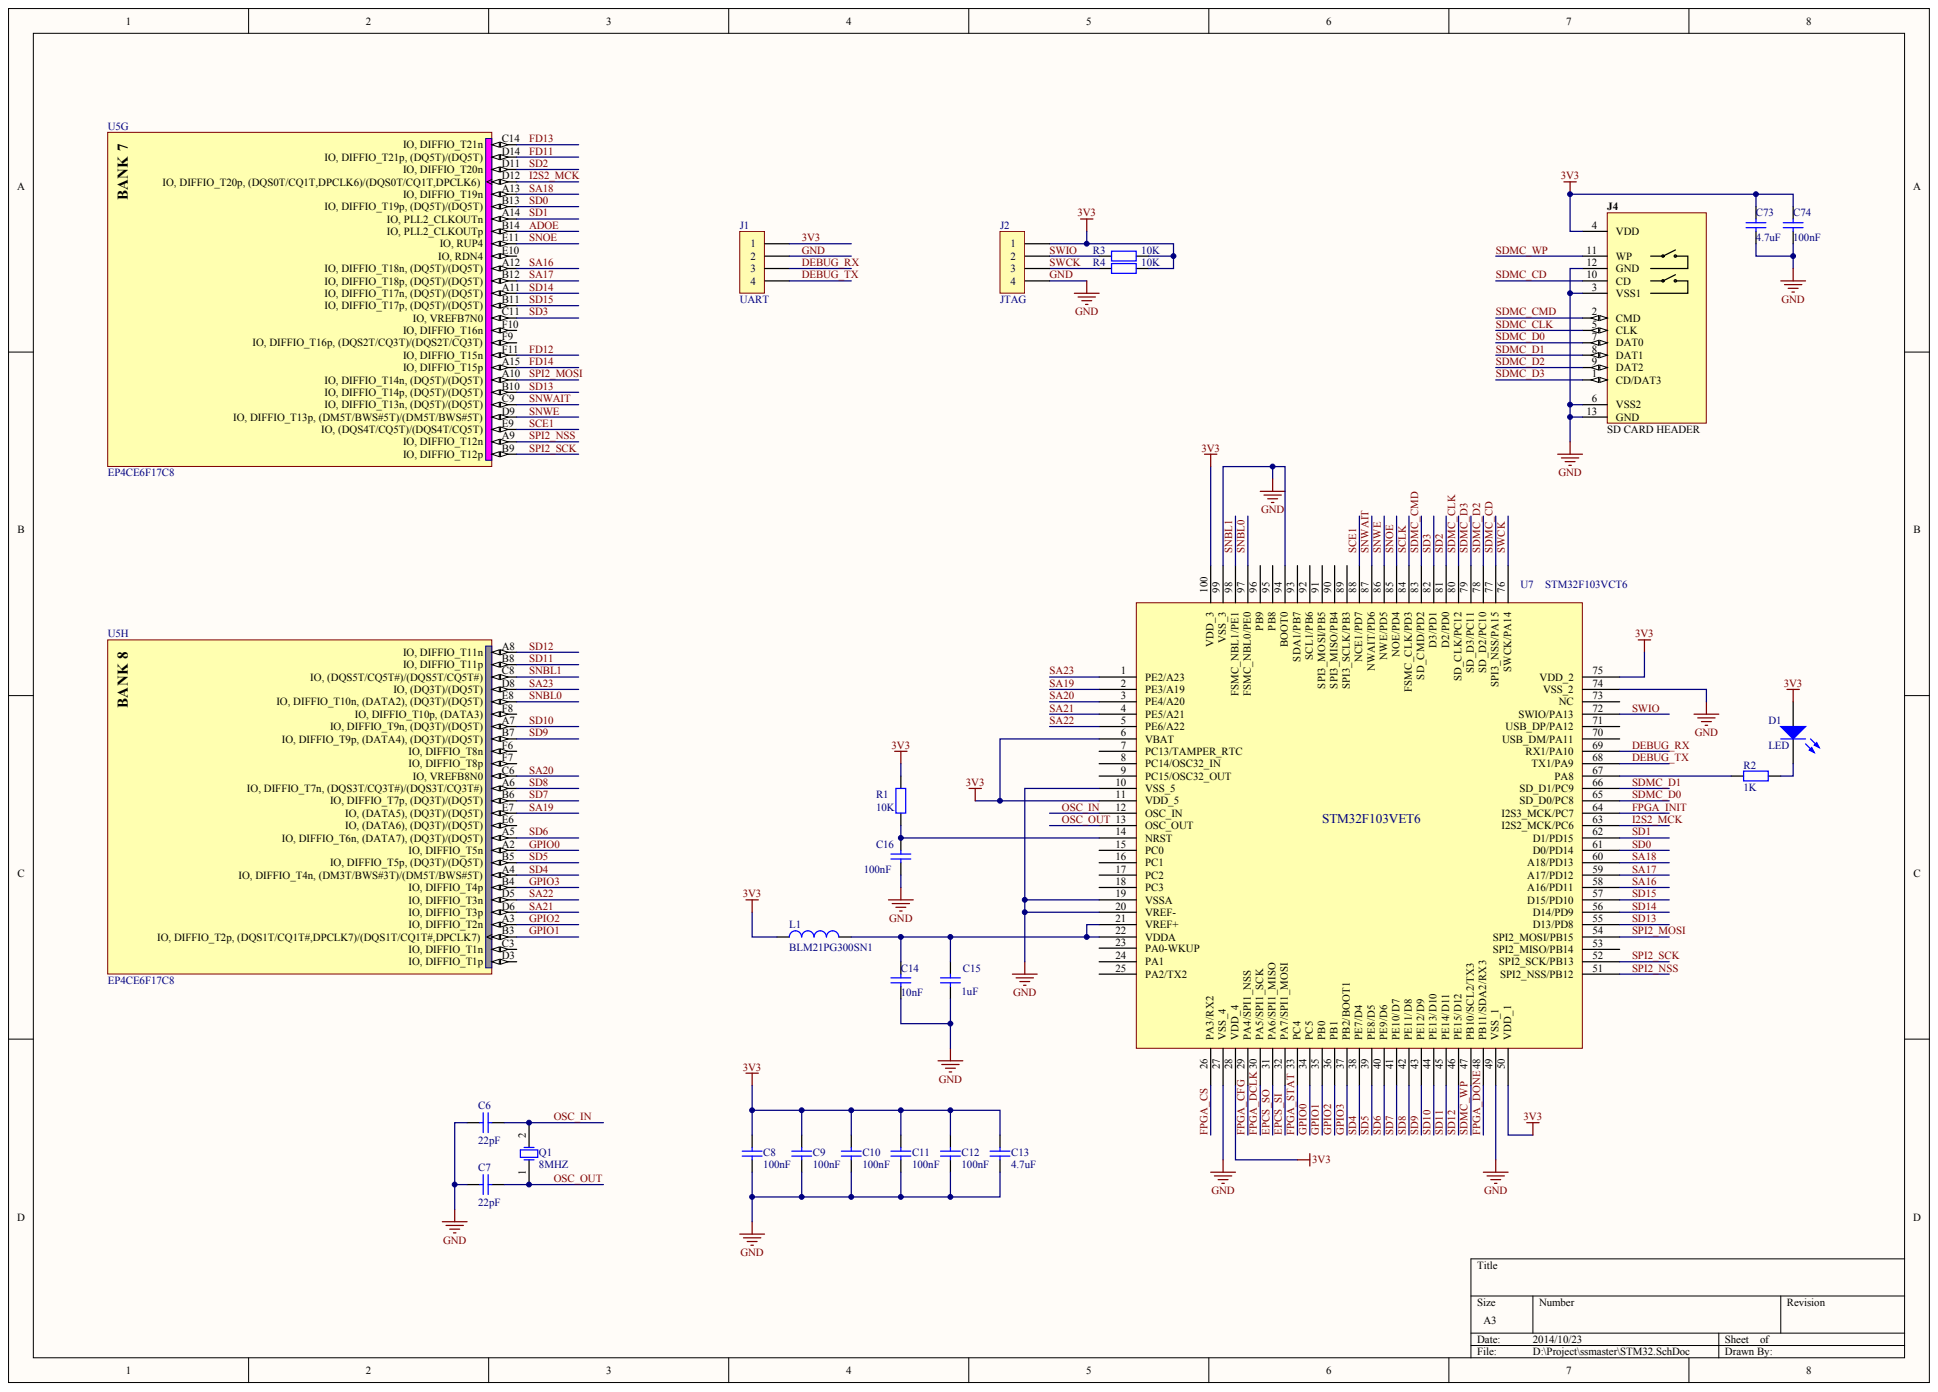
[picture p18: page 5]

8 | DAT0 7

OSC_IN | OSC_IN 12

VDD_5 11


Comment | Description | Designator | Footprint | LibRef | Quantity
100nF | Capacitor | C1, C2, C3, C4, C8, C9, C10, C11, C12, C16, C18, C20, C21, C26, C27, C33, C34, C35, C36, C40, C41, C42, C43, C44, C45, C46, C47, C50, C51, C52, C53, C54, C55, C56, C57, C58, C59, C60, C61, C62, C63, C64, C65, C66, C67, C68, C69, C70, C71, C72, C74 | C0603 | Cap | 51
10uF | Capacitor | C5, C19, C25 | C1206 | Cap | 3
22pF | Capacitor | C6, C7 | C0603 | Cap | 2
4.7uF | Capacitor | C13, C31, C32, C38, C39, C48, C49, C73 | C0603 | Cap | 8
10nF | Capacitor | C14, C23, C29, C37 | C0603 | Cap | 4
1uF | Capacitor | C15 | C0603 | Cap | 1
100pF | Capacitor | C17 | C0603 | Cap | 1
3.3nF | Capacitor | C22 | C0603 | Cap | 1
22uF | Capacitor | C24, C30 | C1206 | Cap | 2
4.7nF | Capacitor | C28 | C0603 | Cap | 1
SaturnCartage | | CN1 | Saturn_cart | SaturnCartage | 1
LED | Typical RED GaAs LED | D1, D2, D3 | D0603 | LED1 | 3
B340A | Schottky Diode | D5, D6 | SMA | DIODE SCHOTTKY | 2
UART | | J1 | SIP4 | SIP4 | 1
JTAG | | J2 | SIP4 | SIP4 | 1
JTAG | Header, 5-Pin, Dual row | J3 | HDR2X5 | Header 5X2 | 1
SD CARD HEADER | Secure Digital Card Socket | J4 | KSDC012551 | KSDC012551-9 | 1
BLM21PG300SN1 | Inductor | L1, L4 | R0805 | Inductor | 2
10uH | Inductor | L2 | CDRH5D28 | Inductor | 1
4.7uH | Inductor | L3 | CDRH5D28 | Inductor | 1
8MHZ | Crystal Oscillator | Q1 | SMD_CRYSTAL | XTAL | 1
10K | Resistor | R1, R3, R4, R10, R14, R18, R19 | R0603 | Res2 | 7
1K | Resistor | R2, R16, R17 | R0603 | Res2 | 3
22 | Resistor | R5 | R0603 | Res2 | 1
0 | Resistor | R6, R7, R20, R21 | R0603 | Res2 | 4
100K | Resistor | R8, R12 | R0603 | Res2 | 2
7.5K | Resistor | R9 | R0603 | Res2 | 1
26.1K | Resistor | R11 | R0603 | Res2 | 1
4.99K | Resistor | R13 | R0603 | Res2 | 1
3K | Resistor | R15 | R0603 | Res2 | 1
SN74LVC164245A | | U1, U2, U3, U4 | DGG048 | SN74LVC164245A | 4
EP4CE6F17C8 | Cyclone IV Family FPGA, 2V Core, 179 I/O Pins, 2 PLLs, 256-Pin FBGA, Speed Grade 8, Commercial Grade | U5 | FBGA256 | EP4CE6F17C8 | 1
K4S511632B-TC75 | 512Mb Synchronous High Data Rate DRAM, 8Mb x 16Bit x 4 Banks, 54-Pin TSOP | U6 | 54_TSOP2_400AF _N | K4S511632B-TC75 | 1
STM32F103VCT6 | | U7 | TQFP-100 | STM32F103VCT6 | 1
SST25FV080B | | U8 | SOIC-8 | SST25FV080B | 1
MP1482 | | U9, U10 | SOIC-8 | MP1482 | 2
XC6206 | LDO | U11 | SOT-23 | XC6206 | 1
50Mhz | | Y1 | OSC_5032 | JZSMD5X7 | 1

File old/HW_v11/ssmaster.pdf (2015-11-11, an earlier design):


VCCIO6 E14

VCCIO7 A16



A65 | B65
A66 A67 | B66 B67




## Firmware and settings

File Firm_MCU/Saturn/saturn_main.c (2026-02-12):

#include "main.h"
#include "ff.h"
#include "cdc.h"

/******************************************************************************/

osSemaphoreId_t sem_wait_irq;
osSemaphoreId_t sem_wait_disc;
osSemaphoreId_t sem_wait_pause;
osMutexId_t mutex_fs;

int lang_id = 0;
int debug_flags = 0;
int sector_delay = 0;
int sector_delay_force = -1;
int play_delay = 0;
int play_delay_force = -1;
int pend_delay = 0;
int pend_delay_force = -1;
int auto_update = 0;
char mdisc_str[16];
int next_disc = -1;

int log_mask = LOG_MASK_DEFAULT;

void hw_delay(int us);

int do_firm_update = 0;

/******************************************************************************/


u32 bswap32(u32 d)
{
	return ((d&0xff)<<24) | ((d&0xff00)<<8) | ((d>>8)&0xff00) | ((d>>24)&0xff);
}


// Track 信息
void init_toc(void)
{
	TRACK_INFO *last;
	int i;

	if(cdb.track_num==0)
		return;

	for(i=0; i<102; i++){
		cdb.TOC[i] = 0xffffffff;
	}

	for(i=0; i<cdb.track_num; i++){
		cdb.TOC[i] = bswap32((cdb.tracks[i].ctrl_addr<<24) | cdb.tracks[i].fad_start);
		SSLOG(_INFO, "track %2d: fad_0=%08x fad_start=%08x fad_end=%08x offset=%08x %d\n",
					i, cdb.tracks[i].fad_0, cdb.tracks[i].fad_start, cdb.tracks[i].fad_end,
					cdb.tracks[i].file_offset, cdb.tracks[i].sector_size);
	}

	last = &cdb.tracks[cdb.track_num-1];
	cdb.TOC[99]  = bswap32((cdb.tracks[0].ctrl_addr<<24) | 0x010000);
	cdb.TOC[100] = bswap32((last->ctrl_addr<<24) | (cdb.track_num<<16));
	cdb.TOC[101] = bswap32((last->ctrl_addr<<24) | (last->fad_end+1));

	cdb.trans_type = 0;
	cdb.cdwnum = 0;
	cdb.cdir_lba = 0;
	cdb.root_lba = 0;

	cdb.status = STAT_PAUSE;
	set_status(cdb.status);

	sector_delay = 0;
}


u32 track_to_fad(u16 track_index)
{
	int t, index;

	if(track_index==0xffff){
		return cdb.tracks[cdb.track_num-1].fad_end;
	}else if(track_index==0){
		return 0;
	}

	t     = (track_index>>8)-1;
	if(t<0)
		t = 0;
	index = track_index&0xff;
	TRACK_INFO *tk = &cdb.tracks[t];

	if(index<=0x01){
		return tk->fad_start;
	} else if(index > tk->max_index){
		return tk->fad_end;
	} else{
		return tk->index[index-2];
	}
}

int fad_to_track(u32 fad)
{
	int i;

	for(i=0; i<cdb.track_num; i++){
		if(fad>=cdb.tracks[i].fad_0 && fad<=cdb.tracks[i].fad_end)
			return i+1;
	}

	return 0xff;
}

TRACK_INFO *get_track_info(int track_index)
{
	int t;

	if(track_index==0xffff){
		t = cdb.track_num-1;
	}else if(track_index==0){
		return NULL;
	}else{
		t = (track_index>>8)-1;
	}

	if(t>=cdb.track_num)
		return NULL;
	
	return &cdb.tracks[t];
}


/******************************************************************************/

// 内部扇区缓存, 32K大小, 大概16个2k的扇区. 位于SDRAM中
// FATFS层以512字节为单位读取, 每次读64个单位.
static u8 *sector_buffer = (u8*)0x24002000;

// 内部缓存中保存的FAD扇区范围
static u32 buf_fad_start = 0;
static u32 buf_fad_end = 0;
// 由于存在2352这样的扇区格式, FAD扇区不是2048字节对齐的.
// FATFS层以512为单位读取数据. FAD扇区相对于sector_buffer有一个偏移.
static u32 buf_fad_offset = 0;
// 内部缓存中的扇区大小
static u32 buf_fad_size = 0;


static u8 reorder[24] = {
	0x00, 0x42, 0x7d, 0xbf, 0x64, 0x32, 0x96, 0xaf,
	0x08, 0x21, 0x3a, 0x53, 0x6c, 0x85, 0x9e, 0xb7,
	0x10, 0x29, 0x19, 0x5b, 0x74, 0x8d, 0xa6, 0x4b
};

void subcode_convert(void)
{
	u8 *dst = cdb.subcode_buf;
	u8 *sub = sector_buffer;
	u8 *tbuf = sector_buffer+2048;
	int p, i, j, k;

	p = 0;
	while(p<1536){
		memset(tbuf, 0, 96);
	//	for(i=0; i<8; i++){ // 带PQ通道
		for(i=2; i<8; i++){ // 无PQ通道
			for(j=0; j<12; j++){
				u8 d = sub[i*12+j];
				for(k=0; k<8; k++){
					u8 b = (d>>(7-k))&1;
					tbuf[j*8+k] |= b<<(7-i);
				}
			}
		}
		tbuf += 96;
		sub += 96;
		p += 96;
	}

	sub = sector_buffer+2048;
	p = 0;
	while(p<(96*14)){
		for(j=0; j<24; j++){
			dst[j] = sub[reorder[j]];
		}
		p += 24;
		dst += 24;
		sub += 24;
	}
}


int get_sector(int fad, BLOCK *wblk)
{
	int retv, dp, nread;

	// 先查找track信息
	if(cdb.play_track==NULL || fad<cdb.play_track->fad_0 || fad>cdb.play_track->fad_end){
		cdb.track = fad_to_track(fad);
		SSLOG(_DTASK, "Change to track %d\n", cdb.track);
		if(cdb.track!=0xff){
			cdb.play_track = &cdb.tracks[cdb.track-1];
			cdb.subrw_wp = cdb.subrw_rp;
		}else{
			// play的FAD参数错误
			SSLOG(_DTASK, "play_track not found!\n");
			cdb.status = STAT_ERROR;
			cdb.play_type = 0;
			return -1;
		}
	}
	if(wblk==NULL)
		return 0;

	if(fad>=buf_fad_start && fad<buf_fad_end){
		// 在内部缓存中找到了要play的扇区
		//SSLOG(_DTASK, " fad_%08x found at buffer!\n", fad);
		dp = buf_fad_offset+(fad-buf_fad_start)*buf_fad_size;
		wblk->data = sector_buffer+dp;
	}else{
		// 内部缓存中没有要play的扇区. 从文件重新读取.
		//SSLOG(_DTASK, " fad_%08x not found. need read from file.\n", fad);
		
		// 先读subcode. 最多读1536字节((32768/2048)*96).
		if(cdb.has_subrw && cdb.iflag&0x02 && cdb.status!=STAT_SCAN){
			f_lseek(&cdb.subcode_fp, (fad-150)*96);
			f_read(&cdb.subcode_fp, sector_buffer, 1536, (u32*)&nread);
			if(cdb.has_subrw==1){
				// sub格式需要先解码
				subcode_convert();
			}else{
				// cdg格式直接使用
				memcpy(cdb.subcode_buf, sector_buffer, 1536);
			}
		}

		cdb.ctrladdr = cdb.play_track->ctrl_addr;
		cdb.index = 1;

		if(cdb.status==STAT_SCAN){
			buf_fad_start = fad-13;
		}else{
			buf_fad_start = fad;
		}
		buf_fad_size = cdb.play_track->sector_size;

		dp = cdb.play_track->file_offset+(fad-cdb.play_track->fad_start)*cdb.play_track->sector_size;
		buf_fad_offset = dp&0x1ff;
		dp &= ~0x1ff;

		fs_lock();
		//printk("  seek at %08x\n", dp);
		f_lseek(cdb.play_track->fp, dp);
		retv = f_read(cdb.play_track->fp, sector_buffer, 0x8000, (u32*)&nread);
		fs_unlock();
		if(retv==0){
			int num_fad = (nread-buf_fad_offset)/buf_fad_size;
			buf_fad_end = buf_fad_start+num_fad;
		}else{
			SSLOG(_DTASK, "f_read error!\n");
			cdb.status = STAT_ERROR;
			cdb.play_type = 0;
			buf_fad_end = 0;
			return -2;
		}

		wblk->data = sector_buffer+buf_fad_offset;
	}

	wblk->size = buf_fad_size;
	wblk->fad = fad;
	if(buf_fad_size==2352 && wblk->data[0x0f]==0x02){
		wblk->fn = wblk->data[0x10];
		wblk->cn = wblk->data[0x11];
		wblk->sm = wblk->data[0x12];
		wblk->ci = wblk->data[0x13];
	}

	// 处理subcode
	if(cdb.has_subrw && cdb.iflag&0x02 && cdb.status!=STAT_SCAN){
		u8 *sbuf = cdb.subcode_buf+(fad-buf_fad_start)*96;
		for(int i=0; i<4; i++){
			memcpy(cdb.subrw_buf+cdb.subrw_wp*24, sbuf, 24);
			int new_wp = (cdb.subrw_wp+1)%64;
			cdb.subrw_wp = new_wp;
			if(new_wp==cdb.subrw_rp){
				cdb.subrw_rp = (cdb.subrw_rp+1)%64;
			}
			sbuf += 24;
		}
	}

	return 0;
}


/******************************************************************************/


void show_pt(int id)
{
	PARTITION *pt;
	BLOCK *bk;
	int i;

	pt = &cdb.part[id];
	SSLOG(_INFO, "Part_%d: nblks=%d\n", id, pt->numblocks);
	bk = pt->head;
	for(i=0; i<pt->numblocks; i++){
		SSLOG(_INFO, "  %2d: size=%4d fad=%08x data=%08x\n", i, bk->size, bk->fad, bk->data);
		bk = bk->next;
	}
}


void set_peri_report(void)
{
	int irqs;

	irqs = disable_irq();

	if((ST_STAT&0x1000)==0){
		set_report(cdb.status|STAT_PERI);
	}

	restore_irq(irqs);
}


void disk_task(void *arg)
{
	int retv;
	BLOCK wblk;

	cdb.status = STAT_NODISC;
	set_status(cdb.status);

	int wait_ticks = 10;
	int play_wait_count = 0;
	int lazy_play_state = 0;
	while(1){
_restart_wait:
		wait_ticks = (cdb.play_wait || cdb.block_free!=MAX_BLOCKS)? 1: 2;
		retv = osSemaphoreAcquire(sem_wait_disc, wait_ticks);
		if(do_firm_update)
			continue;
		if(retv==osErrorTimeout){
			if(cdb.pause_request){
				goto _restart_nowait;
			}
			if(cdb.play_wait){
				play_wait_count += 1;
				if(play_wait_count==10){
					play_wait_count = 0;
					if(cdb.block_free){
						cdb.play_wait = 0;
						goto _restart_nowait;
					}
				}
			}
			if(next_disc>=0){
				int sd_card_insert(void);
				int sdio_reset(void);
				if(cdb.status==STAT_OPEN){
					if(sd_card_insert()){
						sdio_reset();
						load_disc(next_disc);
						HIRQ = HIRQ_DCHG;
					}
				}else{
					if(sd_card_insert()==0){
						cdb.status = STAT_OPEN;
					}
				}
			}
			HIRQ = HIRQ_SCDQ;
			set_peri_report();

			gif_decode_timer();
			goto _restart_wait;
		}

_restart_nowait:
		if(cdb.pause_request){
			SSLOG(_DTASK, "play_task: Recv PAUSE request!\n");
			cdb.status = STAT_PAUSE;
			cdb.play_type = 0;
			buf_fad_start = 0;
			buf_fad_end = 0;
			cdb.pause_request = 0;
			set_pause_ok();
			goto _restart_wait;
		}
		
		get_sector(cdb.fad, NULL);

		if(cdb.play_fad_start==0 || cdb.play_type==0){
			SSLOG(_DTASK, "play_task: play_type=%d! play_fad_start=%08x!\n", cdb.play_type, cdb.play_fad_start);
			cdb.status = STAT_PAUSE;
			goto _restart_wait;
		}

		if(cdb.play_type!=PLAYTYPE_FILE && cdb.play_track->mode==3){
		}else{
			SSLOG(_DTASK, "\nplay_task! fad_start=%08x(lba_%d) fad_end=%08x fad=%08x type=%d free=%d\n",
					cdb.play_fad_start, cdb.play_fad_start-150, cdb.play_fad_end, cdb.fad, cdb.play_type, cdb.block_free);
		}

		if(cdb.fad==0){
			cdb.fad = cdb.play_fad_start;
		}
		if(cdb.play_type!=PLAYTYPE_FILE && cdb.play_fad_start == cdb.fad){
			if(play_delay){
				int calc_delay = play_delay;
#if 0
				int fadiff = (cdb.old_fad>cdb.fad)? (cdb.old_fad-cdb.fad) : (cdb.fad-cdb.old_fad);
				calc_delay = fadiff/5;
				SSLOG(_DTASK, "calc_delay=%d  fadiff=%d\n", calc_delay, fadiff);
				if(calc_delay>1000)
#endif
				{
					cdb.status = STAT_BUSY;
					hw_delay(10000);
					cdb.status = STAT_SEEK;
					hw_delay(calc_delay);
				}
				lazy_play_state = 1;
			}
		}

		int old_status = cdb.status;
		if(play_delay){
			// SEEK向PLAY状态转换，有一定的延迟。
			if(lazy_play_state==1){
				lazy_play_state = 2;
			}else if(lazy_play_state==2){
				cdb.status = STAT_PLAY;
				lazy_play_state = 0;
			}
		}else{
			if(cdb.status!=STAT_SCAN)
				cdb.status = STAT_PLAY;
		}
		if(old_status!=cdb.status){
			if(cdb.play_track->mode==3){
				cdb.options = 0x00;
			}
		}

		while(cdb.fad<cdb.play_fad_end){
			if(cdb.pause_request){
				SSLOG(_DTASK, "play_task: Recv PAUSE request!\n");
				cdb.status = STAT_PAUSE;
				cdb.play_type = 0;
				cdb.pause_request = 0;
				set_pause_ok();
				goto _restart_wait;
			}

			retv = get_sector(cdb.fad, &wblk);
			if(retv)
				break;
			led_event(LEDEV_CSCT);
			HIRQ = HIRQ_SCDQ;
			set_peri_report();

			if(cdb.play_type!=PLAYTYPE_FILE && cdb.play_track->mode==3){
				int asize = fill_audio_buffer(wblk.data);
				if(asize<0){
					cdb.play_wait = 1;
					goto _restart_wait;
				}
				if(cdb.has_subrw && cdb.iflag&0x02 && cdb.status!=STAT_SCAN){
					if(asize<=4){
						hw_delay(10000);
					}else{
						hw_delay(13500);
					}
				}
			}else
			{
				//printk("filter sector %08x...\n", cdb.fad);
				if(cdb.play_type==PLAYTYPE_SECTOR && sector_delay){
					hw_delay(sector_delay);
				}
				retv = filter_sector(cdb.play_track, &wblk);
				HIRQ = HIRQ_CSCT;

				if(retv==0){
					// 送到某个过滤器成功
				}else if(retv==2){
					SSLOG(_DTASK, "buffer full! wait ...\n");
					// block缓存已满, 需要等待某个事件再继续
					HIRQ = HIRQ_BFUL;
					if(cdb.play_type==PLAYTYPE_FILE){
						HIRQ = HIRQ_EFLS;
					}
					cdb.status = STAT_PAUSE;
					cdb.play_wait = 1;
					goto _restart_wait;
				}else{
					// 无人接收这个扇区
				}
				//printk("filter return %d\n", retv);
			}

			cdb.old_fad = cdb.fad;
			if(cdb.status==STAT_SCAN){
				if(cdb.scan_dir==0){
					cdb.fad += 8;
				}else{
					cdb.fad -= 8;
				}
			}else{
				cdb.fad++;
			}
		}

		SSLOG(_DTASK, "\nplay end! fad=%08x end=%08x repcnt=%d maxrep=%d play_type=%d\n",
				cdb.fad, cdb.play_fad_end, cdb.repcnt, cdb.max_repeat, cdb.play_type);

		if(cdb.fad>=cdb.play_fad_end){
			// 本次play结束
			cdb.play_track = NULL;
			if(cdb.play_type==PLAYTYPE_DIR){
				if(handle_diread()==0){
					// 返回0表示本次dir_read完成
					// 返回1表示需要继续读取下一个扇区
					cdb.status = STAT_PAUSE;
					cdb.play_type = 0;
				}else{
					goto _restart_nowait;
				}
			}else{
				if(cdb.repcnt>=cdb.max_repeat){
					if(pend_delay){
						hw_delay(pend_delay);
						cdb.status = STAT_BUSY;
						hw_delay(pend_delay);
					}
					cdb.status = STAT_PAUSE;
					if(cdb.play_type==PLAYTYPE_FILE){
						HIRQ = HIRQ_EFLS;
					}
					HIRQ = HIRQ_PEND;
					cdb.play_type = 0;
					cdb.index = 0;
				}else{
					if(cdb.repcnt<14)
						cdb.repcnt += 1;
					cdb.old_fad = cdb.fad;
					cdb.fad = cdb.play_fad_start;
					cdb.track = fad_to_track(cdb.fad);
					goto _restart_nowait;
				}
			}
		}

		set_peri_report();
	}
}

static void disk_task_notify(void)
{
	if(cdb.play_wait){
		cdb.play_wait = 0;
		disk_task_wakeup();
	}
}


void disk_task_wakeup(void)
{
	osSemaphoreRelease(sem_wait_disc);
}


void set_pause_ok(void)
{
	osSemaphoreRelease(sem_wait_pause);
}

void wait_pause_ok(void)
{
	osSemaphoreAcquire(sem_wait_pause, 2);
}

void cdc_delay(int ticks)
{
	osDelay(ticks);
}

void cdc_dump(int status)
{
	printk("CDB:\n");
	printk("  status     : %02x\n", cdb.status);
	printk("  block_free : %d\n",   cdb.block_free);
	printk("  fad        : %08x\n", cdb.fad);
	
	if(status){
		cdb.status = status;
	}
}

/******************************************************************************/


void ss_cmd_handle(void)
{
	int retv;
	u32 cmd = SS_CMD;

	//SSLOG(_INFO, "scmd_task: %04x\n", SS_CMD);

	switch(cmd){
	case SSCMD_PRINTF:
		// 输出信息
		printk("%s", (char*)(TMPBUFF_ADDR+0x10));
		SS_CMD = 0;
		break;
	case SSCMD_LISTBIN:
		// 列出bin信息
		retv = list_bins(1);
		SS_ARG = retv;
		SS_CMD = 0;
		break;
	case SSCMD_LISTDISC:
		// 列出镜像信息
		retv = list_disc(SS_ARG, 0);
		SS_ARG = retv;
		SS_CMD = 0;
		break;
	case SSCMD_LOADDISC:
		// Stop Play task
		if(cdb.play_type){
			cdb.pause_request = 1;
			cdb.play_wait = 0;
			disk_task_wakeup();
			do{
				wait_pause_ok();
			}while(cdb.pause_request);
		}

		// 装载镜像
		retv = load_disc(SS_ARG);
		SS_ARG = retv;
		SS_CMD = 0;

		gif_decode_exit();
		break;
	case SSCMD_CHECK:
	{
		// 检查是否有升级固件
		int fpga = (fpga_update(1)==0)? 1: 0;
		int firm = (flash_update(1)==0)? 1: 0;
		SS_ARG = (fpga<<1) | firm;
		SS_CMD = 0;
		break;
	}
	case SSCMD_UPDATE:
	{
		// 固件升级
		int fpga = (fpga_update(0)>=-1)? 0: 1;
		int firm = (flash_update(0)>=-1)? 0: 1;
		SS_ARG = (fpga<<1) | firm;
		SS_CMD = 0;
		break;
	}
	case SSCMD_FILERD:
	{
		FIL fp;
		int offset = *(u32*)(TMPBUFF_ADDR+0x00);
		int size   = *(u32*)(TMPBUFF_ADDR+0x04);
		int baddr  = *(u32*)(TMPBUFF_ADDR+0x08);
		char *name = (char*)(TMPBUFF_ADDR+0x10);
		int retv = f_open(&fp, name, FA_READ);
		if(retv==FR_OK){
			u32 rsize = 0;
			f_lseek(&fp, offset);
			if(size==0)
				size = f_size(&fp);
			u8 *rbuf = (u8*)((baddr&0x00ffffff)|0x61000000);
			retv = f_read(&fp, rbuf, size, &rsize);
			*(u32*)(TMPBUFF_ADDR+0x04) = rsize;
			f_close(&fp);
			SSLOG(_INFO, "\nSSCMD_FILERD: retv=%d rsize=%08x  %s\n", retv, rsize, name);
		}
		SS_ARG = -retv;
		SS_CMD = 0;
		break;
	}
	case SSCMD_FILEWR:
	{
		FIL fp;
		int offset = *(u32*)(TMPBUFF_ADDR);
		int size = *(u32*)(TMPBUFF_ADDR+0x04);
		int baddr  = *(u32*)(TMPBUFF_ADDR+0x08);
		char *name = (char*)(TMPBUFF_ADDR+0x10);
		int flags = (offset==-1)? FA_CREATE_ALWAYS : FA_OPEN_ALWAYS;
		int retv = f_open(&fp, name, flags|FA_WRITE);
		if(retv==FR_OK){
			u32 wsize = 0;
			u8 *wbuf = (u8*)((baddr&0x00ffffff)|0x61000000);
			if(offset<0)
				offset = 0;
			f_lseek(&fp, offset);
			retv = f_write(&fp, wbuf, size, &wsize);
			*(u32*)(TMPBUFF_ADDR+0x04) = wsize;
			f_close(&fp);
			SSLOG(_INFO, "\nSSCMD_FILEWR: retv=%d wsize=%08x  %s\n", retv, wsize, name);
		}
		SS_ARG = -retv;
		SS_CMD = 0;
		break;
	}
	case SSCMD_SSAVE:
		// 保存当前SAVE
		retv = flush_savefile();
		SS_ARG = retv;
		SS_CMD = 0;
		break;
	case SSCMD_LSAVE:
		// 加载指定SAVE
		retv = load_savefile((char*)(TMPBUFF_ADDR+0x10));
		SS_ARG = retv;
		SS_CMD = 0;
		break;
	case SSCMD_SMEMS:
		// 保存当前SMEMS
		retv = flush_smems(SS_ARG);
		SS_ARG = retv;
		SS_CMD = 0;
		break;
	case SSCMD_LMEMS:
		// 加载指定SMEMS块
		retv = load_smems(SS_ARG);
		SS_ARG = retv;
		SS_CMD = 0;
		break;
	case SSCMD_STARTUP: {
		// 土星端启动!

		// 复位buffer
		buf_fad_start = 0;
		buf_fad_end = 0;
		buf_fad_size = 0;
		// 镜像列表
		list_disc(0, 0);

		// 封面数据
		cover_init();

		// 背景音乐
		int audio_repeat = 0;
		retv = load_pcm("/SAROO/bgsound.pcm");
		if(retv){
			retv = load_pcm("/SAROO/bgsound_r.pcm");
			if(retv==0){
				audio_repeat = 1;
			}
		}
		SS_ARG = retv;
		//SS_CMD = 0;
		if(retv==0){
			cdb.play_fad_start = track_to_fad(0x0100);
			cdb.play_fad_end   = track_to_fad(0x0163);
			cdb.track = 0x01;
			cdb.index = 0x00;
			cdb.fad = cdb.play_fad_start;
			cdb.max_repeat = (audio_repeat)? 0x0f : 0x00;
			cdb.repcnt = 0;
			cdb.options = 0x00;
			cdb.pause_request = 0;
			cdb.play_type = PLAYTYPE_SECTOR;
			disk_task_wakeup();
		}

		TIM6->CR1 = 0x0005;
		gif_decode_init();
		break;
	}
	case SSCMD_SELECT: {
		int index = SS_ARG;
		printk("\nSelect %04x\n", index);
		
		if(index&0x8000){
			gif_decode_exit();
		}

		if(index&0x4000){
			gif_decode_init();
		}else{
			load_cover(index);
		}
		break;
	}
	default:
		SSLOG(_INFO, "[SS] unkonw cmd: %04x\n", cmd);
		break;
	}

}


/******************************************************************************/


void sirq_task(void *arg)
{
	u32 stat;

	while(1){
		stat= ST_STAT;
		ST_STAT = stat;
		//printk("  stat=%04x CR1=%04x\n", stat, SSCR1);
		if((stat&0x0007)==0){
			ST_CTRL |= 7;
			osSemaphoreAcquire(sem_wait_irq, osWaitForever);
			continue;
		}

		if(stat&0x0004){
			// 数据传输相关
			trans_handle();
		}

		if(stat&0x0001){
			cdb.cr1 = SSCR1;
			cdb.cr2 = SSCR2;
			cdb.cr3 = SSCR3;
			cdb.cr4 = SSCR4;
			cdc_cmd_process();
		}

		if(stat&0x0002){
			ss_cmd_handle();
		}
		
	}

}

void EXTI1_IRQHandler(void)
{
	EXTI->PR1 = 0x0002;
	ST_CTRL &= ~7;
	//printk("\nST_IRQ!\n");

	osSemaphoreRelease(sem_wait_irq);
}


/******************************************************************************/

osSemaphoreId_t sem_tim6;

void TIM6_DAC_IRQHandler(void)
{
	TIM6->SR = 0;
	osSemaphoreRelease(sem_tim6);
}

void hw_delay(int us)
{
	us = (us+9)/10;
	if(us==0)
		us = 2;
	TIM6->CR1 = 0;
	TIM6->ARR = us;
	TIM6->CNT = 0;
	TIM6->CR1 = 0x000d;

	osSemaphoreAcquire(sem_tim6, osWaitForever);
}

void tim6_init(void)
{
	sem_tim6 = osSemaphoreNew(1, 0, NULL);

	TIM6->CR1 = 0;
	TIM6->PSC = (2000-1); // 200M/2000 = 100k
	TIM6->SR = 0;
	TIM6->DIER = 1;

	NVIC_EnableIRQ(TIM6_DAC_IRQn);
}


void ss_hw_init(void)
{
	// Release FPGA_NRESET
	//GPIOC->BSRR = (1<<5);

	// EXTI1 -> PB1
	SYSCFG->EXTICR[0] &= 0xffffff0f;
	SYSCFG->EXTICR[0] |= 0x00000010;

	EXTI->RTSR1 |= 0x00000002;
	EXTI->FTSR1 &= 0xfffffffd;
	EXTI->IMR1 |= 0x00000002;
	EXTI->PR1   = 0x00000002;

	HIRQ = 0x0be1;
	SSCR1 = ( 0 <<8) | 'C';
	SSCR2 = ('D'<<8) | 'B';
	SSCR3 = ('L'<<8) | 'O';
	SSCR4 = ('C'<<8) | 'K';

	//NVIC_SetPriority(EXTI1_IRQn, 10);
	NVIC_EnableIRQ(EXTI1_IRQn);

	ST_CTRL = 0x0203;

	tim6_init();
}


void ss_sw_init(void)
{
	int i;

	memset(&cdb, 0, sizeof(cdb));

	cdb.status = STAT_PAUSE;
	cdb.fad = 150;
	cdb.ctrladdr = 0x41;
	cdb.track = 1;
	cdb.index = 1;

	cdb.sector_size = 2048;
	cdb.block_free = MAX_BLOCKS;

	for(i=0; i<MAX_BLOCKS; i++){
		cdb.block[i].size = -1;
		cdb.block[i].data = (u8*)(0x2400a000+i*2352);
	}

	u8 *info_buf = (u8*)0x2400a000+MAX_BLOCKS*2352; // 0x72d80

	cdb.FINFO = (u8*)(info_buf+0x00000);
	cdb.TOC  = (u32*)(info_buf+0x00c00);
	cdb.SUBH  = (u8*)(info_buf+0x00da0);
	cdb.tracks = (TRACK_INFO*)(info_buf+0x00e00); // 0x7db80
	memset(cdb.tracks, 0, 100*sizeof(TRACK_INFO));
	cdb.subcode_buf = (u8*)(info_buf+0x0e00+100*sizeof(TRACK_INFO));
	cdb.subrw_buf = cdb.subcode_buf+1536;

	for(i=0; i<MAX_SELECTORS; i++){
		cdb.filter[i].range = 0xffffffff;
		cdb.filter[i].c_false = 0xff;

		cdb.part[i].size = -1;
		cdb.part[i].numblocks = 0;
		cdb.part[i].head = NULL;
		cdb.part[i].tail = NULL;
	}

	cdb.last_buffer = 0xff;
	cdb.cddev_filter = 0xff;
}


void fs_lock(void)
{
	osMutexAcquire(mutex_fs, osWaitForever);
}


void fs_unlock(void)
{
	osMutexRelease(mutex_fs);
}


void saturn_config(void)
{
	FIL fp;
	int retv;
	u32 rv;

	memset((u8*)SYSINFO_ADDR, 0, 0x1000);
	parse_config("/SAROO/saroocfg.txt", NULL);

	if(auto_update){
		int fp, fl;

		fp = fpga_update(1);
		fl = flash_update(1);
		if(fp==-1 && fl==-1){
			// 没有升级文件
			led_event(LEDEV_NONE);
		}else{
			led_event(LEDEV_BUSY);
			if(fp==0){
				fpga_update(0);
			}
			if(fl==0){
				fl = flash_update(0);
				if(fl<-1){
					led_event(LEDEV_FILE_ERROR);
					return;
				}
			}
			led_event(LEDEV_OK);
			return;
		}
	}

	if(debug_flags&0xc0000000){
		led_event(LEDEV_BUSY);
		int cnt = 0;
		while(1){
			retv = mem_test(0x61000000, 0x00800000);
			if(retv){
				led_event(LEDEV_SDRAM_ERROR);
				//return;
			}
			if((debug_flags&0x40000000)==0)
				break;
			cnt += 1;
			printk("  times: %d\n", cnt);
		}
		led_event(LEDEV_NONE);
	}


	// 检查是否有bootrom. 如果有,就加载到FPGA中
	retv = f_open(&fp, "/SAROO/ssfirm.bin", FA_READ);
	if(retv){
		printk("NO bootrom file found!\n");
		led_event(LEDEV_NOFIRM);
		return;
	}
	int fsize = f_size(&fp);
	printk("Found Saturn bootrom file.\n");
	printk("    Size %08x\n", fsize);

	rv = 0;
	retv = f_read(&fp, (void*)FIRM_ADDR, fsize, &rv);
	printk("    f_read: retv=%d rv=%08x\n", retv, rv);
	f_close(&fp);


	// 打开存档文件
	open_savefile();


	// 放置系统信息
	*(u32*)(SYSINFO_ADDR+0x00) = get_build_date(); // 编译日期
	*(u32*)(SYSINFO_ADDR+0x04) = lang_id;          // 菜单语言
	*(u32*)(SYSINFO_ADDR+0x08) = debug_flags;      // 调试选项

	// I2S
	spi2_init();
	spi2_set_notify(disk_task_notify);

	ss_hw_init();
	ss_sw_init();

	sem_wait_irq   = osSemaphoreNew(1, 0, NULL);
	sem_wait_disc  = osSemaphoreNew(1, 0, NULL);
	sem_wait_pause = osSemaphoreNew(1, 0, NULL);
	mutex_fs = osMutexNew(NULL);

	osThreadAttr_t attr;
	memset(&attr, 0, sizeof(attr));

	attr.priority = osPriorityNormal+7;
	osThreadNew(sirq_task, NULL, &attr);

	attr.priority = osPriorityHigh;
	osThreadNew(disk_task, NULL, NULL);

}

/******************************************************************************/

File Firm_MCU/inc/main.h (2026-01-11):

#ifndef _MAIN_H_
#define _MAIN_H_


#include <stm32h7xx.h>
#include <cmsis_os2.h>
#include <string.h>

/******************************************************************************/

typedef unsigned char      u8;
typedef unsigned short     u16;
typedef unsigned int       u32;
typedef signed int         s32;
typedef unsigned  long long u64;
typedef long long s64;



#define in_isr()        __get_IPSR()
#define disable_irq()   __disable_irq()
#define restore_irq(pm) __set_PRIMASK(pm)

#define NOTHING()    __asm volatile("")

/******************************************************************************/

extern int do_firm_update;

u32 get_build_date(void);

void *malloc(uint32_t size);
void free(void *p);
void memcpy32(void *dst, void *src, int len);
int mem_test(u32 addr, int size);


void uart4_init(void);
uint8_t _getc(void);
int  _getc_tmout(int tmout_ms);
void _putc(u8 byte);
void _puts(char *str);
void uart4_puts(char *str);

int printk(char *fmt, ...);
int sprintk(char *sbuf, const char *fmt, ...);
void hex_dump(char *str, void *addr, int size);

void simple_shell(void);

int tiny_xmodem_recv(u8 *dest);



int sdio_init(void);
int sdio_reset(void);

int scan_dir(char *dirname, int level, int (*func)(char *, char*, int));

void spi2_init(void);
void spi2_set_notify(void *handle);
void spi2_trans(u32 data);
int fill_audio_buffer(u8 *data);

void saturn_config(void);


int flash_update(int check);
int fpga_update(int check);
int flash_write_config(u8 *cfgbuf);


/******************************************************************************/

#define MAKE_LEDEVENT(freq, times, flag)  (((flag)<<16) | ((times)<<8) | (freq))

#define LEDEV_NONE              0
#define LEDEV_SD_ERROR          MAKE_LEDEVENT(10, 10, 2)
#define LEDEV_FPGA_ERROR        MAKE_LEDEVENT(10, 20, 2)
#define LEDEV_SDRAM_ERROR       MAKE_LEDEVENT(15, 8,  2)
#define LEDEV_NOFIRM            MAKE_LEDEVENT(15, 3,  1)
#define LEDEV_FILE_ERROR        MAKE_LEDEVENT(15, 5,  1)
#define LEDEV_SCFG_ERROR        MAKE_LEDEVENT(15, 4,  1)
#define LEDEV_CSCT              MAKE_LEDEVENT(7,  1,  0)
#define LEDEV_BUSY              MAKE_LEDEVENT(50, 1,  1)
#define LEDEV_OK                MAKE_LEDEVENT(13, 2,  1)


void led_event(int ev);

/******************************************************************************/

#endif

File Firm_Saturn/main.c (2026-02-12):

/*
 * Sega Saturn cartridge flash tool
 * by Anders Montonen, 2012
 *
 * Original software by ExCyber
 * Graphics routines by Charles MacDonald
 *
 * Creative Commons Attribution-ShareAlike 3.0 Unported (CC BY-SA 3.0)
 */

#include "main.h"
#include "smpc.h"
#include "vdp2.h"

/**********************************************************/

u32 mcu_ver;
u32 debug_flag;
int bios_type;

/**********************************************************/


u32 BE32(void *ptr)
{
	u8 *b = (u8*)ptr;
	return (b[0]<<24) | (b[1]<<16) | (b[2]<<8) | b[3];
}


u32 LE16(void *ptr)
{
	u8 *b = (u8*)ptr;
	return (b[1]<<8) | b[0];
}


u32 LE32(void *ptr)
{
	u8 *b = (u8*)ptr;
	return (b[3]<<24) | (b[2]<<16) | (b[1]<<8) | b[0];
}

void LE32W(void *ptr, u32 val)
{
	u8 *b = (u8*)ptr;
	b[0] = (val>> 0)&0xff;
	b[1] = (val>> 8)&0xff;
	b[2] = (val>>16)&0xff;
	b[3] = (val>>24)&0xff;
}


/**********************************************************/


static int pad_state;

int pad_read(void)
{
	u32 bits=0, bits1=0;
	u8 *oreg;
	int p;

#ifdef PADMODE_DIRECT
	PDR1 = 0x60; bits |= (PDR1 & 0x8) << 0;
	PDR1 = 0x40; bits |= (PDR1 & 0xf) << 8;
	PDR1 = 0x20; bits |= (PDR1 & 0xf) << 12;
	PDR1 = 0x00; bits |= (PDR1 & 0xf) << 4;
    bits ^= 0xfFF8;
#else
	if(pad_state==0){
		if((TVSTAT&0x0008)==0)
			return -1;
		while(SF&0x01);
		SF = 0x01;
		IREG0 = 0x00;
		IREG1 = 0x08;
		IREG2 = 0xf0;
		COMREG = 0x10;
		pad_state = 1;
		return -1;
	}else if(pad_state==1){
		if(SF&1){
			return -1;
		}

		oreg = (u8*)0x20100021;
		p = 0;

		// read PAD1
		if(oreg[p]==0xf1){
			bits = (oreg[p+4]<<8) | (oreg[p+6]);
			bits ^= 0xFFFF;
			p += (oreg[p+2]&0x0f)*4;
		}else{
			p += 2;
		}
		// read PAD2
		if(oreg[p]==0xf1){
			bits1 = (oreg[p+4]<<8) | (oreg[p+6]);
			bits1 ^= 0xFFFF;
			bits |= bits1;
		}

		IREG0 = 0x40;
		pad_state = 2;
	}else if(pad_state==2){
		if((TVSTAT&0x0008)==0){
			pad_state = 0;
		}
		return -1;
	}
#endif

	//printk("pad_read: %04x\n", bits);
	return bits;
}


void pad_init(void)
{
	pad_state = 0;

#ifdef PADMODE_DIRECT
    PDR1 = 0;
    DDR1 = 0x60;
    IOSEL = IOSEL1;
#else
	DDR1 = 0;
	DDR2 = 0;
	EXLE = 0;
    IOSEL = 0;

	IREG0 = 0x00;
	IREG1 = 0x08;
	IREG2 = 0xf0;
#endif
}


/**********************************************************/

int smpc_cmd(int cmd)
{
	printk("SMPC_CMD(%02x) ...\n", cmd);
	// wait busy state
	while(SF&0x01);

	SF = 0x01;
	COMREG = cmd;
	while(SF&0x01);

	printk("    done. SS=%02x\n", SR);
	return SR;
}

/**********************************************************/


void stm32_puts(char *str)
{
	u32 stm32_base = TMPBUFF_ADDR;
	int len;

	len = strlen(str);
	LE32W((void*)(stm32_base+0), len);

	memcpy((void*)stm32_base+0x10, str, len+1);

	SS_CMD = 0x0001;
	while(SS_CMD);
}


/**********************************************************/

#if 0
const int HZ = 1000000;

void reset_timer(void)
{
	SS_TIMER = 0;
}

u32 get_timer(void)
{
	return SS_TIMER;
}

#else

const int HZ = 208496; /* for NTSC: 320 lines mode */
static int timer_base;

void reset_timer(void)
{
	timer_base = 0;
	TCR = 0x02;
	FRCH = 0;
	FRCL = 0;
}

u32 get_timer(void)
{
	int s1, s2, th, tl;
	while(1){
		s1 = FTCSR&0x02;
		th = FRCH;
		tl = FRCL;
		s2 = FTCSR&0x02;
		if(s1==s2)
			break;
	}

	th = (th<<8) | tl;
	if(s2&0x02){
		timer_base += 65536;
		FTCSR = 0;
	}

	return timer_base+th;
}

#endif


void usleep(u32 us)
{
	u32 now, end;

	if(us==0)
		us = 1;
	end = (us*HZ)/1000000;

	reset_timer();
	while(1){
		now = get_timer();
		if(now>=end)
			break;
	}
}

void msleep(u32 ms)
{
	u32 now, end;

	if(ms==0)
		ms = 1;
	end = (ms*HZ)/1000;

	reset_timer();
	while(1){
		now = get_timer();
		if(now>=end)
			break;
	}
}

/**********************************************************/

// clk = 26874880
// bps = ((clk/32)/n)/(BRR+1)

void sci_init(void)
{
	SCR = 0x00;     /* set TE,RE to 0 */
	SMR = 0x00;     /* set SMR to 8n1 async mode */
//	BRR = 0x15;     /* set BRR to 9600 bps */
//	BRR = 0x01;     /* set BRR to 104980 bps */
	BRR = 0x00;     /* set BRR to 209960 bps */
	SCR = 0xcd;     /* set TIE RIE MPIE TEIE CKE1 CKE0 */
	SCR = 0x31;     /* set TE RE to 1 */

	printk_putc = sci_putc;
}

void sci_putc(int ch)
{
	while((SSR&0x80)==0);
	TDR = ch;
	SSR &= 0x7f;
}

int sci_getc(int timeout)
{
	int ch;

	timeout *= 1500;
	while(timeout){
		if(SSR&0x40){
			ch = RDR;
			SSR &= 0xbf;
			return ch;
		}
		timeout -= 1;
	}

	return -1;
}


/**********************************************************/


void cpu_dmemcpy(void *dst, void *src, int size, int ch)
{
	int chcr = 0x5a11;

	if(((u32)src&0xfff8703f)==0x25800000){
		// CDBLOCK的DATA_PORT
		chcr &= 0xcfff;
	}

	while((CHCR0&0x03)==0x01);
	CHCR0 = 0;
	DMAOR = 1;

	SAR0 = (u32)src;
	DAR0 = (u32)dst;
	TCR0 = (size+3)>>2;
	CHCR0 = chcr;
}

#if 1
void scu_dmemcpy(void *dst, void *src, int size, int ch)
{
	volatile SCUDMA_REG *sdma = (SCUDMA_REG *)(SCU_DMA_BASE+ch*0x20);
	int mask  = 0x0030;
	int maskh = 0x0001;

	if(ch>0){ mask <<= 4; maskh <<= 1; }
	if(ch>1){ mask <<= 4; maskh   = 0; }
	mask |= maskh<<16;
	while(SDSTAT&mask); // 等待传输结束

	sdma->src = (u32)src;
	sdma->dst = (u32)dst;
	sdma->count = size;
	sdma->addv = (((u32)dst&0x00f00000)==0) ? 0x102 : 0x101;
	sdma->mode = 0x07;
	sdma->enable = 0x101;
}

#else

void scu_dmemcpy(void *dst, void *src, int size, int ch)
{
	while(SDSTAT&0x10030); // 等待传输结束

	SD0R = (u32)src;
	SD0W = (u32)dst;
	SD0C = size;
	SD0AD = (((u32)dst&0x00f00000)==0) ? 0x102 : 0x101;
	SD0MD = 0x07;
	SD0EN = 0x101;
}

#endif

/**********************************************************/

int read_file (char *name, int offset, int size, void *buf)
{
	LE32W((void*)(TMPBUFF_ADDR+0x00), offset);
	LE32W((void*)(TMPBUFF_ADDR+0x04), size);
	strcpy((void*)(TMPBUFF_ADDR+0x10), name);

	u32 bus_addr = (u32)buf & 0x0fffffff;
	if(bus_addr>=0x02000000 && bus_addr<0x03000000){
		// buf位于MCU和SS可以直接访问的空间内。
		LE32W((void*)(TMPBUFF_ADDR+0x08), bus_addr);
	}else{
		// buf不可直接访问，必须中转。
		LE32W((void*)(TMPBUFF_ADDR+0x08), TMPBUFF_ADDR+0x0100);
	}


	SS_ARG = 0;
	SS_CMD = SSCMD_FILERD;
	while(SS_CMD);

	int retv = (signed short)SS_ARG;
	if(retv<0)
		return retv;

	size = LE32((void*)(TMPBUFF_ADDR+0x04));
	if(bus_addr<0x02000000 || bus_addr>=0x03000000){
		memcpy(buf, (void*)(TMPBUFF_ADDR+0x0100), size);
	}

	return size;
}


int write_file(char *name, int offset, int size, void *buf)
{
	LE32W((void*)(TMPBUFF_ADDR), offset);
	LE32W((void*)(TMPBUFF_ADDR+0x04), size);
	strcpy((void*)(TMPBUFF_ADDR+0x10), name);

	u32 bus_addr = (u32)buf & 0x0fffffff;
	if(bus_addr>=0x02000000 && bus_addr<0x03000000){
		// buf位于MCU和SS可以直接访问的空间内。
		LE32W((void*)(TMPBUFF_ADDR+0x08), bus_addr);
	}else{
		// buf不可直接访问，必须中转。
		LE32W((void*)(TMPBUFF_ADDR+0x08), TMPBUFF_ADDR+0x0100);
		memcpy((void*)(TMPBUFF_ADDR+0x0100), buf, size);
	}


	SS_ARG = 0;
	SS_CMD = SSCMD_FILEWR;
	while(SS_CMD);

	int retv = (signed short)SS_ARG;
	if(retv<0)
		return retv;

	size = LE32((void*)(TMPBUFF_ADDR+0x04));
	return size;
}


/**********************************************************/
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

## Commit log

2015-06-07 First commit: Add HW files
    [FPGA_parts.SchDoc, Power.SchDoc, SDRAM.SchDoc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]
2015-06-08 Add STM32 code
2015-11-09 PCB version increase 1.1 to 1.2 PCB requirements relaxing (6 mil at top/bot, 8 mil internal, via 20/8mil) USB connector at STM32 added
    [Power.SchDoc, STM32.SchDoc, Saturn_Cartage.SchDoc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]
2023-02-13 add v12 file
    [FPGA_parts.SchDoc, Power.SchDoc, SDRAM.SchDoc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]
2023-03-18 1. send PERI_REPORT/HIRQ_SCDQ when buffer has data 2. set_sector_length fixup 3. get_[del_]sector_data fixup 4. single iso file support
    [saturn_main.c]
2023-03-25 1.Read pad by SMPC 2.Add key repeat mode 3.Add File R/W from SD 4.CDC bugfix
    [main.c, main.h, saturn_main.c]
2023-04-02 add put_sector_data reset_filter fixup get_del_sector_data fixup
    [SSMaster.v, main.c, saturn_main.c]
2023-04-10 add config file add log system put_sector_data fixup
    [saturn_main.c]
2023-06-06 Update HW to v13(bugfix) Change directory structs
    [FPGA_parts.SchDoc, Power.SchDoc, SDRAM.SchDoc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]
2023-10-05 1. 实现"加载二进制文件"功能 2. 增加了几个配置文件选项 3. GUI会显示各个固件的版本信息 4. 游戏兼容性些许提升
2023-10-11 1. 增加SYSINFO区域 2. 初步实现多语言功能
2023-10-11 增加led闪烁提示功能
2023-10-26 1.增加play_delay参数 2.增加日语和葡萄牙语支持 3.增加存档功能
2023-10-31 1. MCU端开机内存测试功能 2. MCU端固件自动更新 3. 支持启动光盘游戏
2023-11-06 Update language.c
    修正日语提示
2023-11-11 FPGA bugfix MCU bugfix
    [SSMaster.v, main.c, main.h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]
2023-11-25 更改固件加载方式
2023-12-06 bootloader错误修正 增加存储卡功能
2023-12-10 bootloader错误修正 cdplayer修正
2024-01-17 SD卡：增加写重试
2024-01-17 土星端扩展存储卡支持
2024-01-17 增加KOF95与UltraMan的支持
2024-01-17 提升1.00BIOS的兼容性
2024-01-29 The game Bug has a problem that freezes in the first stage and with this delay it fixes this problem
2024-03-11 增加游戏中换盘功能
2024-03-11 调整延时参数的范围: 65535->655350
2024-03-11 1. 字体系统更新，使用变宽字体。CJK部分使用文泉驿点阵字体。 2. 增加菜单内容超长滚动显示功能。 3. 增加俄语与繁体中文翻译。 4. 主菜单中LT键切换语言。 5. 改进Makefile
2024-03-11 更新game_patch
2024-03-11 增加德语支持。
2024-03-11 更新配置文件
2024-03-11 忽略cue文件中的FLAGS标记。
2024-03-11 init_cdblock增加HIRQ_EHST返回值。 移除为InTheHunt做的hack代码。
2024-03-11 添加字体生成工具
2024-03-13 更新saroocfg.txt
2024-03-15 调整版本号的间距
2024-03-18 修正德语翻译
2024-05-04 增加copy/move sector功能
2024-05-04 切换240p显示模式
2024-05-04 优化菜单滚动显示
2024-05-04 disk_io增加锁保护。
2024-05-04 增加背景图片功能(gif) 增加背景音乐功能
2024-05-04 调整内存布局
2024-05-04 增加游戏排序功能
2024-05-04 增加游戏分类显示功能
2024-05-04 9球界面，按Start返回SAROO菜单。 按C使用系统存档
2024-05-04 增加pend_delay参数(Play end delay)
2024-05-04 实现特殊的SEEK到PLAY的状态转换
2024-05-07 更新语言文件
2024-05-08 qsort4修正
2024-05-15 hook_getkey兼容更多的BIOS版本
2024-05-16 Update language.c
    Correct translation in spanish
    [language.c]
2024-06-22 支持多个INDEX的镜像。
2024-06-22 读写文件时加锁，以避免同时访问导致SD卡损坏。
2024-06-22 更加灵活的gameid匹配方式
2024-06-22 修复cdb.options的处理机制。
2024-06-22 优化read_file/write_file，去掉无用的数据搬运
2024-06-27 忽略POSTGAP 增加cat_dir大小
2024-06-27 更新language.c
2024-06-28 修复read_file的bug
2024-10-12 增加常用日文汉字编码 增加希腊语字库
2024-10-13 优化按键轮询的间隔时间
2024-10-13 启动时显示SAROO的logo
2024-10-13 使用dma优化memcpy
2024-10-13 优化菜单显示
2024-10-13 支持系统存档与外置存储卡共存
2024-10-13 支持V-Saturn 1.00的BIOS
2024-10-13 增加显示游戏封面功能
2024-12-21 忽略cue中不支持的tag
2024-12-21 修复背景与封面偶尔冲突的bug
2024-12-21 增加刻录盘的支持
2024-12-21 BIOS兼容性增强
2024-12-21 按Z以系统光驱模式加载二进制文件
2024-12-21 更新sysid，支持全区域运行
2024-12-21 增加区域文件
2024-12-21 自动建立obj目录
2024-12-22 调整封面数据的校验和
2024-12-22 增加非游戏文件的处理
2024-12-23 封面显示bugfix
2024-12-23 检测LOADDISC的返回值
2025-12-06 通过串口更新固件
2025-12-06 实现CDG播放功能
2025-12-06 支持2P手柄操作
2025-12-06 Makefile支持静默编译
2025-12-06 更新gamepatch
2025-12-06 正确设置HIRQ初值，否则某些游戏加载失败
2025-12-06 增加cdgtools 增加cpktools
2025-12-06 更新MCU工程文件
2026-01-11 完善串口更新固件的代码
2026-01-11 修复播放背景音乐时无背景图片的bug
2026-01-11 更改fifo_rcnt的获取方式
2026-01-11 FPGA:修复两端同时访问HIRQ时的bug
2026-01-28 FPGA可检测SS_SCLK状态
2026-02-12 实现SCAN命令
2026-02-12 双手柄bugfix
2026-02-12 增加版本说明
2026-02-12 加载游戏时需要额外的初始化
2026-08-29 Fix out-of-bounds language hash table access
    [language.c]
2026-10-28 MCU: 增加 SSCMD_STVLOAD / SSCMD_ROMCTL，用于在 HW1.3 上运行 ST-V 游戏
    - SSCMD_STVLOAD (0x40)：与 FILERD 类似，目标地址可覆盖 CS0 后面完整的
    32MB SDRAM，按 16MB 切换 FMC bank（ST_CTRL[11:10]），结束后恢复 bank 0。
    - SSCMD_ROMCTL (0x41)：SS_ARG bit0 开关 CS0 AA24 寻址（FPGA 06 的
    st_reg_ctrl[12]），返回 ST_CTRL[15:8]。
    - SSCMD_STARTUP 时清除 AA24 与 bank 选择，普通游戏不受影响。
    via [HAPI](https://hapi.run)
